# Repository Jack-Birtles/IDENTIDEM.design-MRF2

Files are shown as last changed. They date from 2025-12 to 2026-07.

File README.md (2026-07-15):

# IDENTIDEM.design M(edium Format) (R)ange(F)inder Two (MRF2)

Build Guide (https://www.youtube.com/watch?v=_sIWXoqOFIU)

MRF2 is version two of an open hardware / open firmware medium-format rangefinder camera for **Mamiya Press / Universal Press lenses**. It combines custom PCBs, ESP32-S3 firmware, LiDAR-based lens coupled focusing, dual OLED displays, and printed mechanical parts so you can build a fully featured medium-format shooter with configurable lens profiles and film formats.

It is based on the [Panomicron Thulium](https://www.panomicron.com/thulium) designed by Oscar Oweson, has been heavily modified, but has kept the best ideas from that camera.

Keep checking back regularly as I keep making improvements as I use my own copy of this camera. 
You can [support me on Patreon](https://patreon.com/IDENTIDEMdesign), or just show me your builds and the photos you're making with the camera!

## Repo at a Glance

- `Firmware/` – ESP32-S3 Arduino firmware (full details in `Firmware/README.md`)
- `PCBs/` – KiCad projects + production Gerbers, in two supported revisions (see **Which board version?** below):
  - `PCBs/v2.0/` (MRF-Pro-v8) – adds a dedicated low-noise LiDAR regulator on the breakout, and reworks the main board's FPC power delivery and switch: v1's FPC pins weren't wired to a real power rail at all (one was a spare Feather GPIO); v2 fixes that and adds full deterministic shutdown.
  - `PCBs/v1.0/` (MRF-Pro-v7.5) – simpler boards; great for short-range and landscape use.
  - Each revision holds `Main PCB/` (main board) and `Breakout/` (sensor breakout) sub-folders.
- `3MF/` – Print-ready 3MF files organized by part type (body, accessories, masks, fine parts)
- `STEP & F3D/` – Full assembly CAD (`MRF2-complete.f3d`) and shared STEP export (`MRF2-complete.step`)
- `OrcaSlicer/` – Slicer project files/profiles for printing

## Documentation Index

- `Documentation/flash-firmware/README.md` – Building and flashing the firmware on macOS, Linux, and Windows (VS Code or CLI)
- `Documentation/web-updater/README.md` – GitHub Pages browser updater architecture and deployment
- `Documentation/user-manual/USER_MANUAL.md` – On-device UI and calibration user manual
- `Documentation/wiring/README.md` – Power-switch/buttons and breakout-to-LiDAR harness wiring diagrams, for both board revisions
- `Firmware/README.md` – Firmware architecture, configuration, and CLI build commands

## Camera Features

- "LiDAR" distance measurement for accurate focus
- Dual OLED UI: 128×128 main in-viewfinder display + 128×32 external status display
- Light meter & exposure calculation for multiple ISO values
- Lens coupled via a high-accuracy linear position sensor
- Electronic frame counting using a rotary encoder
- Battery monitoring and on-device configuration, like in-camera lens calibration

## Which board version: v1 or v2?

Two board revisions are supported, and **the latest firmware runs on both, unchanged** — there are no board-specific builds, pin maps, or config flags. Connectors, sensors, displays, optics, printed parts, and the main board's component placement and outline are common to both, **but the main board's LiDAR power delivery was significantly reworked, alongside the breakout hardware.** On v1, schematic capture found the FPC connector's power pins weren't wired to a real power rail at all — pin 1 was tied to a Feather **GPIO (D11)** and pin 6 to an undefined private net, so the Feather's actual 3.3 V never reached the breakout, likely worsening the laser-pulse brownout this respin fixes. v2 corrects it: pin 1 now carries real `VBAT`, pin 6 carries a properly gated `3.3OUT`, and the GPIO is freed. Choose by the LiDAR range you need:

| | **v1 — MRF-Pro-v7.5** (`PCBs/v1.0/`) | **v2 — MRF-Pro-v8** (`PCBs/v2.0/`) |
| --- | --- | --- |
| Breakout | Bare — just the three connectors | Same connectors **+ a dedicated LiDAR LDO** (8 extra SMD parts) |
| FPC power delivery (main board) | Pin 1 wired to a Feather **GPIO (D11)**, pin 6 an undefined private net — the Feather's regulated 3.3 V never actually reached the FPC | Pin 1 carries real **`VBAT`**, pin 6 carries a gated, switched **`3.3OUT`** — the breakout's LDO finally gets the power path it needs |
| LiDAR power | Shared Feather 3.3 V rail, no decoupling at the sensor | Isolated low-noise 3.3 V regulated **at the sensor** (TLV75533 off VBAT) |
| LiDAR range | Good up close and at landscape distance; **falls off at mid distance and in bright ambient** | **Full rated range indoors and in shade; direct sun still caps range** (~3 m on a sunlit target — a sensor optics limitation, not power-related; no board revision or firmware fixes it) |
| Power switch (main board) | Basic on/off — single shared 3.3 V net through J4 | Reworked **J4 DPDT**, two independent poles (gate `3.3OUT`; hold MCU `EN` low) for full deterministic shutdown (≤1 µA off) — same connector, board outline, and component placement, traces rerouted |
| Build effort | **Lowest** — breakout is a bare board, no SMD assembly | A bit more — breakout is an SMD assembly job (JLCPCB BOM/CPL provided) |
| Best for | Portraits ~1–3 m and landscapes; the cheapest, easiest build | Full-range focus indoors and in shade, better (not unlimited) in direct sun — the fuller-featured build |

- **Pick v1** for the simplest, cheapest build if you mostly shoot within a few metres or at landscape distances. Its LiDAR range can still be improved with the [hand-solder decoupling stopgap](Documentation/hardware-errata/lidar-stage1-decoupling.md), a v1-only remedy that v2 builds in.
- **Pick v2** for the sensor's full distance range indoors and in shade, deterministic power-off, and a main board that actually delivers real power to the LiDAR breakout, at the cost of the extra SMD parts on the breakout. Direct bright sun still caps range on either revision — that's the sensor fighting solar infrared at its own wavelength, not a supply problem this board fixes. The [LiDAR power errata](Documentation/hardware-errata/README.md) explains the why, and [field test protocol](Documentation/hardware-errata/lidar-field-test.md) covers all three lighting conditions including direct sun.

Building either? See the **[wiring guide](Documentation/wiring/README.md)** for the power-switch/buttons harness and breakout-to-LiDAR harness diagrams, per revision.

## Build Path (high level)

1. **Order PCBs**: Pick your version (see [Which board version?](#which-board-version-v1-or-v2)), then upload the Gerbers from that revision's `Main PCB/Gerber` and `Breakout/Gerber` folders — the `.gbrjob` files go straight to most fabs. For v2, the breakout is also an assembly job (the LDO SMD parts); its JLCPCB BOM/CPL live in `PCBs/v2.0/Breakout/JLCPCB/`.
2. **Assemble electronics**: Populate the main and breakout boards with the BoM below (through-hole and SMT mix), attach the Feather ESP32-S3, and wire the displays/sensors via STEMMA QT/Qwiic where applicable.
3. **Print the body**: Slice/print the 3MF models (see `3MF/` and any profiles in `OrcaSlicer/`). Fit tolerances may depend on your printer and material.
4. **Load firmware**: Follow `Documentation/flash-firmware/README.md` (macOS/Linux/Windows, VS Code or CLI), then run first-time calibration.
5. **Integrate**: Install the PCBs and displays into the printed parts, route wiring, and verify focus/meters on the bench before loading film.

## Bill of Materials

Marketplace listings (Amazon/AliExpress) change frequently. Treat those links as examples and verify specs before ordering.

### Electronics

| Item | Qty | Notes | Example sources |
| --- | --- | --- | --- |
| Feather ESP32-S3 (Adafruit 5477) | 1 | Main MCU, MAX17048 fuel gauge, 4MB flash / 2MB PSRAM | [Adafruit](https://www.adafruit.com/product/5477) |
| MRF2 Main PCB | 1 | Use Gerbers in your chosen revision's `Main PCB/Gerber` (`PCBs/v2.0/` or `PCBs/v1.0/`) | Any fab |
| MRF2 Breakout PCB | 1 | Use Gerbers in your chosen revision's `Breakout/Gerber`. **v2 breakout is an SMD assembly job** (see the LDO parts below) | Any fab |
| B-type 8-pin FPC ribbon cable | 1 | Links main PCB to breakout | [Amazon](https://www.amazon.co.uk/sourcing-map-Ribbon-Flexible-Printer/dp/B0F4K1KMKR/) |
| 8-pin JST-SH cable | 1 | For power switch and buttons, 10cm should be plenty | [AliExpress Search](https://www.aliexpress.com/w/wholesale-8-pin-jst%252525252dsh-cable.html) |
| 6-pin JST-SH cable | 1 | Connect the LiDAR sensor to the breakout board - some cutting and soldering needed on the connector supplied with the sensor | [AliExpress Search](https://www.aliexpress.com/w/wholesale-6-pin-jst%252525252dsh-cable.html) |
| LiDAR DTS6012M | 1 | Distance sensing | [AliExpress search](https://www.aliexpress.com/wholesale?SearchText=DTS6012M+UART) |
| 404R10KL1.0 Linear-position sensor | 1 | Lens position sensor | [Newark](https://www.newark.com/tt-electronics-bi-technologies/404r10kl1-0/linear-motion-potentiometer-10kohm/dp/15M2426) |
| Light sensor BH1750 breakout (Adafruit 4681) | 1 | Lux readings | [Adafruit](https://www.adafruit.com/product/4681) |
| IMU MPU6050 breakout (Adafruit 3886) | 1 | Orientation | [Adafruit](https://www.adafruit.com/product/3886) |
| ADC ADS1015 breakout (Adafruit 1083) | 1 | Lens position | [Adafruit](https://www.adafruit.com/product/1083) |
| STEMMA QT Rotary Encoder (Adafruit 5880) | 1 | Film advance tracking | [Adafruit](https://www.adafruit.com/product/5880) |
| 1.12" 128×128 SH1107 OLED (Adafruit 5297) | 1 | Main display | [Adafruit](https://www.adafruit.com/product/5297) |
| 128×32 SSD1306 OLED (I2C) | 1 | External status display | [AliExpress search](https://www.aliexpress.com/w/wholesale-128x32-oled-display-ssd1306.html) |
| JST-SH/Qwiic/STEMMA QT cables | 6-8 (extras if you want to shorten / modify) | I2C daisy-chain and encoder | [Adafruit](https://www.adafruit.com/product/4210) |
| LiPo cell (3.7V, 820mAh) - 44 x 30.5 x 6.8 mm | 1 | **CHECK POLARITY** | [Amazon](https://www.amazon.co.uk/dp/B082152887) |
| 8mm momentary button | 2 | Select buttons | [Amazon](https://www.amazon.co.uk/dp/B07S1MNB8C) |
| 6mm DPDT slide switch | 1 | Power switch | [Amazon](https://www.amazon.co.uk/dp/B07H9VPK1J) |

### Components for custom PCBs — connectors (both versions)

The same connectors populate v1 and v2:

| Item | Qty | Notes | Example sources |
| --- | --- | --- | --- |
| 0.5mm pitch 8-pin FPC connector (FPC-05F-8PH20, C2856797) | 2 | One on the main PCB, one on the breakout | [JLCPCB](https://jlcpcb.com/partdetail/XUNPU-FPC_05F8PH20/C2856797) |
| SH 1.0mm 8-pin connector (ZX-SH1.0-8PWT, C7430450) | 1 | Main board J4 — power switch and buttons | [JLCPCB](https://jlcpcb.com/partdetail/Megastar-ZX_SH1_08PWT/C7430450) |
| SH 1.0mm 6-pin connector (ZX-SH1.0-6PWT, C7430448) | 1 | Breakout J7 — LiDAR sensor | [JLCPCB](https://jlcpcb.com/partdetail/Megastar-ZX_SH1_06PWT/C7430448) |
| SH 1.0mm 4-pin connector (ZX-SH1.0-4PWT, C7430446) | 1 | Breakout J6 — STEMMA QT | [JLCPCB](https://jlcpcb.com/partdetail/Megastar-ZX_SH1_04PWT/C7430446) |

### v2 breakout only — dedicated LiDAR regulator

These SMD parts populate the v2 breakout's LDO (the extra cost/effort over v1). **v1's breakout has none of these** — it just carries the connectors above. Full design background is in the [LiDAR power errata](Documentation/hardware-errata/README.md).

| Ref | Part | LCSC | Role |
| --- | --- | --- | --- |
| U1 | TLV75533 LDO, SOT-23-5 | C404027 | Dedicated 3.3 V regulator for the LiDAR |
| Cin1 | 1 µF, 0402 | C52923 | LDO input decoupling |
| Cin2 | 10 µF, 0805 | C15850 | LDO input bulk |
| C1 | 47 µF, 1206 | C96123 | Laser-rail bulk (at the sensor's laser pin) |
| C2 | 1 µF, 0603 | C15849 | LDO output stability |
| C3 | 100 nF, 0402 | C1525 | High-frequency bypass |
| FB1 | 0 Ω jumper, 0805 | C17477 | Splits the logic/laser rails (fit a ferrite later if needed) |
| R1 | 100 kΩ, 0402 | C25741 | LDO enable pulldown (clean power-off) |

### Hardware

| Item | Qty | Notes | Example sources |
| --- | --- | --- | --- |
| Heat-set inserts | as needed | M2x4 & M3x4 | Local fasteners supplier |
| Countersunk screws | as needed | M2x4, M2x6, M3x6, M3x8 countersunk screws | Local fasteners supplier |
| M3x6 thumb screw | 1 | To hold the door closed | Local fasteners supplier |
| Steel rod - for door hinge | 1 | Cut to length: ~82mm | [Amazon](https://www.amazon.co.uk/HXJDAM-Stainless-Steel-Round-Diameter/dp/B0D2V6WB1Y) |
| 2-turn door handle spring | 1 | For advance lever auto-return | [Amazon](https://www.amazon.co.uk/dp/B076VRBT4M) |
| CSK8PP one-way bearing / sprag clutch | 1 | For advance lever, make sure inner and outer are keyed | [AliExpress Search](https://www.aliexpress.com/w/wholesale-CSK8PP.html) |
| Cold shoe | 1 | Mount on top | [Amazon](https://www.amazon.co.uk/Anwenk-Adapter-Bracket-Standard-Monitor/dp/B01MD29V3X) |
| 20x5x2mm bar magnets | as needed | 1 for the body, 1 for each mask you print | [Amazon](https://amzn.eu/d/ejitdei) |
| 5x2mm round magnets | 2 | 1 for the body, 1 for the key | [Amazon](https://www.amazon.co.uk/100PCS-Magnets-Neodymium-Whiteboards-Picture/dp/B09H2W3TQZ) |

### Optics

| Item | Qty | Notes | Example sources |
| --- | --- | --- | --- |
| 20.0mm Dia. x 70.0mm FL plano-convex lens (PCX) | 1 | Rear viewfinder lens | [Edmund Optics](https://www.edmundoptics.co.uk/p/200mm-dia-x-700mm-fl-uncoated-plano-convex-lens/2705) |
| 25.0mm Dia. x -25 FL plano-concave lens (PCV) | 1 | Front viewfinder lens | [Edmund Optics](https://www.edmundoptics.co.uk/p/250mm-dia-x25-fl-uncoated-plano-concave-lens/5542/) |
| 30x30x1.1mm 50R/50T beam splitter | 1 | Sits between front and rear optics | [AliExpress Search](https://www.aliexpress.com/w/wholesale-30x30x1.1-50R%25252F50T-beam-splitter.html) |

## Cost Estimate (ballpark)

Assumes single-quantity retail buys (Adafruit/Amazon/AliExpress), optics from Edmund Optics, and a rough USD/GBP conversion; excludes shipping/VAT/import and assembly labor.

- Electronics (MCU, sensors, displays, cables, LiPo, switches): ~$125 / ~£100
- PCB share (DIY assembly; amortized per build): ~$10 / ~£6  \[full 5× PCB batch ~ $35 / £28\]
- Hardware/fasteners/mech bits: ~$25 / ~£20
- Optics (lenses + beam splitter): ~$115 / ~£90
- Printed parts material: ~$25 / ~£20
- Rough per-build total: ~$300 / ~£235 (add shipping/taxes and any PCB batch overhead you keep)

## CAD & Printed Parts

- Full assembly in `STEP & F3D/MRF2-complete.f3d` (Fusion 360) and `MRF2-complete.step` (generic).
- Print-ready 3MFs are grouped by function under `3MF/`. Use provided slicer profiles in `OrcaSlicer/` as a starting point and tweak for your printer/material.

## PCB Notes

- Open the KiCad projects for your revision: **v2** `PCBs/v2.0/Main PCB/KiCAD/MRF-Pro-v8.kicad_pro` + `PCBs/v2.0/Breakout/KiCAD/MRF-Pro-v8-breakout.kicad_pro`; **v1** `PCBs/v1.0/Main PCB/KiCAD/MRF-Pro-v7.5.kicad_pro` + `PCBs/v1.0/Breakout/KiCAD/MRF-Pro-v7.5-breakout.kicad_pro`.
- Fabrication: the provided Gerber sets include copper, mask, paste, silkscreen, drills, and a `.gbrjob` for auto-detection at most PCB fabs.
- Revs: `PCBs/v2.0/` (`MRF-Pro-v8`) adds the dedicated LiDAR LDO on the breakout and reworks the main board's LiDAR power delivery: v1's FPC pin 1 was wired to a spare Feather GPIO (D11) rather than a real rail and pin 6 was an undefined private net, so the Feather's 3.3 V never reached the breakout; v2 rewires them to `VBAT`/`3.3OUT` and splits the J4 switch into a DPDT for full deterministic shutdown (same component placement and board outline, traces rerouted). `PCBs/v1.0/` (`MRF-Pro-v7.5`) is the simpler, unfixed original design. See [Which board version?](#which-board-version-v1-or-v2) and the [LiDAR power errata](Documentation/hardware-errata/README.md) for the design background.

## Firmware

Firmware source and build instructions live in `Firmware/README.md`. PlatformIO is used for builds/flash/monitoring. Calibrate lenses and film formats after first flash.

For browser-based updates, use the GitHub Pages firmware updater:
`https://update.mrf2.com/`

If a user reports the updater hanging (for example at "Preparing installation"), enable hidden debug mode by adding `?debug=1`:
`https://update.mrf2.com/?debug=1`

Then:
1. Reproduce the issue.
2. Click **Copy Debug Report**.
3. Send the JSON report back for diagnosis.

## License

Firmware and design files are released under the GNU GPL v3.0 (see `LICENSE`).

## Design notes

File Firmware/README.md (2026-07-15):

# MRF2 Firmware - Medium Format Rangefinder System

**Version**: 10.7.0
**Platform**: ESP32-S3  
**Framework**: Arduino (PlatformIO)

## Overview

MRF2 Firmware drives the ESP32-S3-based medium format LiDAR rangefinder camera. For the hardware overview, PCBs, CAD, and BoM, see the root `README.md`; this document focuses on firmware architecture, configuration, and pin-level details.

## Hardware Interface (pins)

- **LiDAR Serial**: Hardware Serial 2 at 921600 baud
- **I2C Bus**: All I2C devices share the default I2C bus
- **Lens Position**: ADS1015 channel 1
- **Left Button**: GPIO 9 (internal pull-up)
- **Right Button**: GPIO 10 (internal pull-up)
- **Status LED**: Seesaw NeoPixel at address 0x36

## Software Dependencies

The project uses PlatformIO with the following libraries (declared in `platformio.ini`):

- Adafruit SSD1306 (2.5.17)
- Adafruit GFX Library (1.12.6)
- U8g2_for_Adafruit_GFX (1.8.0)
- Adafruit MAX1704X (1.0.3)
- DTS6012M_UART (3.0.0)
- BH1750 (1.3.0)
- Bounce2 (2.72)
- Adafruit SH110X (2.1.14)
- Adafruit seesaw Library (1.7.9)
- Adafruit ADS1X15 (2.6.2)
- Adafruit MPU6050 (2.2.9)
- Adafruit BusIO (1.17.4)
- Adafruit Unified Sensor (1.1.15)

Versions are pinned exactly so CI tag rebuilds reproduce the shipped binaries; bump them deliberately in `platformio.ini`.

## Project Structure

```
Firmware/
├── include/          # Header files
│   ├── mrfconstants.h    # System constants and configuration
│   ├── hardware.h        # Hardware initialization declarations
│   ├── globals.h         # Global variables and state
│   ├── lenses.h          # Lens profiles and calibration data
│   ├── formats.h         # Film format definitions
│   ├── interface.h       # UI drawing functions
│   ├── interface_layout_constants.h # Shared UI layout constants
│   ├── interface_menu_helpers.h # Config menu drawing helpers
│   ├── helpers.h         # Utility functions
│   ├── prefs_keys.h      # All NVS keys (guarded by the native suite)
│   ├── cyclefuncs.h      # Cycling and selection functions
│   ├── setfuncs.h        # Sensor reading and setting functions
│   ├── inputs.h          # Input handling functions
│   ├── activity.h        # Shared activity/sleep state helpers
│   ├── loop_runtime.h    # Runtime scheduler and awake/sleep loop orchestration
│   ├── sleep_timeout_logic.h # Sleep/idle timeout mode tables
│   ├── boot_animation_logic.h # Boot animation frame geometry
│   ├── formatting_logic.h # Shared display formatting helpers
│   ├── frameline_layout_logic.h # Viewfinder frameline geometry
│   ├── lidar_logic.h     # LiDAR fusion and correction logic
│   ├── lidar_recovery_logic.h # LiDAR error recovery state machine
│   ├── lidar_recovery_actions.h # Recovery attempt sequence (host-testable)
│   ├── lens_logic.h      # Lens sensor-to-distance mapping logic
│   ├── lens_spike_logic.h # Lens ADC spike filter
│   ├── film_counter_logic.h # Film counter interpolation logic
│   ├── lightmeter_logic.h # Shutter speed formatting logic
│   ├── ui_signature_logic.h # Redraw-skip signature hashing
│   ├── calibration_logic.h # Lens calibration sample validation
│   └── prefs_migration_logic.h # Preferences schema migration
├── src/              # Implementation files
│   ├── main.cpp          # Main program logic
│   ├── hardware.cpp      # Hardware instances
│   ├── globals.cpp       # Global variable definitions
│   ├── lenses.cpp        # Lens data arrays
│   ├── formats.cpp       # Film format data
│   ├── interface.cpp     # UI rendering implementation
│   ├── interface_config_screens.cpp # Setup/calibration/health screens
│   ├── helpers.cpp       # Helper function implementations
│   ├── activity.cpp      # Activity and sleep state implementation
│   ├── loop_runtime.cpp  # Runtime scheduler and task execution pipeline
│   ├── sleep_timeout_logic.cpp # Sleep/idle timeout mode tables
│   ├── cyclefuncs.cpp    # Cycling logic
│   ├── setfuncs.cpp      # Sensor orchestration
│   ├── boot_animation_logic.cpp # Boot animation frame geometry
│   ├── formatting_logic.cpp # Shared display formatting helpers
│   ├── frameline_layout_logic.cpp # Viewfinder frameline geometry
│   ├── lidar_logic.cpp   # LiDAR processing pipeline
│   ├── lidar_recovery_logic.cpp # LiDAR error recovery state machine
│   ├── lens_logic.cpp    # Lens distance estimation
│   ├── lens_spike_logic.cpp # Lens ADC spike filter
│   ├── film_counter_logic.cpp # Film counter estimation
│   ├── lightmeter_logic.cpp # Light-meter/shutter conversion
│   ├── ui_signature_logic.cpp # Redraw-skip signature hashing
│   ├── calibration_logic.cpp # Lens calibration sample validation
│   ├── prefs_migration_logic.cpp # Preferences schema migration
│   └── inputs.cpp        # Button and encoder handling
├── test/             # Native (host) unit test suites
├── test_stubs/       # Host-build stubs for hardware headers
├── platformio.ini    # PlatformIO configuration
└── README.md         # This file
```

## Firmware Architecture

### Main Program Flow

1. **Setup Phase** (`setup()` in `src/main.cpp`)
   - Disable WiFi/Bluetooth for power saving
   - Load saved preferences
   - Initialize all hardware components
   - Show "Initialising..." progress bar on main display with a label naming each peripheral group as it comes up
   - Configure displays and show boot screen on external display
   - Start sensor readings

2. **Main Loop** (`loop()` in `src/main.cpp`)
   - Delegate runtime scheduling to `runLoopRuntimeIteration()` in `src/loop_runtime.cpp`
   - Check configurable sleep timeout (`Off`, `15s`, `30sec`, `1m`, `1m30s`, `2m`; default `1m`)
   - Apply adaptive sensor polling and state-aware UI redraws to reduce idle power draw
   - Process button inputs
   - Update film counter
   - Read sensors (distance, light, battery)
   - Update appropriate UI based on mode

### Operating Modes

- **Main Mode**: Normal operation with rangefinder display
- **Config Mode**: Settings and configuration menu
- **Setup Root Menu**: film submenu, lens submenu, light-meter submenu, UI settings submenu, system health screen, reset, and exit. Film, Lens, and Meter entries show their active value inline (e.g. `Film: 6x7 >`)
- **Film Submenu** (`Setup > Film`): format selection, frame-1 offset, and frame-spacing offset
- **Lens Submenu** (`Setup > Lens`): Lens profile, parallax correction toggle, and lens calibration entry
- **Light Meter Submenu** (`Setup > Meter`): ISO, EV compensation, smoothing strength, EV readout toggle
- **UI Settings Submenu** (`Setup > UI`): landscape/portrait horizon trims, sleep timeout, and LiDAR idle timeout
- **Health Screen**: firmware/prefs status, LiDAR error and recovery counters, idle timer, Retry LiDAR option when LiDAR failed to initialise, and Factory Reset (long-press R)
- **Calibration Mode**: Lens calibration interface
- **Sleep Mode**: Low-power state with minimal display

### Key Features Implementation

#### Distance Measurement
- DTS6012M v2 provides primary and secondary returns per sample
- Confidence scoring combines data quality, intensity, ambient sunlight ratio (SNR), temporal consistency, and lens-position prior
- Fallback candidate path accepts returns at all ranges when primary filtering rejects, with conservative confidence cap
- Two-stage correction: library scale/offset in mm, then curve/residual correction in cm
- Confidence-aware temporal smoothing (accept, blend, or hold previous reading)
- In Main mode, LiDAR idle standby timeout is user-configurable (`Off`, `15s`, `30sec`, `1m`, `1m30s`, `2m`; default `1m`)
- While LiDAR is in idle standby, the distance readout shows `Zzz`
- Distance display uses `cm` below `1m`, two decimal places from `1m` to below `2m` (e.g. `1.85m`), one decimal place at `2m` and above, `<15cm` near clamp, `Inf.` above `10.5m` or when far-range signal is lost
- Range: 5cm to 18m

#### Light Metering
- Continuous lux readings from BH1750
- Automatic shutter speed calculation
- ISO range: 50-6400
- Aperture support for lens profiles
- EV compensation control (+/- in 1/3-stop steps)
- Smoothing control (`Off`, `Low`, `Medium`, `High`)

#### Lens System
- Mamiya Press / Universal Press lenses
- Support for multiple lens profiles
- Position sensing via ADC
- Lens-specific calibration curves (up to 10 points, depending on lens)
- Automatic distance correlation

#### Film Management
- Multiple format support (PANO, 3x6, 6x4.5, 6x6, 6x7, 9x3, 6x9)
- Frame counter with progress tracking
- Format-specific frame lines on display

#### Level Aid
- Horizon line with accelerometer-based tilt compensation
- Automatic landscape/portrait orientation handling
- Per-orientation horizon trim controls (`Horizon Landscape`, `Horizon Portrait+`, `Horizon Portrait-`) in `2.5deg` steps (`-30deg..+30deg`)

## Building and Flashing

For the step-by-step build and flash workflow on macOS, Linux, and Windows (VS Code or CLI), see `Documentation/flash-firmware/README.md`.

### CLI Build Commands
```bash
# Build the project
pio run

# Upload to board
pio run --target upload

# Monitor serial output
pio run --target monitor
```

### Core Logic Regression Tests
```bash
# Runs focused host-side tests for:
# frame counter, LiDAR fusion/formatting,
# lens distance calibration logic, and light meter output.
pio test -e native_core_tests
```

## Configuration

### Constants (mrfconstants.h)

- `FWVERSION`: Firmware version string
- `DEFAULT_SLEEP_TIMEOUT_MODE` / `SLEEP_TIMEOUT_MODE_*`: Auto-sleep options (`Off`, `15s`, `30sec`, `1m`, `1m30s`, `2m`; default `1m30s`)
- `DEFAULT_LIDAR_IDLE_TIMEOUT_MODE`: Awake-main LiDAR standby timeout default (`1m`)
- `DEFAULT_RETICLE_OFFSET_X` / `DEFAULT_RETICLE_OFFSET_Y`: Reticle position offsets (default `-5`, `0`; range `-20` to `+20` px)
- `DEFAULT_BRIGHTNESS_AUTO` / `DEFAULT_BRIGHTNESS_MANUAL_PCT` / `DEFAULT_BRIGHTNESS_AUTO_TOP_PCT`: Display brightness defaults (Auto mode on; manual level `100%`; auto top `100%`)
- `BRIGHTNESS_MANUAL_MIN_PCT` / `BRIGHTNESS_MANUAL_STEP_PCT`: Manual brightness range (`5%`–`100%` in `5%` steps)
- `BRIGHTNESS_AUTO_TOP_MIN_PCT` / `BRIGHTNESS_AUTO_TOP_STEP_PCT`: Auto top brightness range (`50%`–`100%` in `10%` steps)
- `BRIGHTNESS_AUTO_LUX_MAX`: Lux ceiling for auto brightness scaling (`500 lux`)
- `DEFAULT_SHOW_HORIZON_LINE`: Horizon line visibility default (`true`)
- `DISTANCE_NEAR_THRESHOLD_CM` / `DISTANCE_DECIMAL_PLACES_NEAR`: Two-decimal-place threshold and precision (`200cm`, `2` places)
- `SMOOTHING_WINDOW_SIZE`: Filter window (13 samples)
- `LENS_INF_THRESHOLD`: Infinity focus threshold
- `LIDAR_LIBRARY_DISTANCE_SCALE`: LiDAR library distance scaling factor
- `LIDAR_LIBRARY_DISTANCE_OFFSET_MM`: LiDAR library distance offset in mm
- `LIDAR_NO_DATA_TIMEOUT_MS`: Hold timeout before showing placeholder (`1000ms`)
- `LIDAR_FAR_SIGNAL_LOSS_CM`: Show `Inf.` instead of `...` when signal lost above this distance (`300cm`)
- `LIDAR_FUSION_MIN_INTENSITY`: Near-range minimum intensity gate (`40`)
- `LIDAR_SNR_PERMILLE_HARD_REJECT`: SNR hard-reject floor (`8‰`)
- `LIDAR_CONFIDENCE_HIGH` / `LIDAR_CONFIDENCE_MEDIUM`: Confidence thresholds for smoothing behavior
- `LIDAR_CAL_CUTOFF_CM` / `LIDAR_CAL_REF_RAW_CM` / `LIDAR_CAL_REF_TRUE_CM`: Near-range calibration curve parameters
- `LIDAR_RESIDUAL_DIST_CM` / `LIDAR_RESIDUAL_DELTA_CM`: Piecewise residual correction table

### Preferences Storage

The system saves:

- Selected lens profile
- Film format selection
- Frame 1 offset and frame spacing offset
- ISO setting
- Aperture setting
- Film counter and encoder position
- Parallax correction toggle state
- Sleep timeout mode
- LiDAR idle timeout mode
- UI horizon trim offsets (landscape, portrait `P+`, portrait `P-`)
- Horizon line visibility
- Display brightness mode (Auto/Manual), auto top brightness, manual brightness level
- Reticle offset X/Y
- Light-meter EV/smoothing/readout settings
- Lens calibration data

## Troubleshooting

### Display Issues

- Ensure I2C addresses match your hardware (0x3D for main, 0x3C for external)
- Check wire connections

### LiDAR Communication

- Check RX/TX connections
- Ensure adequate power supply

### Button Response

- Check debounce timing (5ms default)
- Test with serial monitor

## License

Released under the GNU General Public License v3.0 (see `LICENSE` in the repo root or this directory). Portions are based on the LRF45 CircuitPython code; please retain upstream notices where applicable.

## Contributing

See the root `README.md` for repo-wide contributing guidance. For firmware changes, include a clear description, update docs, and test on hardware where possible.

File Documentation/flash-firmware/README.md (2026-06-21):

# Flashing the MRF2 Firmware

This guide walks through building and flashing the firmware on **macOS, Linux, and Windows**. It assumes you have the repo checked out and want to flash the `Firmware/` project.

Two paths are covered:

- **VS Code + PlatformIO IDE** (recommended for most builders): sections 1 through 7.
- **Command line (PlatformIO Core)**: the CLI section near the end.

If you would rather not install anything, use the browser-based updater instead:
`https://update.mrf2.com/`

The MRF2 board is an Adafruit Feather ESP32-S3. It uses the ESP32-S3's **native USB**, so there is **no CP210x/CH340 USB-to-serial chip and no vendor driver to install** on any operating system. The notes below cover the few things that do differ per OS: serial port permissions on Linux, COM-port behavior on Windows, and the bootloader recovery sequence.

## Prerequisites (all platforms)
- VS Code installed
- PlatformIO IDE extension installed
- A **USB-C data cable** (charge-only cables will not enumerate a serial port)
- MRF2 powered on

### Per-platform setup notes

#### macOS

- No driver needed. The board appears as `/dev/tty.usbmodem*`.

#### Windows (10/11)

- No driver needed. Windows installs the built-in USB CDC (serial) driver automatically the first time you plug the board in; it appears as a `COMx` port in Device Manager under "Ports (COM & LPT)".
- If the port never appears, see the Windows note in Troubleshooting.

#### Linux

- No driver needed, but your user must have permission to access the serial device, and `ModemManager` can interfere with uploads. Both are one-time fixes; see [Linux serial port access](#linux-serial-port-access) below before your first upload.

## 1) Install VS Code extensions
1. Open VS Code.
2. Open the Extensions view (`Cmd/Ctrl+Shift+X`).
3. Install **PlatformIO IDE**.
4. (Optional) Install **Espressif IDF**. PlatformIO does not require it, but it can be useful for ESP tooling and serial utilities.

## 2) Open the project in PlatformIO
1. Click the PlatformIO icon in the Activity Bar to open **PIO Home**.
2. Choose **Open Project**.
3. Select the `Firmware/` folder (the folder that contains `platformio.ini`).
4. Wait for PlatformIO to finish installing toolchains and dependencies.

## 3) Build the firmware
1. In the PlatformIO toolbar (bottom bar), click **Build** (checkmark icon).
2. Confirm the build completes without errors.

## 4) Connect and select the serial port
1. Switch on the MRF2 and connect it via USB-C.
2. In the bottom bar, click the **Serial Port** selector and choose **Auto** or the correct port.
   - macOS examples: `/dev/tty.usbmodem*`
   - Linux examples: `/dev/ttyACM0` (native USB) or `/dev/ttyUSB0`
   - Windows examples: `COM3`, `COM4`

## 5) Upload (flash)
1. Click **Upload** (right-arrow icon) in the PlatformIO toolbar.
2. Wait for the upload to finish.

If upload fails:
- Put the ESP32-S3 into bootloader mode: **hold BOOT**, tap **RESET**, then release BOOT and retry upload.
- Try a different USB-C cable or USB port.
- On Linux, confirm serial permissions (see below). On Windows, confirm the COM port appears in Device Manager.

## 6) Verify on device
1. Disconnect USB.
2. Power-cycle the MRF2.
3. The external display should show the firmware boot screen and version.

## 7) Serial monitor (optional)
1. Click **Monitor** (plug icon) in the PlatformIO toolbar.
2. Use **115200 baud** (matches `SERIAL_BAUD_RATE` in `Firmware/include/mrfconstants.h`).

---

## Linux serial port access

On most distributions the serial device is owned by the `dialout` group (Debian/Ubuntu) or `uucp` group (Arch/Fedora). If you are not a member, uploads and the monitor fail with "permission denied".

1. Find your distro's serial group and add yourself to it:
   ```bash
   # Debian / Ubuntu / Raspberry Pi OS
   sudo usermod -aG dialout "$USER"

   # Arch / Fedora / openSUSE
   sudo usermod -aG uucp "$USER"
   ```
2. **Log out and back in** (or reboot) for the group change to take effect.
3. Verify the device shows up after plugging in the board:
   ```bash
   ls -l /dev/ttyACM* /dev/ttyUSB*
   ```

**ModemManager grabbing the port:** on desktop Linux, `ModemManager` may probe the board the moment it enumerates and cause upload timeouts. If uploads intermittently fail right after plugging in, either wait a few seconds before uploading, or stop ModemManager:
```bash
sudo systemctl stop ModemManager     # for this session
sudo systemctl disable ModemManager  # permanently, if you do not use cellular modems
```

PlatformIO can also install the official udev rules for you if the port is not detected. See `https://docs.platformio.org/en/latest/core/installation/udev-rules.html`.

---

## Command line (PlatformIO Core)

Use this if you prefer the terminal or are flashing on a headless machine. All commands assume your working directory is `Firmware/` (or pass `-d Firmware` from the repo root).

### Install PlatformIO Core

PlatformIO Core needs Python 3.6+.

**macOS / Linux**
```bash
python3 -m pip install --user platformio
# then make sure ~/.local/bin is on your PATH, e.g. for bash/zsh:
export PATH="$HOME/.local/bin:$PATH"
```

**Windows (PowerShell)**
```powershell
py -m pip install --user platformio
# pio.exe lands in %APPDATA%\Python\PythonXY\Scripts; add it to PATH if `pio` is not found
```

Confirm the install:
```bash
pio --version
```

(Alternatively, install the **PlatformIO IDE** extension in VS Code and use its bundled `pio` from the PlatformIO Core CLI terminal, with no separate install needed.)

### Build, flash, monitor

```bash
# Build the firmware for the ESP32-S3
pio run -e adafruit_feather_esp32s3

# Flash a connected board (auto-detects the port)
pio run -e adafruit_feather_esp32s3 --target upload

# Open the serial monitor (115200 baud)
pio run -e adafruit_feather_esp32s3 --target monitor
```

To target a specific port, append `--upload-port`:
```bash
# Linux
pio run -e adafruit_feather_esp32s3 --target upload --upload-port /dev/ttyACM0
# Windows
pio run -e adafruit_feather_esp32s3 --target upload --upload-port COM4
# macOS
pio run -e adafruit_feather_esp32s3 --target upload --upload-port /dev/tty.usbmodem1101
```

List detected ports with `pio device list`.

### Host-side tests (no hardware required)

These run on your computer and do not touch the board, so they work the same on all three platforms:
```bash
pio test -e native_core_tests
```

---

## Troubleshooting
- **No serial port listed (all platforms)**: try a different cable (must be a data cable) or a different USB port.
- **No COM port on Windows**: open Device Manager and watch "Ports (COM & LPT)" while plugging the board in. If it appears under "Other devices" with a warning, unplug, wait, and replug; if it still fails, try another USB port or cable. No vendor driver is required for this board.
- **Permission denied on Linux**: add your user to the serial group and re-login (see [Linux serial port access](#linux-serial-port-access)).
- **Upload starts but fails to connect**: hold **BOOT**, tap **RESET**, release **BOOT**, then retry the upload.
- **Build errors on first run**: let PlatformIO finish downloading toolchains, then retry.
- **Upload times out intermittently on Linux**: stop `ModemManager` (see above).

For the firmware architecture and configuration reference, see `Firmware/README.md`.

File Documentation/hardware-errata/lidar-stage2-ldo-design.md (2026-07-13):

# LiDAR dedicated regulator — design (Stage 2)

> **CURRENT — Stage 2 · the plan to follow.** Supersedes the Stage-1 decoupling-only respin ([lidar-stage1-decoupling.md](lidar-stage1-decoupling.md)). Build steps: [lidar-stage2-ldo-kicad-guide.md](lidar-stage2-ldo-kicad-guide.md). Start at the [errata index](README.md).

**Status: design locked; schematic capture complete on both boards (ERC clean); PCB layout complete and DRC-clean; main-board layout reworked (J4 power-switch nets renamed `3.3V`→`3.3IN` / `3V3_SW`→`3.3OUT`, now global labels; traces rerouted) and fab outputs re-plotted.** Tracked on beads issue `IDENTIDEM_design-MRF2-3z5`. Background and root cause: [lidar-stage1-decoupling.md](lidar-stage1-decoupling.md). Datasheets in [datasheets/](datasheets/).

## Goal

Give the DTS6012M a clean, stiff 3.3 V **at the sensor** that the pulsed laser cannot drag down, isolated from the ESP32-S3 / WiFi noise on the shared 3.3 V rail.

## Why this is being built now (no longer gated)

Originally gated on field data — build only if the Stage 1 decoupling did not restore range. Pulled forward because Stage 1 itself caused a regression: the **47 µF bulk added to the Feather 3.3 V rail slows the cold-start voltage ramp**, so the ESP32-S3 power-on reset releases `CHIP_PU` before the rail is stable. After a long time switched off (bulk fully discharged) a single switch-on fails to boot; a quick off/on (bulk still charged → fast ramp) works. That cold/warm asymmetry is the fingerprint.

Moving that bulk off the Feather rail and behind U1 onto `3V3_LIDAR` returns the MCU's reset rail to its known-good fast ramp and fixes the boot issue, while also delivering the original LiDAR power-integrity goal. One change closes both. A dedicated reset supervisor on `CHIP_PU` was considered for the boot symptom and dropped — relocating the bulk removes the cause outright.

3.3 V rail ramp on a cold versus warm start, showing the cold rail still near 2 V when the ESP32-S3 leaves reset

## Locked decisions

1. **LDO**, not a buck-boost.
2. **TI TLV75533** — chosen for its high PSRR / low noise. The input is the shared, noisy VBAT rail and the sensor is noise-sensitive, so rejection matters more than the marginal cost over an AP2112K.
3. **Keep the 8-pin FPC** — bring VBAT only; no power-enable GPIO line.
4. **Both sensor supply pins (laser + logic) on the one LDO output**, with an unpopulated ferrite to split the laser off later if measured noise warrants it (see [Components](#components-breakout)).

## Alternatives considered (and rejected)

1. **Feather 3.3 V rail, as-is** — the status quo this errata fixes. Bare sensor on a high-impedance FPC path, sharing the WiFi-bursting MCU rail: the laser pulse starves the undecoupled rail (short range) and shared noise erodes SNR.
2. **Feather rail + local decoupling only** (Stage 1) — fixes the delivery-path impedance but the bulk on the Feather rail slows cold-start and breaks the ESP32-S3 power-on reset (the regression). Self-defeating on this board.
3. **Feather rail + decoupling + a CHIP_PU reset supervisor** — solves boot, but leaves the sensor on the shared noisy rail (the DTS6012M manual itself advises an external regulator) and adds a part. The LDO fixes both range and boot with one change, so this is strictly worse.
4. **Dual-rail split** — laser (pin 1) on the LDO, logic (pin 2) back on the Feather rail. Rejected: risks a regulator fight if the module bridges the pins internally; creates a cross-domain differential across the die during the laser pulse and at power up/down (the LDO bulk holds pin 1 up while the Feather rail drops fast); and re-pollutes the logic supply the LDO exists to clean — for no load benefit (LDO is 500 mA vs ~80 mA draw). The sound version of this instinct is the optional laser-pin ferrite (single source), kept as a populate-option below.
5. **Sensor swap** — ST VL53L4CX/L1X are rail-friendly (onboard reg, low peak current) but top out at 4–6 m with a wide 15–27° cone, wrong for a pinpoint rangefinder; Benewake TF-Luna / TFmini-S keep the ~2° spot and 8–12 m but are 5 V parts needing a boost converter, plus a new UART driver, recalibration, and UI. Every swap trades the 3.3 V engineering for either a wide FoV or a 5 V supply *and* a firmware rewrite — none cheaper than finishing the LDO, which preserves 20 m and <2°.
6. **Buck-boost (TPS63xxx)** — would hold 3.3 V at any VBAT and kill the low-battery dropout, but it is a switcher next to a noise-sensitive receiver. Held as the [low-battery fallback](#accepted-limitation-low-battery) only; the LDO's dropout region is benign because the sensor's 3.0 V floor coincides with a flat LiPo.

## Architecture — regulate at the point of load

Power distribution: a DPDT power switch on J4 gates Feather 3.3 V onto the switched rail (FPC pin 6) and pulls Feather EN low in the off position; that switched 3.3 V feeds the MCU and I2C devices, and U1 takes always-present VBAT but slaves its enable to the switched rail, so the LiDAR rail is cut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

> The diagram above shows the high-level outcome (one switch kills MCU, I²C, and LiDAR); the J4 DPDT pole detail is in [Power switch](#power-switch--full-shutdown) below.

LiDAR LDO subcircuit: FPC J5 brings VBAT on pin 1 and switched 3.3 V on pin 6; VBAT feeds U1 input through Cin; pin 6 drives U1 EN and J6; U1 output 3V3_LIDAR carries C2/C3 and J7 pin 2, then FB1 to 3V3_LASER carrying C1 bulk and J7 pin 1

The breakout subcircuit above; the main-board power switch that gates it below.

J4 DPDT power switch shown in the off position: pole A has opened the link from Feather 3.3 V to the switched 3.3OUT rail on FPC pin 6, so the ADS1015 lens ADC, both OLEDs, the MPU, the seesaw rotary encoder, and the LiDAR LDO enable all lose power; pole B has closed Feather EN to GND, holding the 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

The regulator sits on the **breakout**, next to J7, so the clean rail is created at the sensor. The rough VBAT travels the lossy FPC/ribbon — voltage drop on a regulator *input* is harmless as long as it stays above dropout.

U1's **EN is slaved to the switched 3.3 V on FPC pin 6** (`3.3OUT`), not tied to IN. That switched rail is gated on the main board by a DPDT power switch wired to **J4** — see [Power switch](#power-switch--full-shutdown). So the camera power switch cuts the LiDAR rail too.

> **Net naming across the ribbon:** the one FPC pin-6 conductor is labeled `3.3OUT` on the main schematic (it is the switched output of the J4 DPDT) and `3.3V` on the breakout schematic (where it feeds J6 and U1 EN). Same wire, two local names — the boards are separate sheets joined only by the FPC. It is *not* an always-on rail on the breakout.

## Sensor side — DTS6012M connector and limits

From the sensor datasheet ([Docdt22 Rev1.2](datasheets/DTS6012M-Docdt22-Rev1.2.pdf), §1.1, §3), the 6-pin module connector **J7** is:

| J7 pin | Name | Net after change | Notes |
|---|---|---|---|
| 1 | 3V3_LASER | `3V3_LIDAR` | Internal laser supply. Datasheet: "may add extra filtering for cleaner power" — this is the pin the pulsed laser slams, so the 47 µF bulk belongs here. |
| 2 | 3V3 | `3V3_LIDAR` | Logic supply. Fed from the same clean LDO output. |
| 3 | UART_TX / I2C_SDA | unchanged | UART data, to FPC. |
| 4 | UART_RX / I2C_SCL | unchanged | UART data, to FPC. |
| 5 | UART_INT / I2C_INT | unchanged | **Interface-mode select, read at power-on**: grounded = UART, floating/pulled-up = I²C. We use UART, so pin 5 must stay tied low. Do not disturb this. |
| 6 | GND | GND | — |

Two hard constraints from §1.1 that this design depends on:

- **Supply abs-max is 3.6 V** (typ 3.3, min 3.0). VBAT is 3.0–4.2 V, so feeding the sensor from VBAT directly would over-volt and damage it — the **LDO is mandatory, not just a noise improvement**. The TLV75533 output (3.3 V ±1%, ≤~3.33 V) stays safely under 3.6 V.
- **Min supply is 3.0 V.** In LDO dropout near a flat battery the output follows VBAT down, but it does not fall below the sensor's 3.0 V floor until the LiPo itself is essentially empty — so the [accepted low-battery limitation](#accepted-limitation-low-battery) never drives the sensor out of spec before the camera is dead anyway.

The datasheet keeps the laser (pin 1) and logic (pin 2) supplies on separate pins so they *can* be filtered apart. We feed both from the one clean LDO output, joined by **FB1 (0 Ω by default)** — C1 (47 µF bulk) at pin 1, the LDO stability caps C2/C3 at U1 OUT. Fitting a ferrite at FB1 later isolates the laser pulse from the logic supply without a second regulator and without starving the LDO of its Cout (bead `-3z5` R4). See [Components](#components-breakout).

**Sequencing note (for firmware):** with EN slaved to the Feather 3.3 V plus 48 µF of output bulk to charge, `3V3_LIDAR` now rises *after* the MCU rather than with it. The sensor therefore finishes its own power-on slightly later than before. Confirm the boot path gives the sensor settle time before the first UART transaction, or expect the existing recovery loop to cover the first miss — see the LiDAR boot ordering in `CLAUDE.md`.

## Accepted limitation (low battery)

The input is the LiPo VBAT (3.0–4.2 V). Making 3.3 V, the LDO drops out as the battery approaches ~3.4 V (3.3 V + the light-load dropout) and the output then follows VBAT down — the same regime where the Feather's own 3.3 V LDO already struggles. This is accepted:

- For most of the discharge curve the rail is clean and fully isolated.
- Even in dropout, the LDO still isolates the sensor from WiFi/switching noise and the output bulk caps still absorb the laser pulse, so it is never worse than today.

If low-battery LiDAR range later proves to matter in the field, the fallback is a buck-boost (e.g. TPS63xxx) holding 3.3 V at any VBAT, with output filtering and careful layout because it is a switcher next to a noise-sensitive receiver. Not now.

## Power switch — full shutdown

The camera power switch is an off-board **DPDT** switch wired to the main-board 8-pin header **J4**. It does two things at once:

- **Pole A — gate the switched 3.3 V.** Bridges Feather 3.3 V (`3.3IN`, J4.8) to `3.3OUT` (J4.7), which leaves the main board on **FPC pin 6**. On = the breakout (Stemma QT J6 + U1 EN) sees 3.3 V; off = open, `3.3OUT` collapses.
- **Pole B — hold the MCU off.** In the *off* position, ties Feather **EN** (J4.4 → J2.11) to **GND** (J4.1–3), which keeps the ESP32-S3 regulator disabled so the Feather 3.3 V rail (`3.3IN`) stays down. On = EN released, the Feather's internal pull-up enables it.

The two poles are redundant by design and reinforce each other: pole B collapses `3.3IN`, which is also pole A's *source* (J4.8), so `3.3OUT` would drop even if pole A's contacts welded shut — and pole A's open contacts drop `3.3OUT` even if EN somehow floated high. Either failure still kills the LiDAR rail.

> **Harness failure mode.** J4 carries `EN`, `3.3IN`, `3.3OUT`, and `GND` out to the off-board switch, so that harness is a critical connection. If J4 is unplugged or intermittent, the Feather's onboard 100 kΩ EN pull-up holds EN high, so the **MCU boots normally while `3.3OUT` stays dead** — meaning the I²C peripherals (displays, lens ADC, IMU, encoder) and the LiDAR LDO enable all lose power even though the camera appears "on." It is a defined, safe state, not a short, but a confusing one. Use a latching/keyed J4 connector, and read "MCU runs but the displays and LiDAR are dark" as the signature of a loose or disconnected J4.

Anything that must die on power-off has to hang off a rail this kills:

- **MCU (ESP32-S3)** — on the Feather 3.3 V (`3.3IN`). Cut by pole B holding EN low.
- **I²C devices** — the ADS1015 lens ADC, both OLEDs (SH1107, SSD1306), the MPU (IMU), and the seesaw rotary encoder all share the breakout I²C bus and run from the FPC's 3.3 V (`3.3OUT`, pin 6), I²C, and GND pins (the seesaw plugs into the Stemma QT, J6). Cut by pole A opening.
- **LiDAR (DTS6012M)** — fed by U1, whose input VBAT is **always present**. So U1 must be *disabled* by the switch, not left always-on. An always-on LiDAR rail would both drain the battery and back-feed its UART lines into the powered-down MCU pins.

This is why U1 **EN is slaved to `3.3OUT` (FPC pin 6)** instead of tied to IN. Switch off → pole A opens and pole B pulls Feather EN low → `3.3OUT` drops → U1 EN low → U1 shuts down → `3V3_LIDAR` collapses. One switch kills MCU, I²C, and LiDAR.

> **Shutdown determinism — explicit EN pulldown (R1).** The TLV75533 has **no internal EN pulldown** (EN pin current ≈ 10 nA; the part's only internal pulldown is the 120 Ω *output* active-discharge). When pole A opens, `3.3OUT` is isolated from its source, so EN would fall only as the I²C peripherals bleed the node down — and those modules carry their own VDD decoupling on that rail, so that discharge is slow and indeterminate (and slower still, or stuck high, if little is plugged into the Stemma QT). To make shutdown deterministic, the design adds **R1 = 100 kΩ from `3.3V` (EN / FPC pin 6) to GND on the breakout**. It costs ~33 µA when on, but gives EN a defined path to 0 V so the LDO disables regardless of what sits on the I²C bus, making the ≤1 µA off-state guaranteed. Recommended for the respin; flagged rather than silently added because it is a board change.

**Soft disconnect (chosen).** VBAT still sits on U1's input through Cin, but U1 in shutdown draws **≤ 1 µA** (TI spec; the earlier 1–2 µA estimate was conservative) — negligible against LiPo self-discharge, *once EN is actually low* (see the determinism note above). A hard disconnect (P-FET load switch in the VBAT → FPC-pin-1 path) was considered and rejected as overkill for a camera.

**Sequencing bonus.** Because U1 enables only after the Feather 3.3 V rail is up, the 48 µF of LiDAR output bulk never loads the MCU's power-on-reset rail — which is exactly what fixes the cold-start boot regression noted above.

## Components (breakout)

| Ref | Part | Footprint | Notes |
|-----|---|---|---|
| U1 | TLV75533 (fixed 3.3 V, 500 mA) | `Package_TO_SOT_SMD:SOT-23-5` | DBV pinout (confirmed, [datasheet](#datasheet) Table 4-1): **1=IN, 2=GND, 3=EN, 4=NC, 5=OUT**. Tie **EN → FPC pin 6 (switched Feather 3.3 V)** so the power switch also disables the LDO. The switched 3.3 V already reaches the breakout on pin 6; no extra FPC conductor. See [Power switch](#power-switch--full-shutdown). |
| Cin | 1 µF (0402) + 10 µF (0805, ≥10 V) | — | Input decoupling on VBAT, at U1 IN. |
| C2, C3 | 1 µF (0603) + 100 nF (0402) | existing | **LDO stability cap — at U1 OUT.** TLV75533 needs ≥1 µF effective at OUT; keep these on the near side of FB1 so the regulator always sees its Cout (this is what keeps bead `-3z5` R4 satisfied). |
| C1 | 47 µF bulk | existing | **At J7 pin 1 (3V3_LASER)** — the pulsed load. Absorbs the laser current spike locally, on the far side of FB1. |
| FB1 | 0 Ω jumper (default) / ferrite bead (populate-option) | `0805` | Sits between the LDO output node (C2/C3, logic pin 2) and the laser bulk (C1, pin 1). **Default 0 Ω → both pins are one clean rail** (the locked plan). If scoping later shows the laser pulse coupling into the logic supply, fit a ferrite to isolate the laser without a second regulator or a dual-rail differential. Low-regret hedge; do not omit the footprint. |
| R1 | 100 kΩ | `Resistor_SMD:R_0402_1005Metric` | **EN pulldown — `3.3V` (FPC pin 6 / U1 EN) to GND.** Forces EN low at power-off so the LDO shuts down deterministically (the TLV75533 has no internal EN pulldown). ~33 µA when on. LCSC: a JLCPCB-basic 100 kΩ 0402 (e.g. C25741 — confirm before fab). See [Power switch](#power-switch--full-shutdown). |

Total Cout (47 + 1 + 0.1 µF ≈ 48 µF) stays inside the TLV75533's 1–200 µF stable window with FB1 at 0 Ω. Thermal is a non-issue: worst case ≈ 0.9 V × ~80 mA ≈ 70 mW in a SOT-23-5.

**Layout notes:** place U1 next to J7; C2/C3 hard against U1 OUT; C1 hard against J7 pin 1; Cin against U1 IN. Short, wide `3V3_LIDAR`/`GND` copper with GND stitching vias near the sensor. Add test points (or 0 Ω-pad probe points) on `3V3_LIDAR` and `VBAT` so the verification scoping below can be done without tacking onto J7.

## Datasheet

TLV75533 is the 3.3 V fixed option of TI's **TLV755P** family. Orderable part **TLV75533PDBVR** (DBV = SOT-23-5). Datasheet: TI **SBVS320D**, Nov 2017 / rev Sept 2024 — <https://www.ti.com/lit/ds/symlink/tlv755p.pdf>.

Confirmed against the design (Table 4-1 and the electrical tables):

- **DBV pinout (Table 4-1):** 1 = IN, 2 = GND, 3 = EN, 4 = NC, 5 = OUT.
- **Input range V_IN 1.45–5.5 V** — VBAT (3.0–4.2 V) is comfortably inside, so the LDO is happy across the whole battery curve until dropout.
- **I_OUT 500 mA**, internal foldback current limit (~720 mA typ) — well above the LiDAR's draw.
- **C_IN ≥ 1 µF, C_OUT 1–200 µF**, stable with ceramic. Our Cout (47 + 1 + 0.1 µF ≈ 48 µF) is inside the stable window.
- **Shutdown current ≤ 1 µA** (V_EN ≤ 0.4 V) — confirms the soft-disconnect leakage is negligible (the earlier "1–2 µA" estimate was conservative).
- **EN thresholds V_HI = 1 V (min), V_LO = 0.3 V (max); EN pin current ≈ 10 nA.** The switched 3.3 V on FPC pin 6 drives EN well past threshold for essentially no current. **There is no internal EN pulldown** — TI's "120 Ω pulldown" is the *output* active-discharge resistor (the "P" suffix), engaged only when the part is disabled, not on EN. EN therefore must be *driven*, not floated; see the [shutdown-determinism note](#power-switch--full-shutdown) on guaranteeing it goes low at power-off.
- **Dropout ≈ 150 mV typ (215 mV max at 85 °C) at 3.3 V / 500 mA**; far lower at the camera's ~80 mA load (tens of mV), so dropout onset sits just above V_BAT ≈ 3.33 V, matching the [accepted low-battery limitation](#accepted-limitation-low-battery).
- **PSRR 46 dB @ 100 kHz, 52 dB @ 1 MHz** — the noise-rejection basis for choosing this part over an AP2112K.

## Net and connector changes

**New nets (breakout):**
- `VBAT` — FPC J5 pin 1 → U1 IN (+ Cin).
- `3V3_LIDAR` — U1 OUT → C2/C3 → J7 pin 2 (logic) → FB1 input. Detach J7 pin 2 from the system `3.3V`.
- `3V3_LASER` — FB1 output → C1 (47 µF bulk) → J7 pin 1 (laser). Detach J7 pin 1 from the system `3.3V`. (FB1 = 0 Ω by default, so this is one net with `3V3_LIDAR` until a ferrite is fitted.)
- `3.3V` (existing, FPC pin 6) — now also drives **U1 EN** and **R1** (the 100 kΩ EN pulldown to GND) in addition to the Stemma QT.

**FPC (J5, 8-pin) reallocation** — no spare conductors, so repurpose one:

| Pin | Now | After | Feeds |
|-----|-----|---|---|
| 1 | 3.3V | **VBAT** | U1 IN |
| 2 | UART | UART | J7 pin 3 |
| 3 | UART | UART | J7 pin 4 |
| 4 | GND | GND | — |
| 5 | GND | GND | — |
| 6 | 3.3V | 3.3V | Stemma QT (J6) + U1 EN |
| 7 | I²C | I²C | J6 |
| 8 | I²C | I²C | J6 |

The two power conductors sit at the ends of the ribbon, away from each other: **VBAT on pin 1, next to the UART pair (2/3); the switched 3.3 V on pin 6, next to the I²C pair (7/8)**. That keeps the noisier always-on battery rail off the I²C signal lines and pairs the clean switched 3.3 V with the bus it powers.

**Main board:** wire the Feather **BAT** header pin (J2 pin 12) to a new `VBAT` net → FPC pin 1 (J3 pin 1). The Feather is modeled as generic header connectors with the BAT pin previously unconnected, so this is additive (no new connector). Match the exact header position to the Adafruit Feather ESP32-S3 pinout.

The power switch is reworked onto the existing 8-pin header **J4** as a DPDT interface (this is the change that the LDO needs and that fixes the topology the prior board got wrong — see note below):

| J4 pin | Net | Role |
|---|-----|---|
| 8 | `3.3IN` (J1.2) | Pole A in — Feather 3.3 V source |
| 7 | `3.3OUT` (→ J3.6 = FPC pin 6) | Pole A out — switched 3.3 V to breakout (U1 EN + J6 + I²C bus) |
| 4 | `EN` (→ J2.11) | Pole B — Feather enable; off position ties to GND |
| 1, 2, 3 | `GND` | Pole B return / switch common |
| 5, 6 | Feather D10 (J2.6), D9 (J2.5) | Expansion GPIOs broken out on the same header — **not** part of the power switch; leave unswitched |

So `3.3OUT` (FPC pin 6) is no longer assumed to be a free-running Feather rail — it is the gated output of pole A, and pole B independently holds the MCU off. J4 doubles as a small expansion header (pins 5,6 = D10/D9), which is why it is an 8-pin part rather than a 6-pin. See [Power switch](#power-switch--full-shutdown).

> **Reconciliation with the as-built MRF-Pro-v8 (why this section changed).** Earlier revisions of this errata assumed the Feather 3.3 V reached the breakout directly on the FPC. Schematic capture showed it did not: on the prior board FPC pin 1 was driven from a Feather **GPIO (D11)** and pin 6 was a private net to J4 pin 8, so the Feather LDO's 3.3 V never reached the FPC at all — the LiDAR's supply came through a GPIO and/or the J4 expansion header, a weak path that likely worsened the laser-pulse brownout this errata fixes. (The breakout end labels both pins `3.3V` — the J5 table above — so the two boards' nets *named* the same thing while the main board actually fed them from D11 and J4.8. That end-to-end mismatch is exactly the defect.) The respin corrects it: FPC pin 6 now carries a real switched 3.3 V (`3.3OUT`) gated by the J4 DPDT, pin 1 carries `VBAT`, and D11 is freed.

## Execution split

Schematic capture (adding U1, Cin, the new nets, and the EN/BAT wiring) is done in the KiCad GUI — `kicad-cli` runs ERC and exports but cannot author a schematic, and both boards model the Feather as generic pins, so net targeting needs the editor plus the Adafruit pinout. PCB layout (placement, routing, pours, DRC, fab outputs) is also GUI work. Validate with `kicad-cli sch erc` after capture (the binary ships inside `KiCad.app/Contents/MacOS/` on macOS).

**Step-by-step capture:** [lidar-stage2-ldo-kicad-guide.md](lidar-stage2-ldo-kicad-guide.md). The subcircuit to draw is the breakout diagram in [Architecture](#architecture--regulate-at-the-point-of-load) above ([images/lidar-ldo-schematic.svg](images/lidar-ldo-schematic.svg)).

## Verification

- ERC both boards; netlist shows U1 IN on `VBAT`; U1 OUT + C2/C3 + J7 pin 2 on `3V3_LIDAR`; FB1 → C1 + J7 pin 1 on `3V3_LASER`; U1 EN + R1 on the FPC pin-6 switched rail (`3.3V` on the breakout sheet = `3.3OUT` on the main sheet), R1's other end on `GND`; J6 still on that same rail. Main board: Feather BAT (J2.12) on `VBAT` → FPC pin 1; J4 DPDT wired `3.3IN`(J4.8)/`3.3OUT`(J4.7)/`EN`(J4.4)/`GND`(J4.1-3).
- **J7 pin 5 (INT) still tied low** and pins 3,4 (UART) unchanged — the mode select must read UART at power-on.
- Scope J7 VCC under laser load: ripple to tens of mV; confirm it holds clean until VBAT approaches ~3.5 V (dropout onset). Confirm the rail never exceeds the sensor's 3.6 V abs-max.
- **Power switch off:** confirm `3V3_LIDAR` drops to 0 V and off-state battery current is ~µA (no always-on LiDAR draw).
- **Cold start:** after a long time switched off, a single switch-on boots first try (the boot regression is gone). Also confirm the LiDAR still enumerates on first boot now that `3V3_LIDAR` rises *after* the MCU (Health-screen firmware-version response present, recovery count not climbing).
- Max-range bright-ambient field test versus the decoupling-only build.

**Reading the range result.** Range scales roughly as √(laser power × target reflectivity), and the datasheet's 12 m / 20 m figures are best-case (high-reflectivity, 20 m in the dark). So:

- Before crediting the fix, run the discriminator: aim at a **large high-reflectivity target (white board/wall) in a dim room, square-on.** Still ~4–5 m → the ceiling is supply/config (the power fix is the right lever); reaches 12 m+ → the field 4–5 m cases were reflectivity/ambient on a healthy sensor, and the fix raises the floor but won't deliver 20 m on dark targets.
- Set expectations accordingly: a clean rail restores the sensor to its *reflectivity-appropriate* range, not 20 m on everything.
- Rule out firmware first: confirm the DTS6012M's configurable TDC time-window / max-range gating and the `Inf?` far-dropout handling are not clipping the histogram before attributing the ceiling to power.

See [lidar-field-test.md](lidar-field-test.md) for the full protocol.

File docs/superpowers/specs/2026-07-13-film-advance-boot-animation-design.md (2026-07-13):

# Film-advance boot animation (external display)

**Date:** 2026-07-13
**Target version:** 10.6.1 (patch bump + tag + GitHub release)
**Scope:** Firmware only. One new pure-logic module, one host unit test, a thin draw loop in `main.cpp`, a handful of constants, plus the standard release-file updates.

## Goal

Give the 128x32 external SSD1306 a silly-but-tasteful startup animation: a strip of
perforated film feeds in from the right and carries the `MRF X.Y.Z` version into
the centre, like loading a fresh roll. It fully replaces today's static splash and
must not make boot feel slower.

## Current behaviour (what we're replacing)

`showBootScreenOnExternalDisplay()` in `Firmware/src/main.cpp` prints `MRF X.Y.Z`
centred, holds it for `DISPLAY_BOOT_SCREEN_MS` (1000 ms) via a blocking `delay`,
then clears the display and hands the panel to `u8g2_ext`. It is called once in
`setup()` between `initializeMainDisplay()` and the LiDAR init step, guarded by
`hardware.externalDisplay`.

## Design

### The animation (128 wide x 32 tall, monochrome)

- **Sprocket perforations:** small white rectangles run along the top edge
  (y 0..3) and bottom edge (y 28..31) at a fixed horizontal spacing. Each frame
  their x positions shift left by a fixed step and wrap, so the film reads as
  advancing through the gate. Perforations are present for the whole animation.
- **Frame image (the "photo"):** the centre band (y ~8..24) carries the text
  `MRF X.Y.Z`. It starts fully off the right edge and eases left to centred.
- **Landing:** once the text is centred, perforations tick for a couple more
  frames, then a short hold, then the display clears exactly as today and control
  passes to `u8g2_ext`. Final visible state = version legibly centred (same info
  a builder relies on today).

### Timing

Whole sequence targets ~1000-1200 ms so perceived boot time is unchanged. The
existing `DISPLAY_BOOT_SCREEN_MS` is repurposed as the end-hold after landing (or
reduced accordingly); the moving portion is `frameCount * frameDelayMs`. Concrete
values live in constants (below) and are tuned so the total stays in budget.

### Logic / hardware split (matches repo convention)

New pure module `Firmware/src/boot_animation_logic.cpp` + `include/boot_animation_logic.h`,
host-testable, no Arduino/Adafruit types. It computes, given a frame index and the
display width, the per-frame geometry the draw loop needs. Proposed surface:

```cpp
// Eased horizontal offset (px) of the version text for a given frame.
// Monotonically non-increasing; starts >= displayWidth (off-screen right),
// ends at the centred x for the final animated frame.
int bootTextXForFrame(int frame, int totalFrames, int displayWidth, int textWidth);

// Wrapped horizontal offset (0..spacing-1) of the sprocket holes for a frame.
int bootSprocketOffsetForFrame(int frame, int stepPx, int spacingPx);
```

Easing: a simple integer ease-out (e.g. offset proportional to
`(totalFrames - frame)^2 / totalFrames^2 * startOffset`) so the film decelerates
into place. Exact curve chosen during implementation; the test pins the
invariants, not the precise pixels.

The draw loop in `main.cpp` stays thin: for each frame, clear, draw top+bottom
sprocket rects using `bootSprocketOffsetForFrame`, draw the version text at
`bootTextXForFrame`, `display_ext.display()`, `delay(frameDelayMs)`. Version
string is built once with the existing largest-fits-width sizing logic so long
versions (e.g. `10.6.10`) still fit.

### Constants (`Firmware/include/mrfconstants.h`)

- `DISPLAY_BOOT_ANIM_FRAMES` — number of animated frames (e.g. 16).
- `DISPLAY_BOOT_ANIM_FRAME_MS` — per-frame delay (e.g. 45 ms).
- `DISPLAY_BOOT_SPROCKET_SPACING` — px between perforation centres (e.g. 12).
- `DISPLAY_BOOT_SPROCKET_STEP` — px the perforations shift per frame (e.g. 3).
- `DISPLAY_BOOT_SPROCKET_W` / `_H` — perforation rect size.
- `DISPLAY_BOOT_SCREEN_MS` — retained, now the post-landing hold.

### What does NOT change

- No new boot step; the main-display progress bar is untouched.
- No prefs / NVS schema change (no `PREFS_SCHEMA_VERSION` bump).
- `hardware.externalDisplay` guard and the `u8g2_ext` handoff are preserved.
- Graceful no-op when the external display is absent (early return, as today).

## Testing

Add cases to `Firmware/test/test_core_logic_regression/test_main.cpp` (include the
new logic `.cpp` and header the same way the other logic modules are pulled in).
Assert the invariants:

- `bootTextXForFrame(0, ...)` >= displayWidth (text starts fully off-screen right).
- Sequence is monotonically non-increasing across frames (never jitters right).
- Final frame lands at the centred x: `(displayWidth - textWidth) / 2`.
- `bootSprocketOffsetForFrame` stays within `[0, spacing)` and advances by `step`
  each frame with correct wrap.

Run: `pio test -e native_core_tests -f test_core_logic_regression`.
Firmware build sanity: `pio run -e adafruit_feather_esp32s3`.
On-hardware check: flash and confirm the film feeds in, version lands centred,
boot feels no slower. Note "verify on device" in the CHANGELOG since timing is
eyeballed, not measured.

## Documentation & release (10.6.1)

Per the repo release workflow, update all five version files:

1. `Firmware/include/mrfconstants.h` -> `#define FWVERSION "10.6.1"`
2. `Firmware/README.md` -> `**Version**: 10.6.1`
3. `Firmware/CHANGELOG.md` -> new `## 10.6.1 - 2026-07-13` section describing the
   boot animation, with a "verify boot timing on device" note.
4. `Documentation/user-manual/USER_MANUAL.md` -> `**Firmware version:** 10.6.1`
5. `Documentation/user-manual/images/config-ui.svg` -> on-screen version label.

Then commit, push the branch, and after merge: annotated tag `v10.6.1`, GitHub
release with the changelog section as the body (no binary assets).

## Out of scope

- Any animation on the main 128x128 display.
- User-configurable / toggleable animation (YAGNI; it's a boot flourish).
- Sound, per-format variations, or logo bitmaps.

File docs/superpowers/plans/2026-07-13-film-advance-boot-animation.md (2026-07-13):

# Film-Advance Boot Animation Implementation Plan

> **For agentic workers:** REQUIRED SUB-SKILL: Use superpowers:subagent-driven-development (recommended) or superpowers:executing-plans to implement this plan task-by-task. Steps use checkbox (`- [ ]`) syntax for tracking.

**Goal:** Replace the static external-display boot splash with a silly film-advance animation that feeds the `MRF X.Y.Z` version in from the right, and ship it as firmware 10.6.1.

**Architecture:** A new pure-logic module computes per-frame geometry (eased text x-offset, wrapped sprocket offset) and is host-unit-tested. The draw loop in `main.cpp`'s existing `showBootScreenOnExternalDisplay()` calls that logic and renders rectangles + text to the 128x32 SSD1306, keeping the hardware code thin. Timing constants live in `mrfconstants.h`.

**Tech Stack:** C++ (Arduino/ESP32-S3), Adafruit_SSD1306 for the external OLED, PlatformIO, Unity host tests (`native_core_tests`).

## Global Constraints

- External display is 128 wide x 32 tall, monochrome (`SCREEN_WIDTH` = 128, `SCREEN_HEIGHT_EXT` = 32).
- Pure-logic modules must be host-compilable: no Arduino/Adafruit types in `boot_animation_logic.*`.
- No `Co-Authored-By: Claude` or any AI trailer in commits. Human-style commit subjects, no AI tells, no emoji.
- Do NOT add `setFrameRate`-style side effects; this change touches display only.
- No prefs / NVS schema change; do not bump `PREFS_SCHEMA_VERSION`.
- Preserve the `hardware.externalDisplay` guard and the `u8g2_ext.begin(display_ext)` handoff at the end of the boot screen.
- Total animation (moving frames + end hold) must stay ~1000-1200 ms so boot feels no slower.
- Release version is exactly `10.6.1`; date `2026-07-13`.

---

### Task 1: Pure boot-animation geometry logic + host tests

**Files:**
- Create: `Firmware/include/boot_animation_logic.h`
- Create: `Firmware/src/boot_animation_logic.cpp`
- Test: `Firmware/test/test_core_logic_regression/test_main.cpp` (add include + cases)

**Interfaces:**
- Consumes: nothing.
- Produces:
  - `int bootTextXForFrame(int frame, int totalFrames, int displayWidth, int textWidth);`
  - `int bootSprocketOffsetForFrame(int frame, int stepPx, int spacingPx);`

- [ ] **Step 1: Write the failing tests**

Add near the other logic includes at the top of `Firmware/test/test_core_logic_regression/test_main.cpp`:

```cpp
#include "boot_animation_logic.h"
```

And with the other `#include "../../src/*.cpp"` lines:

```cpp
#include "../../src/boot_animation_logic.cpp"
```

Add these test functions (place them alongside the existing `test_*` functions):

```cpp
void test_boot_text_starts_offscreen_right()
{
  // Frame 0: the version text begins fully off the right edge of the display.
  TEST_ASSERT_TRUE(bootTextXForFrame(0, 16, 128, 120) >= 128);
}

void test_boot_text_lands_centered_on_final_frame()
{
  const int totalFrames = 16;
  const int displayWidth = 128;
  const int textWidth = 120;
  int expectedCentered = (displayWidth - textWidth) / 2; // 4
  TEST_ASSERT_EQUAL_INT(expectedCentered,
                        bootTextXForFrame(totalFrames - 1, totalFrames, displayWidth, textWidth));
}

void test_boot_text_is_monotonically_non_increasing()
{
  const int totalFrames = 16;
  int prev = bootTextXForFrame(0, totalFrames, 128, 120);
  for (int f = 1; f < totalFrames; f++)
  {
    int x = bootTextXForFrame(f, totalFrames, 128, 120);
    TEST_ASSERT_TRUE(x <= prev); // film never jitters back to the right
    prev = x;
  }
}

void test_boot_text_single_frame_guard()
{
  // Degenerate totalFrames must not divide by zero; returns the centered x.
  TEST_ASSERT_EQUAL_INT((128 - 120) / 2, bootTextXForFrame(0, 1, 128, 120));
}

void test_boot_sprocket_offset_within_spacing_and_advances()
{
  const int step = 3;
  const int spacing = 12;
  for (int f = 0; f < 40; f++)
  {
    int off = bootSprocketOffsetForFrame(f, step, spacing);
    TEST_ASSERT_TRUE(off >= 0 && off < spacing);
    TEST_ASSERT_EQUAL_INT((f * step) % spacing, off);
  }
}

void test_boot_sprocket_offset_spacing_guard()
{
  // Non-positive spacing must not modulo-by-zero.
  TEST_ASSERT_EQUAL_INT(0, bootSprocketOffsetForFrame(5, 3, 0));
}
```

Register them in the Unity `RUN_TEST(...)` block (inside `main()` / the runner where the other `RUN_TEST` calls live):

```cpp
RUN_TEST(test_boot_text_starts_offscreen_right);
RUN_TEST(test_boot_text_lands_centered_on_final_frame);
RUN_TEST(test_boot_text_is_monotonically_non_increasing);
RUN_TEST(test_boot_text_single_frame_guard);
RUN_TEST(test_boot_sprocket_offset_within_spacing_and_advances);
RUN_TEST(test_boot_sprocket_offset_spacing_guard);
```

- [ ] **Step 2: Run tests to verify they fail**

Run: `pio test -e native_core_tests -f test_core_logic_regression`
Expected: FAIL to compile / link with an error about `boot_animation_logic.h` not found or `bootTextXForFrame` undefined.

- [ ] **Step 3: Write the header**

Create `Firmware/include/boot_animation_logic.h`:

```cpp
#ifndef BOOT_ANIMATION_LOGIC_H
#define BOOT_ANIMATION_LOGIC_H

// Pure geometry for the external-display film-advance boot animation.
// No Arduino/Adafruit types so it can be unit-tested on the host.

// Eased left-edge x (px) of the version text for a given animation frame.
// The film feeds in from the right: frame 0 starts fully off-screen
// (x == displayWidth) and the sequence eases out to the centered x on the
// final frame (frame == totalFrames - 1). Monotonically non-increasing.
// frame is clamped to [0, totalFrames - 1]; totalFrames <= 1 returns centered.
int bootTextXForFrame(int frame, int totalFrames, int displayWidth, int textWidth);

// Wrapped x-offset (0..spacingPx-1) of the sprocket perforations for a frame,
// advancing by stepPx each frame so the film reads as moving left.
// spacingPx <= 0 returns 0.
int bootSprocketOffsetForFrame(int frame, int stepPx, int spacingPx);

#endif // BOOT_ANIMATION_LOGIC_H
```

- [ ] **Step 4: Write the implementation**

Create `Firmware/src/boot_animation_logic.cpp`:

```cpp
#include "boot_animation_logic.h"

int bootTextXForFrame(int frame, int totalFrames, int displayWidth, int textWidth)
{
  const int centered = (displayWidth - textWidth) / 2;
  if (totalFrames <= 1)
  {
    return centered;
  }
  if (frame < 0)
  {
    frame = 0;
  }
  if (frame > totalFrames - 1)
  {
    frame = totalFrames - 1;
  }

  const long last = totalFrames - 1;
  const int start = displayWidth;            // fully off the right edge
  const long span = (long)(centered - start); // negative: text moves left

  // Ease-out: eased = 1 - (1 - p)^2, with p = frame / last.
  // easedNumerator / (last*last) == eased, kept in integer math.
  const long remaining = last - frame;
  const long easedNumerator = last * last - remaining * remaining;

  return start + (int)(span * easedNumerator / (last * last));
}

int bootSprocketOffsetForFrame(int frame, int stepPx, int spacingPx)
{
  if (spacingPx <= 0)
  {
    return 0;
  }
  long off = ((long)frame * stepPx) % spacingPx;
  if (off < 0)
  {
    off += spacingPx;
  }
  return (int)off;
}
```

- [ ] **Step 5: Run tests to verify they pass**

Run: `pio test -e native_core_tests -f test_core_logic_regression`
Expected: PASS — all existing tests plus the six new ones.

- [ ] **Step 6: Commit**

```bash
git add Firmware/include/boot_animation_logic.h Firmware/src/boot_animation_logic.cpp Firmware/test/test_core_logic_regression/test_main.cpp
git commit -m "Add boot animation geometry logic with host tests"
```

---

### Task 2: Constants + film-advance draw loop in main.cpp

**Files:**
- Modify: `Firmware/include/mrfconstants.h` (add animation constants; retune `DISPLAY_BOOT_SCREEN_MS`)
- Modify: `Firmware/src/main.cpp` (include header; replace body of `showBootScreenOnExternalDisplay()`)

**Interfaces:**
- Consumes: `bootTextXForFrame`, `bootSprocketOffsetForFrame` from Task 1.
- Produces: animated boot screen; no new public symbols.

- [ ] **Step 1: Add constants**

In `Firmware/include/mrfconstants.h`, next to the existing `DISPLAY_BOOT_SCREEN_MS` / `DISPLAY_BOOT_TEXT_SIZE` lines (around line 68-77), change the hold and add the animation constants:

```cpp
const unsigned long DISPLAY_BOOT_SCREEN_MS = 400;      // Post-landing hold after the film settles.
const int DISPLAY_BOOT_ANIM_FRAMES = 16;               // Number of animated film-advance frames.
const unsigned long DISPLAY_BOOT_ANIM_FRAME_MS = 40;   // Delay per animation frame (16*40 = 640 ms).
const int DISPLAY_BOOT_SPROCKET_SPACING = 12;          // Px between sprocket-hole centres.
const int DISPLAY_BOOT_SPROCKET_STEP = 3;              // Px the perforations shift per frame.
const int DISPLAY_BOOT_SPROCKET_W = 6;                 // Sprocket-hole width in px.
const int DISPLAY_BOOT_SPROCKET_H = 4;                 // Sprocket-hole height (top and bottom bands).
```

(Total ~640 ms moving + 400 ms hold = ~1040 ms, within the 1000-1200 ms budget.)

- [ ] **Step 2: Include the logic header in main.cpp**

In `Firmware/src/main.cpp`, add to the include block (after `#include "mrfconstants.h"`):

```cpp
#include "boot_animation_logic.h"
```

- [ ] **Step 3: Replace the body of showBootScreenOnExternalDisplay()**

Replace the current function body (the version-sizing loop through the final clear) so it keeps the largest-fits-width sizing, then animates. The full function becomes:

```cpp
void showBootScreenOnExternalDisplay()
{
  if (!hardware.externalDisplay)
  {
    return;
  }

  display_ext.clearDisplay();
  display_ext.setTextColor(SSD1306_WHITE);

  char bootText[24];
  snprintf(bootText, sizeof(bootText), "MRF %s", FWVERSION);

  // Pick the largest text size (up to the preferred one) that fits the display
  // width, so a longer version string (e.g. 10.6.10) can't wrap on the narrow
  // external screen.
  int16_t bootTextX1 = 0;
  int16_t bootTextY1 = 0;
  uint16_t bootTextWidth = 0;
  uint16_t bootTextHeight = 0;
  for (int bootTextSize = DISPLAY_BOOT_TEXT_SIZE; bootTextSize >= 1; bootTextSize--)
  {
    display_ext.setTextSize(static_cast<uint8_t>(bootTextSize));
    display_ext.getTextBounds(bootText, 0, 0, &bootTextX1, &bootTextY1, &bootTextWidth, &bootTextHeight);
    if (static_cast<int16_t>(bootTextWidth) <= display_ext.width())
    {
      break;
    }
  }

  const int16_t bootCursorY =
      ((display_ext.height() - static_cast<int16_t>(bootTextHeight)) / 2) - bootTextY1;

  // Film-advance animation: perforations tick left along the top and bottom
  // edges while the version rides in from the right and eases to centre.
  for (int frame = 0; frame < DISPLAY_BOOT_ANIM_FRAMES; frame++)
  {
    display_ext.clearDisplay();

    const int sprocketOffset =
        bootSprocketOffsetForFrame(frame, DISPLAY_BOOT_SPROCKET_STEP, DISPLAY_BOOT_SPROCKET_SPACING);
    for (int x = sprocketOffset - DISPLAY_BOOT_SPROCKET_SPACING; x < display_ext.width();
         x += DISPLAY_BOOT_SPROCKET_SPACING)
    {
      display_ext.fillRect(x, 0, DISPLAY_BOOT_SPROCKET_W, DISPLAY_BOOT_SPROCKET_H, SSD1306_WHITE);
      display_ext.fillRect(x, display_ext.height() - DISPLAY_BOOT_SPROCKET_H,
                           DISPLAY_BOOT_SPROCKET_W, DISPLAY_BOOT_SPROCKET_H, SSD1306_WHITE);
    }

    const int textX = bootTextXForFrame(frame, DISPLAY_BOOT_ANIM_FRAMES,
                                        display_ext.width(), static_cast<int>(bootTextWidth));
    display_ext.setCursor(static_cast<int16_t>(textX) - bootTextX1, bootCursorY);
    display_ext.print(bootText);

    display_ext.display();
    delay(DISPLAY_BOOT_ANIM_FRAME_MS);
  }

  // Hold the settled frame, then clear and hand the panel to u8g2_ext as before.
  delay(DISPLAY_BOOT_SCREEN_MS);

  u8g2_ext.begin(display_ext);
  display_ext.clearDisplay();
  display_ext.display();
}
```

- [ ] **Step 4: Build the firmware**

Run: `pio run -e adafruit_feather_esp32s3`
Expected: SUCCESS, no new `-Wall -Wextra` warnings from the changed code.

- [ ] **Step 5: Re-run host tests (regression guard)**

Run: `pio test -e native_core_tests`
Expected: PASS (unchanged; confirms the constants edit didn't break anything).

- [ ] **Step 6: On-device verification**

Flash a board (`pio run -e adafruit_feather_esp32s3 --target upload`) and watch the external display at power-on: perforations tick left, `MRF 10.6.0`/current version rides in from the right and settles centred, boot feels no slower than before. (Version string updates to 10.6.1 in Task 3.)

- [ ] **Step 7: Commit**

```bash
git add Firmware/include/mrfconstants.h Firmware/src/main.cpp
git commit -m "Animate external boot splash as a film-advance sequence"
```

---

### Task 3: Version bump to 10.6.1 + docs + release

**Files:**
- Modify: `Firmware/include/mrfconstants.h:9`
- Modify: `Firmware/README.md:3`
- Modify: `Firmware/CHANGELOG.md` (new top section)
- Modify: `Documentation/user-manual/USER_MANUAL.md:3`
- Modify: `Documentation/user-manual/images/config-ui.svg:15`

**Interfaces:**
- Consumes: the feature from Tasks 1-2.
- Produces: a tagged, released 10.6.1.

- [ ] **Step 1: Bump the firmware version constant**

In `Firmware/include/mrfconstants.h` line 9:

```cpp
#define FWVERSION "10.6.1"                   // Version shown in UI and release metadata.
```

- [ ] **Step 2: Bump README**

In `Firmware/README.md` line 3:

```markdown
**Version**: 10.6.1
```

- [ ] **Step 3: Bump user manual**

In `Documentation/user-manual/USER_MANUAL.md` line 3:

```markdown
**Firmware version:** 10.6.1
```

- [ ] **Step 4: Update the on-screen version label in the SVG**

In `Documentation/user-manual/images/config-ui.svg` line 15, change the version at the end of the text node:

```xml
  <text x="3" y="121" font-family="monospace" font-size="6" fill="#ffffff"> IDENTIDEM.design MRF 10.6.1</text>
```

- [ ] **Step 5: Add the CHANGELOG section**

In `Firmware/CHANGELOG.md`, insert this new section immediately above `## 10.6.0 - 2026-07-13`:

```markdown
## 10.6.1 - 2026-07-13

### External display boot animation

- Replaced the static `MRF X.Y.Z` boot splash on the external OLED with a film-advance animation: sprocket perforations tick along the top and bottom edges while the version rides in from the right and settles centred, like loading a fresh roll. The per-frame geometry lives in a new host-tested `boot_animation_logic` module; the draw loop stays thin. Boot timing is unchanged (~1 s). Verify boot timing and legibility on device.
```

- [ ] **Step 6: Verify the version appears consistently**

Run: `grep -rn "10.6.1" Firmware/include/mrfconstants.h Firmware/README.md Firmware/CHANGELOG.md Documentation/user-manual/USER_MANUAL.md Documentation/user-manual/images/config-ui.svg`
Expected: one match in each of the five files.

- [ ] **Step 7: Commit**

```bash
git add Firmware/include/mrfconstants.h Firmware/README.md Firmware/CHANGELOG.md Documentation/user-manual/USER_MANUAL.md Documentation/user-manual/images/config-ui.svg
git commit -m "Release firmware v10.6.1"
```

- [ ] **Step 8: Tag and release (after merge to main)**

These run once the branch is merged. Confirm with the maintainer before pushing.

```bash
git tag -a v10.6.1 <merge-commit> -m "Firmware v10.6.1"
git push origin v10.6.1
gh release create v10.6.1 --title "Firmware v10.6.1" --notes-file <(sed -n '/## 10.6.1/,/## 10.6.0/p' Firmware/CHANGELOG.md | sed '$d')
```

Tags are annotated, not signed. No binary assets — the updater workflow builds from `main`.

---

## Self-Review

**Spec coverage:**
- Animation on external display, film-advance, replaces static splash → Task 2 draw loop. Yes
- Perforations present whole animation, version eases in from right to centre → Task 1 logic + Task 2 loop. Yes
- Timing ~1000-1200 ms → Task 2 constants (640 + 400 ms). Yes
- Logic/hardware split, pure host-tested module → Task 1. Yes
- Test invariants (starts off-screen, monotonic, lands centred, sprocket wrap) → Task 1 tests. Yes
- No prefs/schema change, preserve guard + u8g2_ext handoff → Task 2 function preserves both. Yes
- Release 10.6.1: five version files + changelog + tag/release → Task 3. Yes
- Out of scope (main display, toggle, sound) → not present. Yes

**Placeholder scan:** No TBD/TODO; all steps have concrete code and commands. The `<merge-commit>` in Step 8 is a genuine post-merge value the maintainer supplies, not a plan gap.

**Type consistency:** `bootTextXForFrame` / `bootSprocketOffsetForFrame` signatures identical across header (Task 1), tests (Task 1), and call sites (Task 2). Constant names (`DISPLAY_BOOT_ANIM_FRAMES`, `DISPLAY_BOOT_ANIM_FRAME_MS`, `DISPLAY_BOOT_SPROCKET_SPACING`, `DISPLAY_BOOT_SPROCKET_STEP`, `DISPLAY_BOOT_SPROCKET_W`, `DISPLAY_BOOT_SPROCKET_H`, `DISPLAY_BOOT_SCREEN_MS`) match between Task 2 Step 1 and Step 3.

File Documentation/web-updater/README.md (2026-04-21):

# MRF2 Browser Firmware Updater (GitHub Pages)

This repo includes a static firmware updater site in `docs/` that uses Web Serial + ESP Web Tools to flash MRF2 firmware in-browser.

## Public URL

`https://update.mrf2.com/`

## UI snapshot

Web updater UI

## How it works

1. The GitHub Actions workflow `.github/workflows/firmware-updater-pages.yml` builds firmware from `Firmware/` using PlatformIO.
2. The workflow copies all required ESP32-S3 images into each version directory:
   - `bootloader.bin` @ `0x0000` (Adafruit TinyUF2 bootloader)
   - `partitions.bin` @ `0x8000`
   - `boot_app0.bin` @ `0xE000`
   - `tinyuf2.bin` @ `0x2D0000`
   - `firmware.bin` @ `0x10000`
3. The workflow also builds tagged historical releases and publishes them under `firmware/versions/<version>/`.
4. The workflow generates:
   - `firmware/latest/manifest.json`
   - `firmware/versions/<version>/manifest.json` for each published version
   - `firmware/versions.json` catalog (used by the UI dropdown)
5. The static app in `docs/` loads `firmware/versions.json`, defaults the selector to the latest entry, and points ESP Web Tools to the selected manifest.
6. The release notes panel shows notes for the selected version and the immediately previous version, with a link to the full changelog.

## Settings preservation

Camera settings are stored in NVS (ESP32 non-volatile storage) at flash address `0x9000`. None of the five flashed images overlap that address, so all saved settings survive a web updater firmware upgrade. New settings introduced by a firmware update will simply load their defaults on first boot until changed.

The manifest sets `new_install_prompt_erase: false`, which prevents the flasher from erasing the device before writing. A full chip erase is never performed by the web updater.

If you need to reset all settings to factory defaults, use the factory reset option in the camera's settings menu, or reflash via PlatformIO as described in `Documentation/flash-firmware/README.md`.

## Browser requirements

- Desktop Chrome or Edge (Web Serial support)
- HTTPS context (GitHub Pages provides this)
- USB data cable

## Operational notes

- Workflow trigger is `push` to `main` (and `workflow_dispatch`).
- If the site shows `Not published yet`, run the workflow or merge to `main`.
- If `boot_app0.bin` path changes in PlatformIO packages, update the workflow copy path.

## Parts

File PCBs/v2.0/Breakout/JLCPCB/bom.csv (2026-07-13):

Designator | Footprint | Quantity | Value | LCSC Part #
C1 | 1206 | 1 | 47uF | C96123
C2 | 0603 | 1 | 1uF | C15849
C3 | 0402 | 1 | 100nF | C1525
CIN1 | 0402 | 1 | 1uF | C52923
CIN2 | 0805 | 1 | 10uF | C15850
FB1 | 0805 | 1 | 0 | C17477
J5 | TE_0-1734839-8_1x08-1MP_P0.5mm_Horizontal | 1 | FPC 8P Connector | C2856797
J6 | JST_SH_SM04B-SRSS-TB_1x04-1MP_P1.00mm_Horizontal | 1 | Stemma QT | C7430446
J7 | JST_SH_SM06B-SRSS-TB_1x06-1MP_P1.00mm_Horizontal | 1 | TFS20L / DTS6012M | C7430448
R1 | 0402 | 1 | 100k | C25741
U1 | SOT-23-5 | 1 | TLV75533 | C404027

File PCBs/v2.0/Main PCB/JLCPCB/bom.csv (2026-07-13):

Designator | Footprint | Quantity | Value | LCSC Part #
J1 | PinHeader_1x16_P2.54mm_Vertical | 1 | Feather-1
J2 | PinHeader_1x12_P2.54mm_Vertical | 1 | Feather-2
J3 | TE_0-1734839-8_1x08-1MP_P0.5mm_Horizontal | 1 | FPC 8P Connector | C2856797
J4 | JST_SH_BM08B-SRSS-TB_1x08-1MP_P1.00mm_Vertical | 1 | Conn_01x08 | C7430450

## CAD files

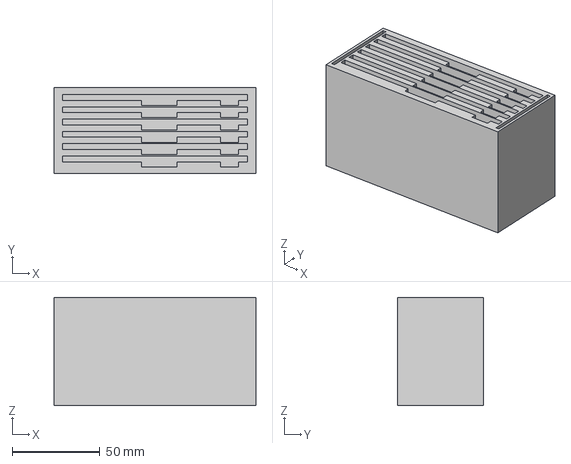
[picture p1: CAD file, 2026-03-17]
3MF/Accessories/mask-container.3mf
115.0 x 49.0 x 61.5 mm

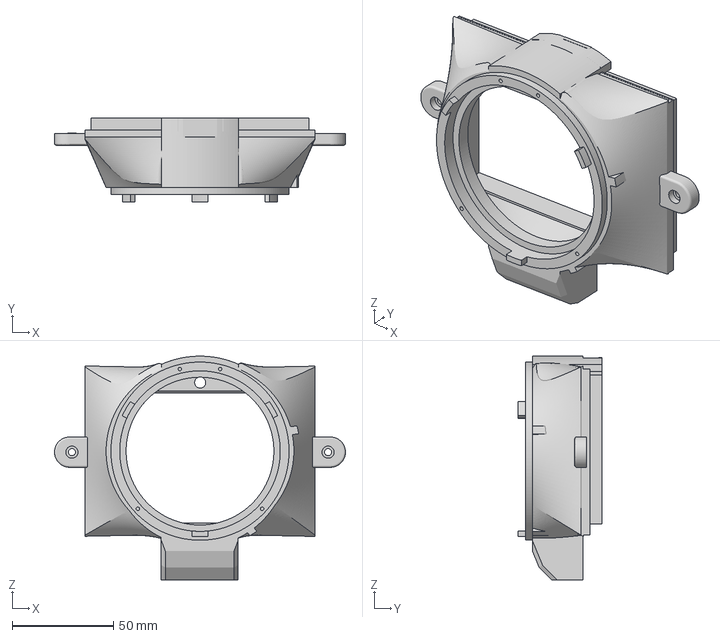
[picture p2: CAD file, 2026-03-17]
3MF/Bayonet Lens Cone/lens-cone-body.3mf
143.8 x 41.7 x 110.5 mm

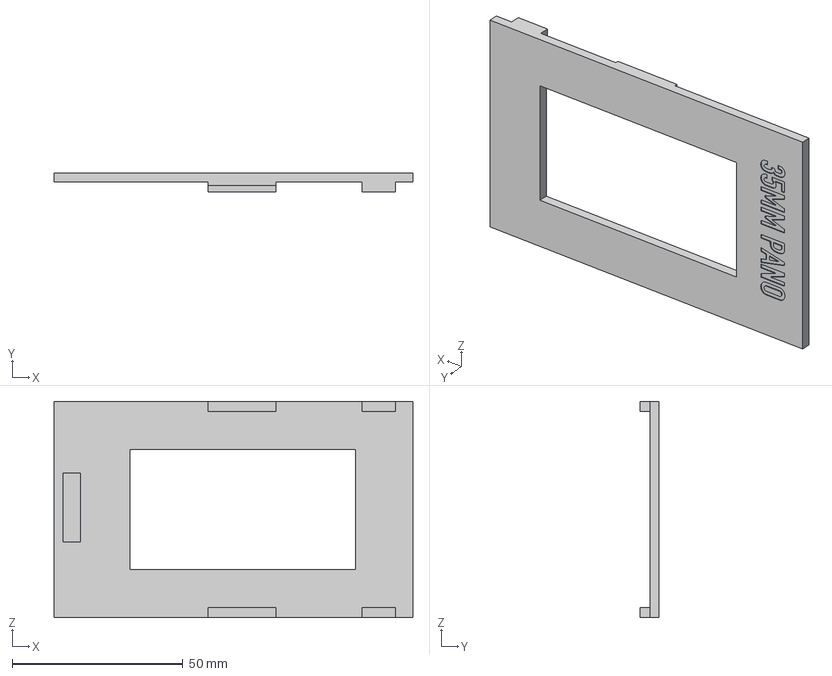
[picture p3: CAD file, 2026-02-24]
3MF/Film Masks/35mm-pano.3mf
105.0 x 5.65 x 63.2 mm

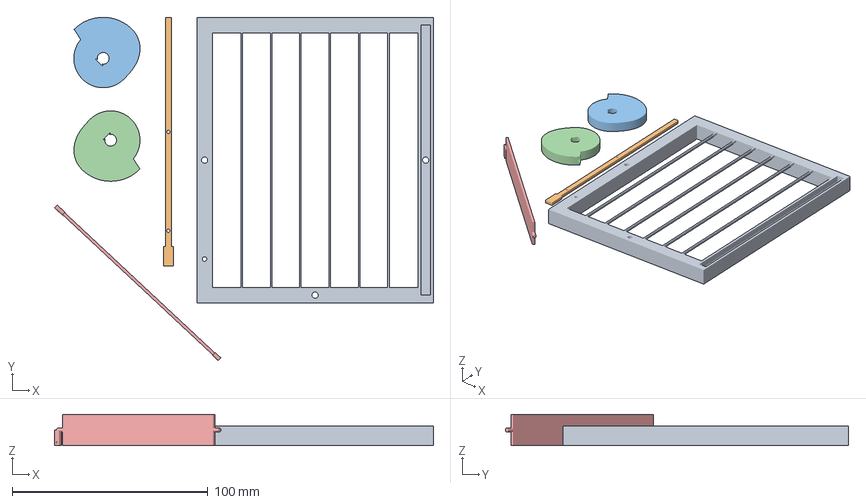
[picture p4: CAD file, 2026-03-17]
3MF/Fine Parts/advance-plate.3mf
193.7 x 175.5 x 16.0 mm
frame.stl
linkage_bar.stl
cam_mirror.stl
cam_baffle.stl
slat.stl

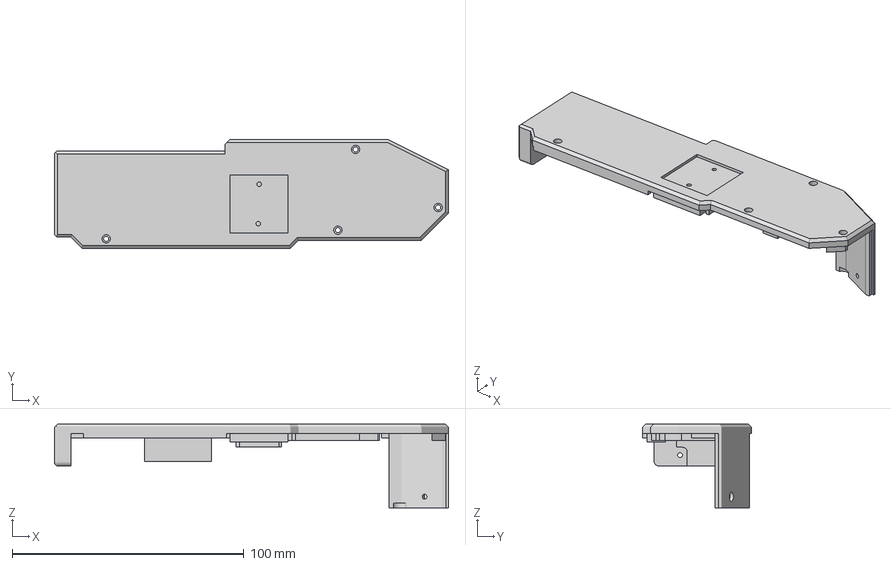
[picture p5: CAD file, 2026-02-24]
3MF/Main Parts/viewfinder-lid.3mf
170.1 x 47.1 x 36.2 mm

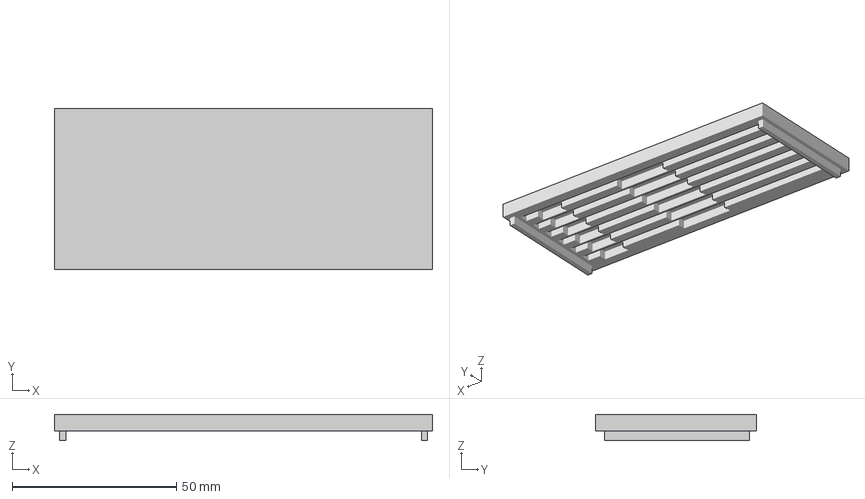
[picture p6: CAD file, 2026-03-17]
3MF/Accessories/mask-container-lid.3mf
115.0 x 49.0 x 8.06 mm

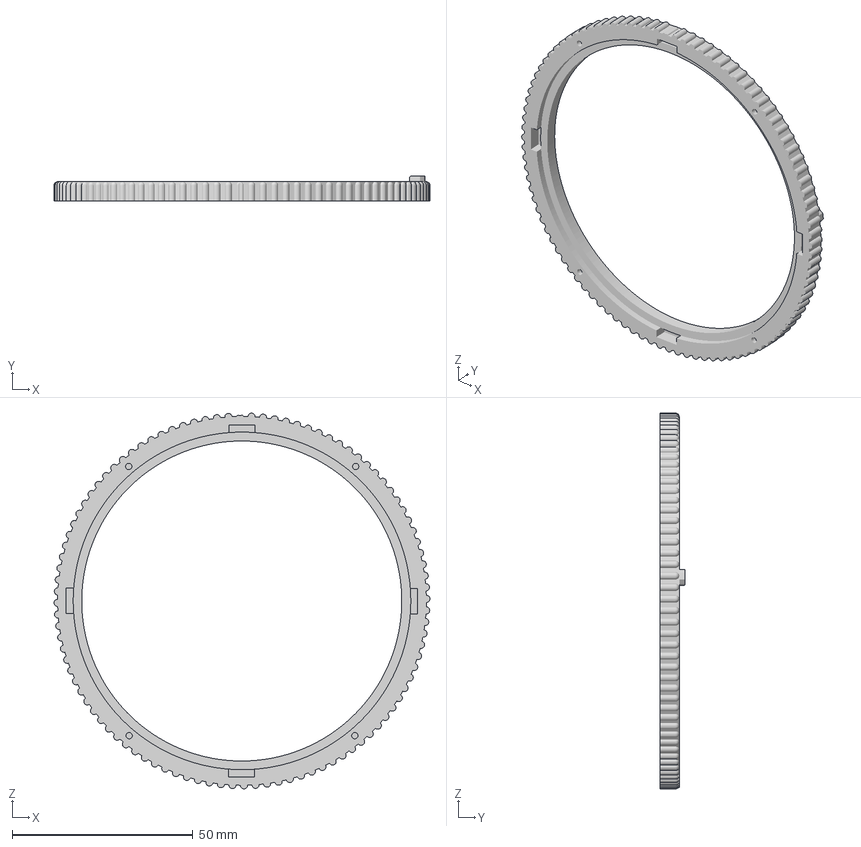
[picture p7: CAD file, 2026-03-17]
3MF/Bayonet Lens Cone/lens-bottom-ring.3mf
104.0 x 6.95 x 103.9 mm

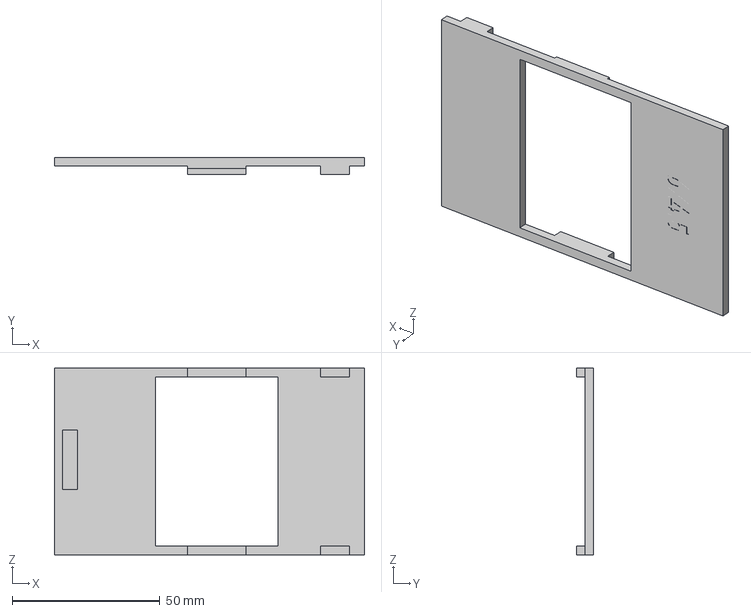
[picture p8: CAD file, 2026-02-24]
3MF/Film Masks/6x4.5.3mf
105.0 x 5.65 x 63.2 mm

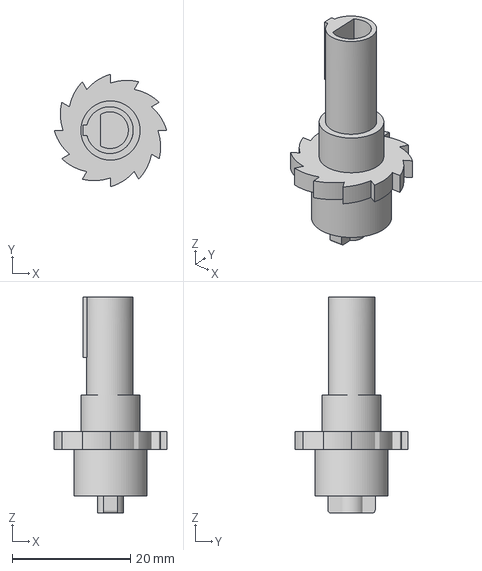
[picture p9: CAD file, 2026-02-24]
3MF/Fine Parts/advance-mech-solid (alternative to printing in parts and gluing).3mf
19.0 x 19.0 x 36.5 mm

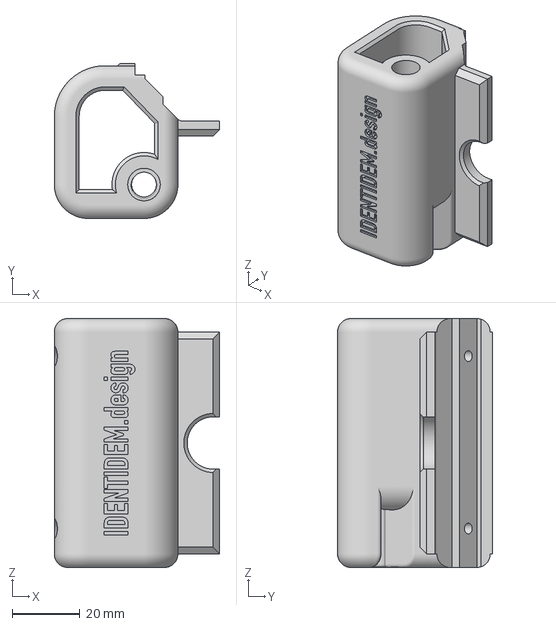
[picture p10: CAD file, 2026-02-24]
3MF/Main Parts/grip.3mf
48.7 x 45.7 x 73.4 mm

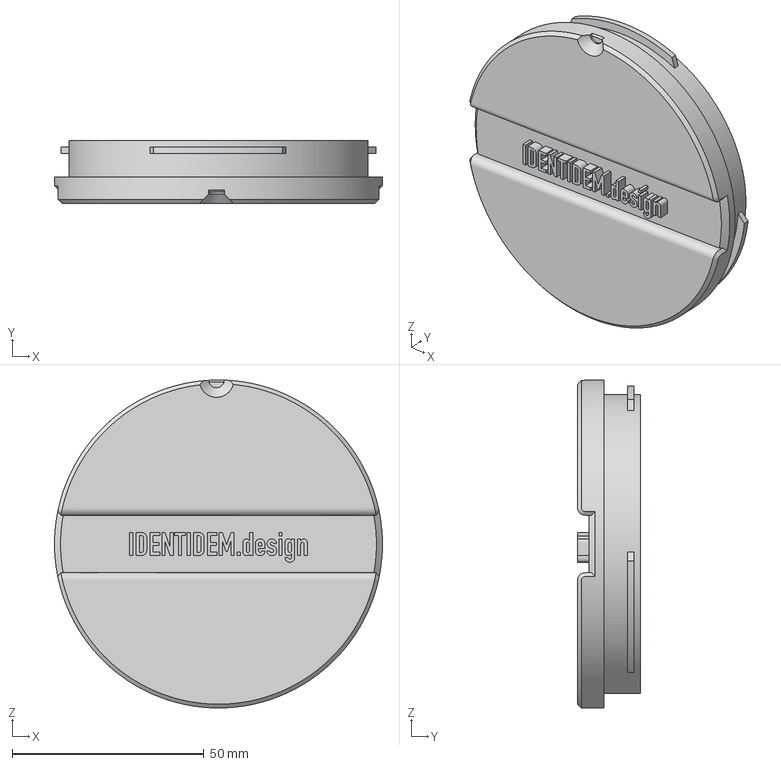
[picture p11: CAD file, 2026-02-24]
3MF/Accessories/body-cap.3mf
85.6 x 16.4 x 85.6 mm

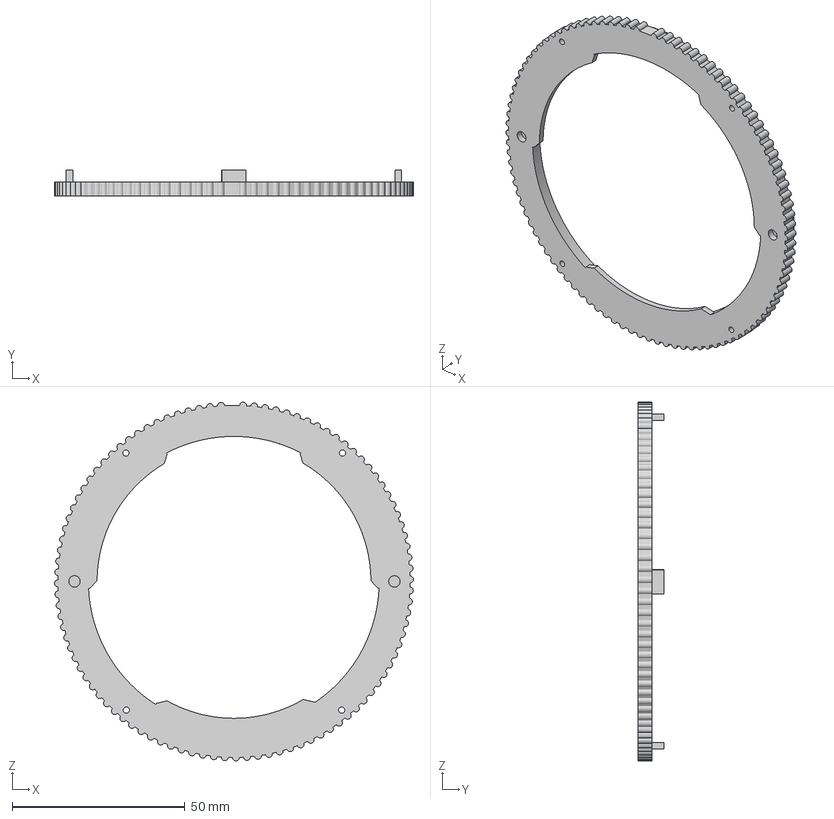
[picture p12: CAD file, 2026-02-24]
3MF/Bayonet Lens Cone/lens-top-center-ring.3mf
104.0 x 7.44 x 103.9 mm

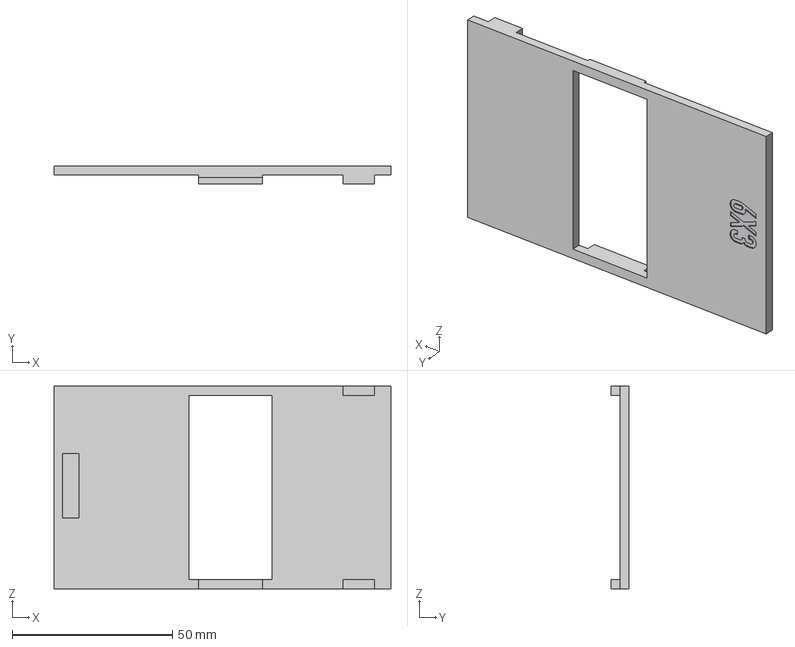
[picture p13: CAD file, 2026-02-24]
3MF/Film Masks/6x3.3mf
105.0 x 5.65 x 63.2 mm

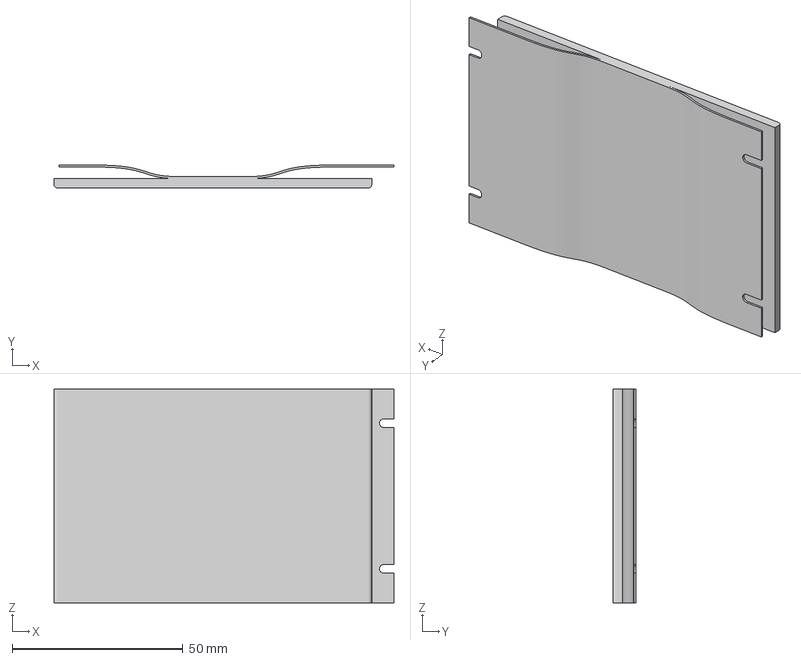
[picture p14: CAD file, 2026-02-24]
3MF/Fine Parts/pressure-plate.3mf
99.5 x 6.72 x 62.6 mm

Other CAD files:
OrcaSlicer/MRF2-complete.3mf
3MF/Main Parts/advance-lever.3mf
3MF/Bayonet Lens Cone/lens-center-ring.3mf
3MF/Film Masks/6x9.3mf
3MF/Bayonet Lens Cone/lens-top-ring.3mf
3MF/Film Masks/6x6.3mf
3MF/Film Masks/6x7.3mf
3MF/Film Masks/9x3.3mf
3MF/Fine Parts/advance-pin.3mf
3MF/Fine Parts/advance-post-bottom.3mf
3MF/Fine Parts/advance-post-top.3mf
3MF/Fine Parts/advance-ratchet.3mf
3MF/Fine Parts/advance-spring-cap.3mf
3MF/Fine Parts/left (from back) spool.3mf
3MF/Fine Parts/lidar-sensor-holder.3mf
3MF/Fine Parts/right (from back) spool.3mf
3MF/Fine Parts/spool-key (optional).3mf
3MF/Fine Parts/spring-ring.3mf
3MF/Main Parts/body-bottom.3mf
3MF/Main Parts/camera-body.3mf
3MF/Main Parts/door-back.3mf
3MF/Main Parts/middle-plate.3mf
3MF/Main Parts/viewfinder-body.3mf
STEP & F3D/MRF2-complete.f3d

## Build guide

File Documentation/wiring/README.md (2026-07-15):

# MRF2 harness wiring

Wiring reference for the two off-board harnesses you solder yourself: the **power switch + buttons** (main board connector **J4**) and the **breakout-to-LiDAR** link (breakout connector **J7**, plus the FPC ribbon between the boards).

Both board revisions are covered. **The latest firmware runs on both** — nothing here changes the firmware. The main board, connectors, and pin map are common to both revisions; only the breakout's LiDAR power path differs. If you're choosing a revision, see [Which board version?](../../README.md#which-board-version-v1-or-v2).

## Read this before you solder

These diagrams are drawn from the KiCad schematics/PCBs, but a few things are worth confirming against your physical parts — a mistake here can damage a board or the sensor:

- **Feather pin functions are not labelled in the schematics.** J1/J2 are generic headers; assignments like `J1.2 = 3.3 V`, `J2.5 = D9`, `J2.6 = D10`, `J2.11 = EN`, and `J1.14`/`J1.15` = the Serial2 UART pair come from the Adafruit Feather ESP32-S3 pinout + firmware, not from net labels. Confirm the physical header order.
- **LiDAR UART is wired 1:1.** The 6-pin LiDAR harness and the FPC ribbon run straight pin-to-pin — there is **no** TX/RX crossover. Wire J7 to the DTS6012M pin for pin, and verify pin 1 against the sensor silk.
- **The power switch is a 6-pin DPDT.** Each pole has a common (COM) and two throws; the harness uses the COM and one throw per pole, leaving two throws unused. Identify COM vs throws on your switch before wiring.
- **The DTS6012M's supplied connector needs cutting/soldering** onto the 6-pin harness for J7.
- **FPC ribbon orientation:** the diagrams assume a straight (pin *N* ↔ pin *N*) ribbon between J3 and J5. A folded/reversed cable mirrors the pinout — check your cable before power-on.

## Connectors at a glance

| Ref | Board | Pins | Type | Role |
| --- | --- | --- | --- | --- |
| J3 | Main | 8 | 0.5 mm FPC | Ribbon to breakout J5 |
| **J4** | Main | 8 | JST-SH 1.0 mm | **Power switch + 2 buttons** |
| J5 | Breakout | 8 | 0.5 mm FPC | Ribbon to main J3 |
| J6 | Breakout | 4 | JST-SH 1.0 mm | STEMMA QT / Qwiic I²C (encoder + bus) |
| **J7** | Breakout | 6 | JST-SH 1.0 mm | **DTS6012M LiDAR** |

Reference designators are identical across both revisions.

---

## 1. Power switch + buttons harness — J4

One 8-pin JST-SH connector carries the off-board power switch and both momentary buttons. The **buttons are identical on both revisions** (Left = D9, Right = D10, pressing shorts the GPIO to GND). The **switch wiring differs**: v2 adds a full shutdown pole.

### v1 (MRF-Pro-v7.5)

v1 switch and buttons harness

| J4 pin | Net | Goes to | Notes |
| --- | --- | --- | --- |
| 1 | GND | — | button common |
| 2 | GND | — | |
| 3 | GND | — | |
| 4 | RESET | Feather J1.1 | pole B ties RESET → GND to hold the MCU off |
| 5 | D10 | Feather J2.6 | Right button → GND |
| 6 | D9 | Feather J2.5 | Left button → GND |
| 7 | 3.3 V | Feather rail | pole A input |
| 8 | switched 3.3 V | FPC pin 6 → breakout | pole A output |

DPDT: **pole A** gates the breakout 3.3 V (pin 7 → pin 8); **pole B** ties the Feather **RESET** line (pin 4) to GND. The poles are ganged, so **pulling RESET to GND (OFF) also opens pole A and breaks the 3.3 V** — the MCU is held in reset and power is cut together. v8 replaced the RESET pole with the cleaner **EN** hold-off.

### v2 (MRF-Pro-v8)

v2 switch and buttons harness

| J4 pin | Net | Goes to | Notes |
| --- | --- | --- | --- |
| 1 | GND | — | pole B common / button common |
| 2 | GND | — | |
| 3 | GND | — | |
| 4 | EN | Feather J2.11 | **pole B** — OFF ties EN→GND, holds MCU in reset |
| 5 | D10 | Feather J2.6 | Right button → GND |
| 6 | D9 | Feather J2.5 | Left button → GND |
| 7 | 3.3OUT | FPC pin 6 → breakout | **pole A** out (switched 3.3 V) |
| 8 | 3.3IN | Feather J1.2 | **pole A** in (3.3 V source) |

DPDT: **pole A** switches 3.3 V (pin 8 → pin 7); **pole B** ties EN to GND. The poles are ganged, so **pulling EN to GND (OFF) also opens pole A and breaks the 3.3 V** — power and MCU-enable are cut together, fully powering the camera down (≤1 µA off). See the [power-shutdown errata](../hardware-errata/lidar-stage2-ldo-design.md) for the design rationale.

---

## 2. Breakout-to-LiDAR harness — J7

The DTS6012M plugs into the 6-pin **J7** on the breakout (1:1). Its UART reaches the Feather over the FPC ribbon. The **UART, INT, and GND wiring is identical on both revisions**; only the **two supply pins** differ — v1 shares the 3.3 V rail, v2 feeds them from a dedicated LDO.

### v1 (MRF-Pro-v7.5)

v1 breakout to LiDAR harness

| J7 pin | DTS6012M | Net | Goes to |
| --- | --- | --- | --- |
| 1 | 3V3_LASER | shared 3.3 V | breakout 3.3 V rail (FPC pin 6) |
| 2 | 3V3 (logic) | shared 3.3 V | breakout 3.3 V rail |
| 3 | UART_TX | → FPC pin 2 | main J1.14 (1:1) |
| 4 | UART_RX | → FPC pin 3 | main J1.15 (1:1) |
| 5 | INT (mode) | GND | tied low = UART mode |
| 6 | GND | GND | — |

Both supplies share one undecoupled rail — the range-limiting factor. The [hand-solder decoupling stopgap](../hardware-errata/lidar-stage1-decoupling.md) improves v1 range.

### v2 (MRF-Pro-v8)

v2 breakout to LiDAR harness

| J7 pin | DTS6012M | Net | Goes to |
| --- | --- | --- | --- |
| 1 | 3V3_LASER | `3V3_LASER` | LDO U1 → FB1 → C1 (47 µF) |
| 2 | 3V3 (logic) | `3V3_LIDAR` | LDO U1 output |
| 3 | UART_TX | → FPC pin 2 | main J1.14 (1:1) |
| 4 | UART_RX | → FPC pin 3 | main J1.15 (1:1) |
| 5 | INT (mode) | GND | tied low = UART mode |
| 6 | GND | GND | — |

The LDO (U1 TLV75533) is fed from **VBAT** on FPC pin 1 and regulates a clean 3.3 V at the sensor — this is what restores full LiDAR range. See the [LDO design doc](../hardware-errata/lidar-stage2-ldo-design.md).

### FPC ribbon (main J3 ↔ breakout J5)

The 8-pin FPC carries the LiDAR UART plus power and I²C, straight pin-to-pin. The only revision difference is **pin 1**:

| FPC pin | Signal | v1 | v2 |
| --- | --- | --- | --- |
| 1 | supply to breakout | 3.3 V | **VBAT** (feeds the LDO) |
| 2 | LiDAR UART_TX → main J1.14 | same | same |
| 3 | LiDAR UART_RX → main J1.15 | same | same |
| 4 | GND | same | same |
| 5 | GND | same | same |
| 6 | switched 3.3 V (from J4) | same | same |
| 7 | I²C SDA | same | same |
| 8 | I²C SCL | same | same |

---

*Diagrams are hand-authored SVGs built from the KiCad schematics/PCBs in `PCBs/v1.0/` and `PCBs/v2.0/`. Net names shown in `code` are real global labels in the v8 project; v7.5 uses auto-named nets for everything except GND and 3.3 V, so connectivity is authoritative but functional names there are derived from firmware and the Adafruit pinout.*

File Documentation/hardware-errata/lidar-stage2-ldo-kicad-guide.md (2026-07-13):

# Updating the boards in KiCad — LiDAR LDO (Stage 2)

> **CURRENT — Stage 2 · implementation guide.** KiCad capture steps for the design in [lidar-stage2-ldo-design.md](lidar-stage2-ldo-design.md). Start at the [errata index](README.md).

Step-by-step capture of the dedicated LiDAR regulator design. The design itself is locked in [lidar-stage2-ldo-design.md](lidar-stage2-ldo-design.md); this is the click-by-click for the KiCad GUI. The target circuit is drawn in [images/lidar-ldo-schematic.svg](images/lidar-ldo-schematic.svg) — keep it open while you work.

Two projects change:

- **Breakout** — `PCBs/v2.0/Breakout/KiCAD/MRF-Pro-v8-breakout.kicad_sch` (the real work: U1, Cin, two new nets).
- **Main board** — `PCBs/v2.0/Main PCB/KiCAD/MRF-Pro-v8.kicad_sch` (Feather BAT → FPC pin 1, plus the J4 DPDT power-switch rework: `3.3IN`/`3.3OUT`/`EN`/`GND`).

`kicad-cli` cannot author a schematic — it only runs ERC and exports. So every step below is in the GUI. Use `kicad-cli sch erc` afterwards to check.

> Before you start: commit or stash the working tree so the change is its own diff, and note that the breakout project keeps a `.history/` and a `_restore_backup_*` folder — don't edit those copies.

---

## A. Breakout schematic

Open `MRF-Pro-v8-breakout.kicad_sch` in the KiCad Schematic Editor (Eeschema).

### A1. Place U1 (the LDO)

1. Press `A` (Add Symbol). Search the part:
   - If you have a TLV75533 symbol in a library, use it.
   - Otherwise use `Regulator_Linear:AP2112K-3.3` — its SOT-23-5 pinout is **identical** to the TLV75533 DBV (`1=IN, 2=GND, 3=EN, 4=NC, 5=OUT`), so it drops in pin-for-pin. **Rename the value to `TLV75533`.**
2. Place it near J7, set reference to **U1**.
3. **Pinout (confirmed against TI datasheet SBVS320D, Table 4-1):** `1=IN, 2=GND, 3=EN, 4=NC, 5=OUT`. <https://www.ti.com/lit/ds/symlink/tlv755p.pdf>
4. Assign the footprint **`Package_TO_SOT_SMD:SOT-23-5`** (Footprint field or in the editor's symbol properties).

### A2. Place Cin (input decoupling)

1. Press `A`, add `Device:C` twice. References **Cin1** (or next free C ref) and the second cap.
   - Values: **1 µF** (0402) and **10 µF** (0805, ≥10 V).
   - Footprints: `Capacitor_SMD:C_0402_1005Metric` and `Capacitor_SMD:C_0805_2012Metric`.
2. Place both between the VBAT input and GND, next to U1's IN pin.

> The existing C1/C2/C3 stay as-is in the netlist — you are **re-targeting** them onto the output net, not adding new ones. See A5.

### A3. New net: VBAT (FPC pin 1 → U1 IN)

1. The 8-pin FPC is **J5** (`Connector:Conn_01x08_Pin`). Today pin 1 is on the `3.3V` net.
2. **Detach pin 1 from 3.3V:** delete the wire/label tying J5 pin 1 to the `3.3V` net.
3. Draw a wire from J5 pin 1 and attach a **net label `VBAT`** (press `L`).
4. Label U1's **IN** pin `VBAT` as well, and tie both Cin caps' top plates to `VBAT`, bottoms to `GND`.

Result: `J5 pin 1 — Cin — U1 IN`, all on `VBAT`.

### A4. EN slaved to switched 3.3 V (FPC pin 6)

1. J5 pin 6 stays on the existing `3.3V` net (switched Feather rail). Do **not** change pin 6.
2. Draw a wire from U1's **EN** pin and label it `3.3V` (same net name as pin 6 — KiCad joins same-named labels, no wire needed across the sheet).
3. This is what makes the camera power switch also cut the LDO. Do **not** tie EN to IN/VBAT.
4. **Add R1 (`Device:R`, 100 kΩ, `Resistor_SMD:R_0402_1005Metric`): top on `3.3V`, bottom on `GND`.** This pulls EN to 0 V at power-off — the TLV75533 has no internal EN pulldown, so without R1 EN floats on the isolated rail and shutdown is not guaranteed. Assign a JLCPCB-basic 100 kΩ 0402 LCSC part (e.g. C25741 — confirm).

### A5. New net: 3V3_LIDAR (U1 OUT → C1/C2/C3 → J7 pins 1,2)

J7 is the 6-pin DTS6012M connector. Per the [sensor datasheet](datasheets/DTS6012M-Docdt22-Rev1.2.pdf): **pin 1 = 3V3_LASER, pin 2 = 3V3** (both supply, currently on `3.3V`), pins 3,4 = UART, **pin 5 = INT (interface-mode select)**, pin 6 = GND.

There are two output nets joined by **FB1** (a 0 Ω jumper by default; populate a ferrite later only if scoping shows laser noise on the logic supply):

- **`3V3_LIDAR`** — the LDO output node: U1 OUT, the stability caps C2 (1 µF) + C3 (100 nF), J7 pin 2 (logic), and FB1's input. Keep C2/C3 here so the regulator always sees its Cout.
- **`3V3_LASER`** — past FB1: C1 (47 µF bulk) and J7 pin 1 (laser).

1. Delete J7 pin 1 and pin 2 connections from `3.3V`.
2. Label U1's **OUT** pin, C2/C3 hot plates, and **J7 pin 2** all `3V3_LIDAR` (cap bottoms to `GND`).
3. Place **FB1** (`Device:FerriteBead` or a 0 Ω `Device:R`): input on `3V3_LIDAR`, output on `3V3_LASER`. Default value **0 Ω / DNP-ferrite**.
4. Label FB1's output side, **C1** (47 µF) hot plate, and **J7 pin 1** all `3V3_LASER` (C1 bottom to `GND`).
5. In layout: C2/C3 hard against U1 OUT; **C1 hard against J7 pin 1**; FB1 between them. Add probe/test points on `3V3_LIDAR` and `VBAT`.
6. **Do not touch J7 pin 5 (INT).** It is the UART/I²C mode select, read at power-on; it must stay tied low for UART. Pins 3,4 (UART) and pin 6 (GND) are unchanged.

Result: `U1 OUT — C2‖C3 — [3V3_LIDAR] — FB1 — [3V3_LASER] — C1`, with J7 pin 2 on `3V3_LIDAR` and pin 1 on `3V3_LASER`. At FB1 = 0 Ω the two are one clean rail, fully isolated from the system `3.3V`; UART, INT, and GND untouched.

### A6. Sanity check before ERC

Confirm on the canvas (matches the SVG):

- U1 IN → `VBAT`; J5 pin 1 → `VBAT`; Cin on `VBAT`/`GND`.
- U1 EN → `3.3V`; J5 pin 6 still → `3.3V`; J6 (Stemma QT) still → `3.3V`; R1 across `3.3V`→`GND`.
- U1 OUT → `3V3_LIDAR`; C2/C3 → `3V3_LIDAR`; J7 pin 2 → `3V3_LIDAR`; FB1 between `3V3_LIDAR` and `3V3_LASER`; C1 + J7 pin 1 → `3V3_LASER`.
- J7 pins 3,4 still UART (from J5 pins 2,3); J7 pin 5 (INT) still tied low; J7 pin 6 + J5 pins 4,5 still `GND`; J5 pins 7,8 still I²C → J6.

Run **Inspect → Electrical Rules Checker**. Expect a few "power pin not driven" warnings unless a `PWR_FLAG` sits on `VBAT`, `3V3_LIDAR`, and `3V3_LASER` — add a `power:PWR_FLAG` to each new net to clear those.

---

## B. Main board schematic

Open `MRF-Pro-v8.kicad_sch`.

The Feather ESP32-S3 is modeled as **generic header connectors** (J1/J2); the FPC to the breakout is **J3**; the power switch lands on the 8-pin header **J4**. Match Feather pin positions to the Adafruit Feather ESP32-S3 pinout — the generic symbol won't label BAT/EN for you.

**BAT → FPC pin 1:**

1. Find the header pin for **BAT** (it is **J2 pin 12**). Draw a wire and label it **`VBAT`**.
2. Label the FPC **pin 1** conductor (J3 pin 1) **`VBAT`**. On the prior board pin 1 was driven from a Feather GPIO (D11), not `3.3V` — see the topology note in the design doc.

**J4 DPDT power switch** (the prior board sent FPC pin 1 from a GPIO and never routed Feather 3.3 V to the FPC; this rework fixes that):

1. `3.3IN` (Feather, J1 pin 2) → **J4 pin 8** — pole A input.
2. **J4 pin 7** → FPC **pin 6** (J3 pin 6), labeled **`3.3OUT`** — pole A output, the switched 3.3 V the breakout uses for U1 EN + J6.
3. Feather **EN** (J2 pin 11) → **J4 pin 4**, labeled **`EN`** — pole B; the off position ties this to GND.
4. **J4 pins 1, 2, 3** → `GND` — pole B return / switch common.

Run ERC on the main board too.

---

## C. Verify (CLI)

From each project's KiCad dir (the macOS binary lives inside `KiCad.app/Contents/MacOS/`):

```bash
kicad-cli sch erc MRF-Pro-v8-breakout.kicad_sch
kicad-cli sch erc "MRF-Pro-v8.kicad_sch"
```

Netlist must show:

Breakout:

- U1 IN on `VBAT`
- U1 OUT + C2 + C3 + J7 pin 2 on `3V3_LIDAR`; FB1 → C1 + J7 pin 1 on `3V3_LASER`
- U1 EN on the FPC pin-6 switched rail (labeled `3.3V` on the breakout sheet)
- J6 still on that same rail

Main board:

- Feather BAT (J2.12) on `VBAT` → FPC pin 1 (J3.1)
- J4 DPDT: `3.3IN`={J1.2, J4.8}; `3.3OUT`={J4.7, J3.6=FPC pin 6}; `EN`={J2.11, J4.4}; `GND`={J4.1, J4.2, J4.3, …}

---

## D. PCB layout (after schematic ERC passes)

Open each `.kicad_pcb`, **Tools → Update PCB from Schematic** to pull in U1 + Cin and the renamed nets, then:

- Place **U1 next to J7** so `3V3_LIDAR` is made at the sensor; keep C1/C2/C3 within a few mm of J7.
- Keep Cin tight to U1's IN pin.
- Pour/route `3V3_LIDAR` and `GND` generously near the sensor; stitch GND vias.
- Run **DRC**, then regenerate fab outputs.

Full layout intent is in [lidar-stage2-breakout-layout.md](lidar-stage2-breakout-layout.md).

---

## Done-when

- ERC clean on both boards (only intentional `PWR_FLAG`-resolved power warnings).
- Netlist matches section C.
- DRC clean after layout.
- Field verification per [lidar-stage2-ldo-design.md](lidar-stage2-ldo-design.md#verification): scope J7 VCC under laser load, confirm cold-start boot, off-state battery current ~µA.

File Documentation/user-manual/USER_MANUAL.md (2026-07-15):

# MRF2 User Manual

**Firmware version:** 10.7.0

This manual covers how to operate the MRF2 firmware user interface, including the on-device displays, buttons, calibration flow, and film counter behavior. It is written for everyday use, not just for builders.

## Contents

- [First-time setup (recommended order)](#first-time-setup-recommended-order)
- [Quick start (after initial setup)](#quick-start-after-initial-setup)
- [Controls](#controls)
- [Displays and status LED](#displays-and-status-led)
- [Main screen](#main-screen)
  - [Portrait leveling](#portrait-leveling)
  - [Distance readouts](#distance-readouts)
  - [LiDAR quality indicator](#lidar-quality-indicator)
  - [Light meter / shutter speed](#light-meter--shutter-speed)
  - [How to focus](#how-to-focus)
- [Setup menus](#setup-menus)
  - [Setup root menu](#setup-root-menu)
  - [Film submenu](#film-submenu)
  - [Lens Settings submenu](#lens-settings-submenu)
  - [Light Meter submenu](#light-meter-submenu)
  - [LiDAR submenu](#lidar-submenu)
  - [Display submenu](#display-submenu)
  - [System Health screen](#system-health-screen)
  - [ISO list](#iso-list)
  - [Film formats](#film-formats)
- [Lens calibration](#lens-calibration)
  - [How it works](#how-it-works)
  - [Before you start](#before-you-start)
  - [Step 1: Select lens](#step-1-select-lens)
  - [Step 2: Capture distance points](#step-2-capture-distance-points)
  - [Distance point sequences](#distance-point-sequences)
  - [Completion](#completion)
- [Reset film counter](#reset-film-counter)
- [External display](#external-display)
- [Sleep mode](#sleep-mode)
- [Default startup settings](#default-startup-settings)
- [Troubleshooting](#troubleshooting)
- [Firmware updates](#firmware-updates)

## First-time setup (recommended order)

If this is your first time using the camera, this sequence keeps things simple and predictable:

1. Make sure the camera is switched off.
2. Mount the lens you plan to use.
3. Load your film, aligning the arrow on the backing paper to the arrow on the top-left edge of the film chamber.
4. Close and secure the film door, then switch on the camera.
5. Long-press **Right (R)** to enter **Setup**, open **Lens >**, then run **Lens Calibration** for the mounted lens.
6. Still in **Setup**, open **Film >** to set frame size, open **Meter >** to set ISO, open **LiDAR >** to set the **Idle timeout**, then open **Display >** to set your preferred **Sleep timeout** and horizon trim values.
7. From **Setup > Film**, select **Reset frame counter >>** so the frame counter starts at zero.
8. Use the **advance lever** to wind to frame 1. This takes a little while. Power through!

## Quick start (after initial setup)

1. Power on the camera. The main display shows an "Initialising..." progress bar with a label naming each peripheral group as it starts up, the external display plays a short film-advance animation that carries the firmware version into view, and then the main UI appears.
2. Check the **main screen** for ISO, aperture, shutter speed, LiDAR distance, LiDAR quality blocks, and lens distance.
3. Long-press **Right (R)** for 3 seconds to enter **Setup** and make changes.
4. Use the **advance lever** to move the film; the external display shows the frame counter and progress bar.

## Controls

- **Left button (L)**
  - Short press (< 1s): on the main screen, cycles apertures downward through the selected lens; in menus, moves to the next item.
- **Right button (R)**
  - Short press (< 1s): on the main screen, cycles apertures upward through the selected lens; in menus, selects or confirms the highlighted item.
  - Long press (>= 3s): enters Setup from the main screen.
- **Advance lever**
  - Used for film advance tracking. Each lever stroke increments the film counter and updates the progress bar.

## Displays and status LED

- **Main display (128x128)**: primary viewfinder UI.
- **External display (128x32)**: format, lens, battery, film counter, progress bar, and sleep text.
- **NeoPixel status LED**
  - Blue: no frame progress detected yet.
  - Red -> green gradient: progress between frames.
  - Violet: "Load film." or "Roll end."
  - Off: sleep mode.

## Main screen

Main screen example

The main screen displays:

- **ISO** (upper left)
- **Aperture** (upper center-left)
- **Shutter speed** (lower left)
- **LiDAR distance** (upper right, labeled "Dist") — a small sun glyph appears just before the quality blocks when ambient infrared is high enough to degrade the LiDAR (e.g. shooting horizontally toward bright sky in full sun). The reading may be less reliable while the glyph is visible; expect occasional drop-outs or slightly wider noise.
- **LiDAR quality indicator** (4 small squares in a vertical stack at the right edge of the status bar)
- **Lens distance** (lower right, labeled "Lens")
- **Framelines** scaled to the selected film format
- **Reticle and focus ring**
- **Level line** (horizon aid)
- **Adaptive orientation leveling** (landscape and portrait)

### Portrait leveling

When the camera is rotated to portrait orientation, the level aid automatically rebases to portrait behavior.
You can tune horizon trim offsets independently for **Landscape**, **Portrait+**, and **Portrait-** in **Setup > Display > Horizon trim >**.

Main screen portrait leveling

### Distance readouts

- **LiDAR distance (Dist)**
  - Uses LiDAR v2 primary/secondary returns with confidence scoring and correction for more stable readings.
  - Confidence accounts for ambient sunlight relative to return intensity. Thresholds are tuned for outdoor use in bright conditions, and the sensor falls back to low-confidence tracking at all ranges when primary filtering rejects a return.
  - Measurement range: 5 cm to 18 m.
  - Displays values below 1 meter in centimeters (for example, `75cm`), 1m to below 2m in meters with two decimal places (for example, `1.85m`), and 2m and above with one decimal place (for example, `2.5m`).
  - Displays `Inf.` for measured readings above 18 metres (the display's infinity cutoff; the sensor itself is rated to 20 m).
  - Displays `Inf?` when the signal is lost and the last reading was above 3 m — usually the camera is now aimed at the sky or something beyond sensor range. The question mark marks it as a guess, not a measurement.
  - Displays `...` if the sensor has no valid data for 1 second at close range.
  - Displays `Zzz` when LiDAR is in idle standby (wake by focusing or pressing a button).
  - Displays `<15cm` for near readings below display threshold.
  - The label changes from `Dist:` to `Held:` in two cases: when the lens is focused close and the LiDAR briefly reports something much farther away (usually the beam slipping past your subject to the background), or briefly during the first moment of a signal dropout before it falls back to `...`/`Inf?`. Either way the previous reading is held rather than jumping or blanking. For the beam-slip case, aim deliberately at the farther subject for a moment and it releases to the live value.
- **Lens distance (Lens)**
  - Based on calibration and the lens position sensor.
  - Displays `Inf.` when beyond the calibrated infinity threshold.

### LiDAR quality indicator

The four tiny squares at the right edge of the top status bar show return quality for the currently selected LiDAR reading:

- **1 square**: Poor
- **2 squares**: Fair
- **3 squares**: Good
- **4 squares**: Excellent

When no valid recent LiDAR data is available (`Dist: ...` or `Dist: Inf?`) or LiDAR is in idle standby (`Dist: Zzz`), the quality indicator clears.

### Light meter / shutter speed

The light meter always runs in **aperture-priority** mode: you choose the aperture (via L/R in normal operation), and the firmware suggests a shutter speed.

The firmware uses the BH1750 light meter, ISO, and aperture to compute shutter speed:

- Shows `Bright!` if the computed speed is too fast.
- Shows `Dark!` if light level is near zero.
- Otherwise shows a shutter speed like `1/125 sec.` or `1.3 sec.`

### How to focus

The MRF2 gives you two independent distance readouts — **LiDAR distance** (measured to the subject) and **Lens distance** (read from the focus ring position) — plus a visual **focus ring** that shows how well they agree. Together they let you focus quickly and confirm accuracy without a split-image or ground-glass screen.

#### Basic workflow

1. **Point the camera at your subject.** The LiDAR distance appears in the top-right corner of the main screen (e.g. `2.5m`). The quality indicator shows how confident the reading is.
2. **Turn the focus ring** until the Lens distance (bottom-right) matches the LiDAR distance. As the two readings converge the focus ring shrinks toward the reticle.
3. **When the ring is at its smallest**, the lens is focused at the measured distance. Compose and shoot.

#### Reading the focus ring

The focus ring is a circle drawn around the centre reticle. Its size and thickness tell you how far off focus you are:

- **Large ring** — the lens is focused far from the subject. Keep turning.
- **Small, thin ring** — the lens and LiDAR distances are close. You are in focus or very near it.
- **Minimum size (tight dot)** — the two distances match within 5 cm. Focus is confirmed.

The ring radius is based on the difference between the LiDAR distance and the lens distance, compared in 5 cm steps and clamped to the display area. The thickness scales with the radius so it stays visible at all sizes.

#### Tips

- **Use the LiDAR number first, then fine-tune with the ring.** Glance at the `Dist` readout to get a ballpark, dial the focus ring close, then watch the ring shrink for the last adjustment.
- **Calibrate your lens** before relying on Lens distance. Without calibration the Lens readout is inactive and the ring defaults to maximum size. See [Lens calibration](#lens-calibration).
- **In bright sunlight** the LiDAR may occasionally lose signal. The last valid reading is held for 1 second, so brief dropouts are hidden. When the signal is lost beyond 3 m the display switches to `Inf?`. If `...` persists at close range, check wiring or try a different target angle.
- **At infinity** the Lens readout shows `Inf.` and the LiDAR readout shows `Inf.` above 18 m (the display's infinity cutoff; the sensor itself is rated to 20 m), or `Inf?` when far-range signal is lost. The focus ring is irrelevant at infinity — just set the ring to the ∞ mark.
- **Parallax correction** shifts the framelines based on focus distance. Keep it enabled (default) for accurate framing at close range. It has no effect at infinity.

## Setup menus

Enter Setup by **long-pressing Right (R)** from the main screen.

### Setup root menu

Setup root menu

**Navigation rules**

- **L short press**: move to the next menu item.
- **R short press**: change the highlighted value or enter the selected submenu.

**Setup root items**

1. **Film: _format_ >**: opens film submenu. Shows the active film format (e.g. `6x7`).
2. **Lens: _name_ >**: opens lens submenu. Shows the active lens (e.g. `65/6.3`).
3. **Meter: ISO_value_ >**: opens light meter submenu. Shows the active ISO (e.g. `ISO400`).
4. **LiDAR >**: opens LiDAR submenu (distance offset + idle timeout).
5. **Display >**: opens display submenu (brightness, horizon, sleep, reticle).
6. **System Health >**: opens diagnostics screen.
7. **Exit >>**: return to the main screen.

### Film submenu

Film settings menu

The header reads **Setup > Film** so you always know where you are.

1. **Format**: cycles film formats.
2. **Current frame**: manually set frame counter for the selected format.
3. **Reset frame counter >>**: confirm film counter reset.
4. **Frame counter tuning >**: enter the frame-counter fine-tuning sub-page (offset and spacing — rarely needed once a format is dialled in).
5. **Back <<**: return to setup root menu.

#### Frame counter tuning sub-page

1. **Frame 1 offset**: shifts where frame 1 starts (`-10` to `+10`, default `0`).
2. **Frame spacing**: adjusts spacing between frames (`-10` to `+10`, default `0`).
3. **Back <<**: return to the Film submenu.

Current frame ranges are format-bound:

- **PANO**: `0..20`
- **3x6**: `0..21`
- **6x4.5**: `0..16`
- **6x6**: `0..12`
- **6x7**: `0..10`
- **9x3**: `0..8`
- **6x9**: `0..8`

### Lens Settings submenu

Lens settings menu

1. **Lens**: cycles calibrated lenses only.
2. **Parallax correction**: toggle on/off.
3. **Focus offset**: per-camera focus fine-tune in ADC counts (`-25` to `+25`, default `0`), applied in Main mode only. Aligns the distance readout without a full recalibration; the stored calibration table is unchanged.
4. **Lens Calibration >**: enter calibration workflow.
5. **Back <<**: return to setup root menu.

### Light Meter submenu

Light meter settings menu

1. **ISO**: cycles ISO values.
2. **EV Comp**: adjust exposure compensation in 1/3-stop steps.
3. **Smoothing**: cycles `Off`, `Low`, `Medium`, `High`.
4. **EV Readout**: toggle EV display on/off on main screen.
5. **Back <<**: return to setup root menu.

### LiDAR submenu

LiDAR settings menu

1. **Distance offset**: cycles the LiDAR distance correction in `10mm` steps from `0mm` to `800mm` (default `400mm`). Compensates for the physical offset between the LiDAR sensor and the lens plane so the displayed distance matches reality. Tune by aiming at a target a known distance away (e.g. a tape measure at 1.00m) and adjusting until the **Dist** readout on the main screen agrees. Changes take effect immediately — no reboot needed.
2. **Idle timeout**: cycles `Off`, `15s`, `30sec`, `1m`, `1m30s`, `2m` (default `1m`). Time of no measured-distance change before the LiDAR enters its low-power standby.
3. **Diagnostics >>**: opens a live telemetry screen for troubleshooting LiDAR range and lock problems (see below).
4. **Back <<**: return to setup root menu.

#### LiDAR Diagnostics screen

LiDAR diagnostics screen

Aim the camera at a target and read back exactly what the sensor reports, frame by frame. Use this when the LiDAR will not lock or seems short-ranged, and when reporting a problem so a maintainer has real numbers to work from. Press either button to return.

- **Raw** — the sensor's reported distance in millimetres. This already includes your **Offset** setting (the sensor library adds it before reporting), but not the camera's near-range correction curve. When comparing Raw values between two cameras, make sure both use the same Offset. **Disp** is what the main screen would show.
- **Intensity** — strength of the returned pulse. Low intensity at distance means little light is coming back (dark or distant subject).
- **SunBase / SNR** — the ambient infrared baseline and the signal-to-noise ratio (in permille). High SunBase with low SNR is bright-light interference.
- **Quality** — the sensor's own quality grade, 0 (none) to 4 (excellent).
- **Held** — `Y` when the plausibility gate is holding the reading because it overshot the lens focus distance (see the `Held:` note above).
- **fps req / act** — the frame rate the firmware requested versus what the sensor reported back. A lower frame rate gives the sensor longer to integrate, which can extend range.
- **Age** — how long ago the values on this screen were captured. Normally a few tens of milliseconds; a climbing Age means the sensor has stopped producing frames and everything above is stale. `--` means no frame has arrived since boot.
- **err / Recov / Sun** — last sensor error code, recovery count, and the high-sunlight flag.

If you can read close objects but never distant ones — especially outdoors — see [Troubleshooting](#troubleshooting); this is often a sensor power-supply issue with a documented hardware fix.

### Display submenu

Display settings menu

1. **Bright mode**: display brightness mode (`Auto` scales with ambient light from the light meter; `Manual` sets a fixed level; default `Auto`).
2. **Bright top** (if Auto): maximum brightness ceiling (`50%`–`100%` in `10%` steps, default `100%`). Displayed as **Bright level** if Manual: fixed brightness (`5%`–`100%` in `5%` steps, default `100%`).
3. **Horizon line**: toggle the horizon/level indicator on the main viewfinder screen (`On`/`Off`, default `On`).
4. **Sleep timeout**: cycles `Off`, `15s`, `30sec`, `1m`, `1m30s`, `2m` (default `1m30s`).
5. **Horizon trim >**: enter horizon-trim sub-page (independent landscape and portrait offsets).
6. **Focus reticle >**: enter visual reticle offset adjustment (see below).
7. **Back <<**: return to setup root menu.

#### Horizon trim sub-page

1. **Landscape**: landscape trim offset (`-30deg` to `+30deg`, `2.5deg` steps, default `0deg`).
2. **Portrait+**: portrait trim offset for one portrait side (`-30deg` to `+30deg`, `2.5deg` steps, default `0deg`).
3. **Portrait-**: portrait trim offset for the opposite portrait side (`-30deg` to `+30deg`, `2.5deg` steps, default `0deg`).
4. **Back <<**: return to the Display submenu.

#### Focus reticle adjustment

Focus reticle adjustment

This screen lets you visually align the focus reticle to the camera's optical centre. The current X/Y offsets are shown at the top with a `>` marker on the active axis. A small reference crosshair marks the unmodified centre so you can see how far the dot has moved; the dot snaps onto the crosshair when both offsets are zero.

1. **Horizontal**: press **L** to move left, **R** to move right. **Long press either button** to advance to vertical adjustment.
2. **Vertical**: press **L** to move up, **R** to move down. **Long press either button** to save the new offsets and return to the Display submenu.

Offsets are stored in non-volatile memory and survive reboots. Range: -20 to +20 pixels in each axis.

##### Calibrating the reticle position

The LiDAR emits an infrared (IR) laser dot that you can't see with the naked eye but most digital cameras can. Use this to align the on-screen reticle with where the LiDAR is actually pointing:

1. Set up a focus target with a clear centre mark (e.g. a printed crosshair or "+") at a few metres' distance.
2. Aim the camera so the LiDAR dot lands on the centre of the focus target. View the IR dot through a phone camera or any digital camera without an IR-cut filter — most front-facing phone cameras work; some rear cameras filter IR too aggressively to see it.
3. With the IR dot held on the target centre, enter **Setup > Display > Focus reticle >** and adjust the on-screen reticle until it sits over the same point on the camera's view as the IR dot.
4. Long-press to save.

Only do this if the reticle and LiDAR dot disagree noticeably; the factory default offset is usually close enough for most users.

### System Health screen

System health screen

Shows quick diagnostics:

- Firmware version (`FW`)
- Preferences schema status (`Prefs`)
- LiDAR sensor and enabled status, plus last error code
- LiDAR recovery count
- Hardware peripheral flags — `1` = ready, `0` = not detected:
  - `D` main display, `X` external display, `A` lens ADC (ADS1015), `M` accelerometer (MPU6050)
  - `L` light meter (BH1750), `B` battery gauge (MAX17048), `E` encoder, `P` status pixel

Controls:

- **L**: return to Setup.
- **R short**: if LiDAR failed to initialise (`InitErr`), re-attempts LiDAR initialisation without a power cycle. Otherwise returns to Setup.
- **R long** (3s): enters the **Factory Reset** confirmation screen. Confirming clears all saved settings (lens calibrations, film counter, ISO, sleep timeouts, etc.) and reboots the device with defaults. This is useful for troubleshooting corrupted preferences or preparing the camera for a new user.

### ISO list

Available ISO values:

- 50, 80, 100, 125, 200, 400, 500, 640, 800, 1600, 3200, 6400

### Film formats

- PANO (65 x 24)
- 3x6 (30 x 56)
- 6x4.5 (42 x 56)
- 6x6 (56 x 56)
- 6x7 (70 x 56)
- 9x3 (90 x 30)
- 6x9 (84 x 56)

## Lens calibration

Calibration teaches the MRF2 how the physical position of your lens's focus ring maps to real-world focus distances. An analog position sensor reads where the ring sits, and calibration records a series of sensor values at known distance markings. Once calibrated, the firmware interpolates between these points to display real-time focus distance and drive the focus-ring indicator on the main screen.

### How it works

Each lens has a set of distance markers engraved on its focus ring (for example, 1 m, 1.2 m, 1.5 m, 2 m, 3 m, 5 m, 10 m). During calibration, you physically turn the focus ring to each marked distance in order from closest to farthest and press a button to capture the sensor reading at that position. The readings must increase monotonically — each point must produce a higher sensor value than the last — because the ring moves in one direction from near to far.

After all points are captured, the MRF2 saves a lookup table pairing sensor values to distances. During normal use, it reads the sensor, finds where the current value falls in the table, and interpolates the corresponding distance. This is what appears as the **Lens distance** readout and what sizes the focus ring in the viewfinder.

### Before you start

- Mount the lens you want to calibrate.
- Make sure the focus ring moves freely and the position sensor cable is connected.
- Know where the distance markings are on your lens barrel.

### Step 1: Select lens

Calibration - select lens

Navigate to **Setup > Lens > Lens Calibration**. The calibration screen shows the currently selected lens.

- **L**: cycle through available lenses
- **R**: confirm lens selection and begin capture

### Step 2: Capture distance points

Calibration - capture distance

The screen shows the target distance, the live sensor reading, and a progress counter (e.g. "3/7"). A full-width progress bar beneath the distance line tracks how many points have been captured.

For each target distance:

1. Turn the lens focus ring until it aligns with the distance marking on the lens barrel.
2. Hold the ring steady.
3. Press **L** to capture. The LED flashes green to confirm a successful reading.

When the final point is captured, a full-screen success message is shown and the LED pulses green three times. The message is held for 1.5 seconds before returning to the Lens settings menu with the calibrated lens selected.

Calibration complete

If a capture fails, the screen shows a specific error and holds it for at least 2 seconds so you can read it:

- **"Unstable reading / Hold lens still and retry"** — the sensor values varied too much during sampling. Keep the ring stationary and press **L** again.
- **"Out of sequence / Increase focus distance"** — the new reading was not higher than the previous one. The focus ring must move progressively from near to far. Turn it further towards infinity and retry.

Controls during capture:

- **L**: capture current reading and advance to the next distance
- **R**: cancel calibration and return to **Setup > Lens**

### Distance point sequences

Distance points are lens-specific. The calibration UI shows the exact sequence for the selected lens:

- **Default** (50/6.3, 65/6.3, 75/5.6, 90/3.5, 100/3.5, 100/2.8, 127/4.7): **1, 1.2, 1.5, 2, 3, 5, 10 m**
- **150/5.6**: **2, 2.5, 3, 5, 10 m**
- **250/5.0**: **2.5, 4, 5, 7, 8, 10, 15, 20, 30, 50 m**
- **250/8.0**: **3.5, 4, 5, 7, 10, 15, 20, 30, 50 m**

### Completion

When all distances are captured, the lens is automatically marked as calibrated, the calibration data is saved to preferences, and you return to the Lens Settings menu. The lens is now selectable from the main Lens picker and its distance readout is active on the main screen.

## Reset film counter

Reset frame counter confirmation

- **L**: cancel
- **R**: reset the film counter and return to the main screen

## External display

External display example

The external display shows:

- **Header:** format, lens, battery percentage
- **Progress bar:** advance progress between frames
- **Counter:** frame number, "Load film.", or "Roll end."

### Counter behaviors

- **Load film.** appears when the counter is at 0 and film needs advancing to frame 1.
- **Roll end.** appears when the whole film is on the take-up spool and _should_ be safe to remove.
- **Numeric counter** appears for frame one to last frame.

## Sleep mode

In Main mode, LiDAR enters low-power standby after the configured **LiDAR idle timeout** period (default **1 minute**) and wakes automatically on user activity. While idle standby is active, the main display shows `Dist: Zzz`.

After the configured **Sleep timeout** period of inactivity (default **1 minute 30 seconds**, set in **Setup > Display >**), the firmware enters sleep mode:

- Main display fades to black over ~200 ms, then powers off.
- LiDAR turns off.
- External display shows a sleeping face graphic.
- Status LED is off.

Sleep screen

Wake the device by pressing any button or moving the lens/advance lever (any activity resets the sleep timer).

## Default startup settings

- ISO: **400**
- Format: **6x7**
- Lens: **65/6.3** (pre-calibrated)
- Parallax correction: **On**
- Sleep timeout: **1m30s**
- LiDAR idle timeout: **1m**

## Troubleshooting

- **LiDAR distance shows `Inf.`**
  - The sensor measured a distance above 18 m, the display's infinity cutoff (the sensor itself is rated to 20 m). Use the lens barrel distance markings instead.
- **LiDAR distance shows `Inf?`**
  - The signal was lost while the last reading was beyond 3 m — usually the camera is aimed at the sky or at something too far or too dark to return a pulse. It is a guess, not a measurement. Use the lens barrel distance markings instead.
- **LiDAR distance shows `...`**
  - At close range, verify LiDAR wiring and power. The UI updates only with valid sensor data.
- **LiDAR only reads close objects — nothing at distance, worse outdoors or in bright light**
  - Open **Setup > LiDAR > Diagnostics** and aim at a distant target. If Intensity stays very low and Quality stays at 0–1 while SunBase is high, the sensor is not getting a usable return.
  - This pattern (close reads fine, distance/bright-light fails) is commonly a sensor power-supply problem: the LiDAR's pulsed laser briefly starves its 3.3 V rail because the board has no local decoupling capacitor at the connector. There is a documented hardware fix — see [LiDAR power decoupling errata](../hardware-errata/lidar-stage1-decoupling.md).
  - To gather data for a maintainer, follow the [LiDAR field test protocol](../hardware-errata/lidar-field-test.md).
- **LiDAR distance shows `Zzz`**
  - LiDAR is in idle standby. Turn the focus ring or press a button to wake it, or increase/disable **Idle timeout** in **Setup > LiDAR >**.
- **LiDAR quality stays at 1 square (Poor)**
  - Check subject reflectivity/angle and ambient interference; low-SNR returns under strong sunlight are accepted at lower confidence and may update more slowly through temporal blending.
- **Shutter speed reads `Bright!` or `Dark!`**
  - Adjust ISO and/or aperture, or verify the light meter sensor.
- **Lens option does not show your lens**
  - Only calibrated lenses are selectable. Run Lens Calibration first.
- **Film counter does not increment**
  - Verify the advance lever mechanism and that it is registering motion from lever strokes.

## Firmware updates

### Browser updater

Browser updater

- Open `https://update.mrf2.com/` in desktop Chrome or Edge.
- **Version To Install** defaults to the latest published firmware.
- **Release Notes (Current + Previous)** shows notes for the selected version and the version immediately before it.
- Use **View full changelog** for complete details.

### VS Code / PlatformIO method

For local flashing or development workflows, see `Documentation/flash-firmware/README.md` in the repo root.

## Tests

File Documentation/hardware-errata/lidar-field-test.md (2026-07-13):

# LiDAR field test protocol

> **Reference · all stages.** Diagnostic protocol for gathering comparable before/after range data for any of the fixes. Start at the [errata index](README.md).

Thank you for helping diagnose the LiDAR range issue. The goal is to get consistent, comparable numbers from every tester so we can tell apart three possible causes (the focus-distance plausibility gate, the sensor's frame rate / integration time, and a board power-supply problem). Please follow the steps exactly and record every value, including "no reading" — a blank tells us nothing, but "no reading" is real data.

Everything you need is on the new **Setup > LiDAR > Diagnostics** screen. Aim the camera, hold steady, and read the live values off that screen.

## 1. Fill in once

| Field | Your value |
|---|---|
| Tester name / unit ID | |
| Firmware version (Health screen) | |
| Sensor FW hex (Health screen) | |
| Hardware: stock, or which cap mod fitted? (none / P1 caps / P3 source cap / P4 flying wire) | |
| LiDAR offset setting (Setup > LiDAR > Offset; default 400 mm) | |
| Unit role: reference (known-good) or test | |
| Date | |

**About the offset:** the Raw value on the Diagnostics screen already includes your offset setting, so two cameras with different offsets are not comparable. If you have changed the offset, either note it above or set it back to 400 mm for the test.

## 2. Setup rules (so runs are comparable)

- Battery above 50% (a low cell can cause its own brownout).
- After waking the camera, wait ~10 seconds before the first reading.
- For each reading, aim the reticle at the centre of the target, hold steady ~2 seconds, and record the value once it stops changing.
- For each reading, note the lens focus distance you set (this matters — see the focus rule below).
- Check the **Age** field before writing anything down. It should read a few tens of milliseconds; if it is climbing (seconds), the sensor has stopped sending frames and the other values are stale — write "stale" in Notes instead of the numbers.

## 3. Main test matrix

Repeat the whole table in **three lighting conditions**: (A) indoors under artificial light, (B) outdoors in open shade, (C) outdoors in direct sun.

Targets:
- **W** = a white / light matte wall
- **P** = a person or a mid-grey object
- **D** = a dark / low-reflectivity object

Ranges: **0.3 m, 1 m, 2.5 m, 5 m, 8 m, 12 m.**

**Focus rule:** for the 5 m, 8 m and 12 m rows, take each reading **twice** — once with the lens focused *at* the target, and once with the lens focused *near (minimum)*. Label them "focus far" / "focus near". (This is the only way to separate the focus-distance gate from a genuine sensor limit.)

For every cell record, from the Diagnostics screen:

| Target | Range | Lighting | Focus | Raw (mm) | Disp | Intensity | SunBase | SNR | Quality | Held | err | Notes |
|---|---|---|---|---|---|---|---|-----|---|---|-----|---|
| W | 0.3m | A | — | | | | | | | | | |
| W | 1m | A | — | | | | | | | | | |
| W | 2.5m | A | — | | | | | | | | | |
| W | 5m | A | far | | | | | | | | | |
| W | 5m | A | near | | | | | | | | | |
| W | 8m | A | far | | | | | | | | | |
| W | 8m | A | near | | | | | | | | | |
| W | 12m | A | far | | | | | | | | | |
| W | 12m | A | near | | | | | | | | | |

…then repeat the same nine rows for target **P** and target **D**, and repeat the whole block for lighting **B** and **C**. Copy the table as many times as you need. If there is no reading at all, write "none" in the Disp column and still record Intensity / SunBase / Quality.

## 4. Near-range calibration sweep (tape measure needed)

The firmware applies a correction curve below 1.5 m that was derived from a single measured point, and we need real pairs to replace it. This sweep is the data that fixes it — it needs only one target and one room.

Indoors, against the white wall (**W**), measure the true distance from the **front of the lens** to the wall with a tape measure. Lens focus set roughly at the target each time. Record:

| True (tape) | Raw (mm) | Disp | Intensity | Quality | Notes |
|---|---|---|---|---|---|
| 0.3 m | | | | | |
| 0.5 m | | | | | |
| 0.75 m | | | | | |
| 1.0 m | | | | | |
| 1.25 m | | | | | |
| 1.5 m | | | | | |

Accuracy of the tape measurement matters here — please measure to the centimetre, don't pace it out.

## 5. Beam-miss check (subject close, background far)

This verifies the focus-distance plausibility gate. Stand a person (or a chair) at **1 m**, with a wall or other large surface **3–5 m** behind them. Lens focused at the subject (~1 m).

1. Aim the reticle at the subject's centre. Record Disp / Quality / Held.
2. Deliberately aim just past their shoulder so the beam hits the background. Record what Disp does over ~3 seconds (jumps to the wall instantly / shows `Held:` then releases / sticks on the subject), plus Quality and Held.
3. Aim back at the subject. Record how quickly the reading returns.

| Step | Disp | Quality | Held | What it did (own words) |
|---|---|---|---|---|
| 1 — on subject | | | | |
| 2 — past shoulder | | | | |
| 3 — back on subject | | | | |

## 6. Frame-rate sweep (if we send you alternate firmware)

If you have been given firmware builds at different frame rates, repeat just the **W** and **P** columns at each rate. Confirm the rate on the Diagnostics screen (`fps act`) before each run.

| Rate (fps act) | Best range on W | Best range on P | Notes |
|---|---|---|---|
| 50 | | | |
| 30 | | | |
| 15 | | | |

## 7. Hardware A/B (only if you can solder)

If you fit the cap mod from the [decoupling errata](lidar-stage1-decoupling.md): run the full Section 3 matrix once **before** fitting, then again **after**, on the same day with the same targets. Note which mod you fitted in the Section 1 header.

## 8. Reference unit comparison (if you have a known-good camera)

If you have a unit that already ranges well (e.g. one that reads to ~6 m indoors), run it through **Section 3 with the exact same targets, distances and lighting** as a suspect unit, and mark it `reference` in the Section 1 header. Its Diagnostics numbers become the target the others should hit.

What the comparison tells us, reading the two unitsʼ telemetry side by side at the **same target / range / lighting**:

- Reference shows clearly higher **Intensity / Quality** at the same distance → the difference is genuinely in the optics/sensor (a real unit-to-unit or batch difference).
- Both show similar raw **Intensity** but the suspect still reads short → the loss is downstream of the sensor (supply droop / wiring), not the sensor itself — the case the decoupling and regulator fixes target.
- Compare the **Sensor FW hex** (Health screen) on both — a different value points at a different sensor firmware/calibration batch.

Keep conditions identical; an indoor 6 m reading is far easier than anything outdoors, so only compare like with like.

## 9. Free-text observations

For each lighting condition, describe what the readout *did*, in your own words — for example: instant lock, climbs slowly, jumps around, sticks on one number, shows `...`, shows `Held`. This often tells us as much as the numbers.

---

Send the completed tables back as text or a photo of your notes. Thank you.

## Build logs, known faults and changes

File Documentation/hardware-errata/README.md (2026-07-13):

# LiDAR power errata — index

Hardware errata for the DTS6012M LiDAR power supply on the MRF-Pro breakout (connector J7). The work runs in **stages**; filenames carry the stage so the current document is obvious at a glance.

## Which doc do I follow?

**→ [lidar-stage2-ldo-design.md](lidar-stage2-ldo-design.md) — the CURRENT plan.** A dedicated TLV75533 LDO for the LiDAR, fed from VBAT. Then its build guide, [lidar-stage2-ldo-kicad-guide.md](lidar-stage2-ldo-kicad-guide.md).

Everything else is background, supporting detail, or a superseded earlier stage — see the table.

## Documents

| Document | Stage | Status | Purpose |
|---|---|---|---|
| [lidar-stage2-ldo-design.md](lidar-stage2-ldo-design.md) | 2 | **CURRENT** · captured (ERC clean), layout done (DRC clean), fab plotted | The design to build: dedicated LDO, J4 DPDT power switch, net/connector changes, components, verification. |
| [lidar-stage2-ldo-kicad-guide.md](lidar-stage2-ldo-kicad-guide.md) | 2 | **CURRENT** · as-built | KiCad GUI click-by-click to capture the Stage-2 schematic, matching the as-built MRF-Pro-v8. |
| [lidar-stage1-decoupling.md](lidar-stage1-decoupling.md) | 1 | **Closed avenue** (decoupling-only board caused a cold-start regression; superseded by Stage 2). Still valid as **background + hand-solder stopgap** for v1. | Root-cause analysis and the solder-in decoupling fix. |
| [lidar-stage2-breakout-layout.md](lidar-stage2-breakout-layout.md) | 2 | **CURRENT** | Breakout PCB layout for the full LDO (U1, Cin, FB1, R1, the two output rails) — placement, routing, GND stitching, test points. |
| [lidar-field-test.md](lidar-field-test.md) | all | Reference | Tester protocol for comparable before/after range data. Unprefixed because it spans every stage; also linked from the firmware and the user manual. |

Supporting assets: [datasheets/](datasheets/) (TI TLV755P committed; vendor-confidential DTS6012M kept local), [images/](images/) (schematic + diagrams).

## Naming convention

- `lidar-stageN-*.md` — belongs to stage N of the fix. Higher stage number = later, more complete approach; a later stage supersedes earlier ones for the board respin.
- `lidar-field-test.md` — no stage prefix: it is used across all stages.
- The repository git history is the version record; filenames carry only the **stage**, not a revision number.

## Reading order for a newcomer

1. [lidar-stage1-decoupling.md](lidar-stage1-decoupling.md) — what's wrong and why (root cause).
2. [lidar-stage2-ldo-design.md](lidar-stage2-ldo-design.md) — the current fix.
3. [lidar-stage2-ldo-kicad-guide.md](lidar-stage2-ldo-kicad-guide.md) — how to capture it in KiCad.
4. [lidar-field-test.md](lidar-field-test.md) — how to verify range before/after.

## Layout

Breakout PCB layout for the full LDO is in [lidar-stage2-breakout-layout.md](lidar-stage2-breakout-layout.md) (promoted from the old Stage-1 decoupling-only spec). The condensed Layout notes in [lidar-stage2-ldo-design.md](lidar-stage2-ldo-design.md) remain the quick reference; the main-board side has no dedicated layout doc (the J4 DPDT rework is a few connector nets, covered in the design doc).

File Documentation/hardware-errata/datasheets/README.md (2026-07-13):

# Datasheets

Reference datasheets for the LiDAR LDO errata ([../lidar-stage2-ldo-design.md](../lidar-stage2-ldo-design.md)).

| File | Part | In repo? |
|---|---|---|
| `TI-TLV755P-SBVS320D.pdf` | TI TLV75533 LDO (U1). TI doc SBVS320D, rev Sept 2024. Freely redistributable. | Yes |
| `DTS6012M-Docdt22-Rev1.2.pdf` | Paioujidian DTS6012M dToF sensor. **Vendor-confidential — not committed** (see `.gitignore`). | No, local only |

The DTS6012M datasheet is marked "Confidential" by the vendor, so it is kept on the
maintainer's machine and excluded from this public repo. Links to it in the errata
docs resolve locally for whoever holds the file; get it from the module vendor
(派欧机电 / Paioujidian) if you need it. Source online: <https://www.ti.com/lit/ds/symlink/tlv755p.pdf> for the TI part.

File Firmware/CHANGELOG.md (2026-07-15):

# Changelog

All notable firmware changes by released `FWVERSION`, reconstructed from git history.

## 10.7.0 - 2026-07-15

### Repo-wide review: LiDAR recovery fixes, regression guards, delivery-pipeline hardening

Findings from a five-track review (security, correctness, tests, CI/release, docs), all fixed. Verified on device including a test roll.

Firmware fixes:

- **LiDAR recovery no longer resets a healthy sensor while the scene is unmeasurable.** Aiming at open sky, past 18 m, or into hard sun streams valid frames whose candidates are all filtered out; those paths fed no event to the recovery state machine, so the first poll landing between frames escalated to a full reset/enable cycle roughly every 1.5 s and climbed the Health screen `Recoveries:` counter for as long as the drought lasted. Well-formed-but-filtered frames now count as link-healthy; the display behavior (`Inf?`, held readings) is unchanged, and true sensor silence still recovers.
- **LiDAR recovery backoff now actually gates retries.** Every timeout/error event rewrote the next-attempt deadline to "now", so the 250 ms - 2 s exponential backoff never applied; a genuinely failing sensor would have been reset at the 25 ms poll cadence with no settle time. The deadline now arms only on the transition into recovery and survives millis() rollover.
- **Health screen no longer reports downgraded prefs as "Defaults".** After flashing a newer firmware and rolling back, settings load best-effort but the Prefs line fell through to `Defaults`, pointing support triage the wrong way. It now reads `vN newer`.
- **Builds without a light meter no longer latch the meter task at its fast 100 ms cadence.** A single aperture or ISO change looked permanently "pending" because the no-meter path never synced the change markers; it now decays back to the normal 500 ms poll.
- Manual frame cycling now seeds the encoder through the same monotonic-clamped tuning-offset formula the frame estimator uses. The two copies had drifted (cyclefuncs lacked the clamp); divergence was latent within today's format tables but is now structurally impossible.
- Sign-compare hardening in the ISO/lens/format cycle functions: a negative index can no longer wrap past the bounds reset.

Documentation:

- **Setup > Lens > Focus offset (shipped in 10.6.0) is now in the user manual** and the lens-menu mockup.
- Fixed the manual's defaults table (sleep timeout is `1m30s`) and the PANO frame range (`0..20`). Refreshed the firmware README's project tree and library list.

Regression guards (native suite grows 86 to 106 cases):

- All NVS preference keys hoisted into `prefs_keys.h` with tests pinning the 15-char NVS limit (`selected_format` sits exactly at it) and key uniqueness — the v10.3.5 silent-persistence bug class.
- The v10.4.7 "setFrameRate is boot-only" rule is now a tested invariant: the recovery attempt sequence lives in a host-testable unit driven by a call-recording fake that asserts zero frame-rate writes and that the calibration profile is re-applied even when enable fails.
- Per-field mutation tests for the Main and Menu redraw-skip signatures — the v10.6.0 stale-menu bug class; a field dropped from either hash now names itself in a failing test.
- The runtime state-machine suite compiles the production sleep-timeout tables instead of a hand-maintained copy; the loaded-prefs clamp (the only defense against corrupted NVS indexing arrays) is extracted into `prefs_clamp_logic` and driven with corrupted inputs; light-meter EV-compensation direction, EV100 reference points, smoothing-mode clamps, and the iso=0 display cap are pinned; the frame cycle/estimate roundtrip is pinned across every format and the full tuning range; prefs downgrade and legacy-migration branches are pinned.

Delivery pipeline:

- **CI now exists.** Every pull request and push to main runs the native test suite, the ESP32 build, and a version-consistency check across the six release files; the web-updater deploy is gated on the tests passing.
- **update.mrf2.com now self-hosts the flasher.** esp-web-tools 10.2.1 is vendored into the site (previously loaded from the unpkg CDN with no integrity protection, meaning a CDN compromise could have served builders modified flashing code). `scripts/vendor-esp-web-tools.sh` regenerates the bundle for upgrades.
- **Reproducible builds.** PlatformIO and all thirteen libraries are exact-pinned, GitHub Actions are pinned to commit SHAs, and every published build ships a `sha256sums.txt` (also printed in the CI log) so binary tampering is detectable.
- **Tagged releases own their version slot on the updater.** A commit landing on main after a tag without a version bump can no longer silently replace the tagged binary, and unreleased main builds are labeled `unreleased main @ <sha>` in the version picker and the Latest Build row.
- Internal planning notes under `docs/` are no longer published to the public site.

## 10.6.3 - 2026-07-13

### Boot animation: fix bottom-edge text artifacts, tune speed

- Fixed stray version-text glyphs painted along the bottom of the external display at the start of the boot animation. Adafruit_GFX text wrap was left at its default (on), so while the version sat off the right edge the cursor wrapped to the left edge one line lower and drew there. Text wrap is now disabled for the boot screen, so off-screen glyphs are clipped as intended.
- Sped the animation up a little: per-frame delay 80 ms to 65 ms and the settle hold 500 ms to 400 ms (~1.7 s total, down from ~2.1 s). Verify the feel on device.

## 10.6.2 - 2026-07-13

### Slower boot animation

- Slowed the external-display film-advance animation so the film feed is easier to watch: 20 frames at 80 ms plus a 500 ms settle hold (~2.1 s total, up from ~1 s). Timing only — no logic change. Verify the feel on device.

## 10.6.1 - 2026-07-13

### External display boot animation

- Replaced the static `MRF X.Y.Z` boot splash on the external OLED with a film-advance animation: sprocket perforations tick along the top and bottom edges while the version rides in from the right and settles centred, like loading a fresh roll. The per-frame geometry lives in a new host-tested `boot_animation_logic` module; the draw loop stays thin. Boot timing is unchanged (~1 s). Verify boot timing and legibility on device.

## 10.6.0 - 2026-07-13

### Whole-codebase review fixes (safety, persistence, input, rendering, lifecycle)

Findings from a broader firmware review covering everything outside the measurement chain, all fixed:

- **Fixed a boot-loop crash when the status-pixel seesaw board is absent or fails init.** The external UI wrote to the NeoPixel unconditionally; the vendored library leaves its pixel buffer unallocated until `begin()` succeeds, so the first write panicked and the reboot repeated the same failure. All writes are now gated on `hardware.statusPixel`, matching the rest of the per-peripheral degrade-gracefully design.
- **Fixed a dead NVS key.** `prev_encoder_value` (18 chars) exceeded the ESP32 Preferences 15-char key limit, so every write silently failed and every read returned the default. Renamed to `prev_enc_val`; no migration needed since the old key never held real data.
- **Long-press wake no longer drops into the Setup/Health menu.** The long-press handlers lacked the wake guard both short-press handlers already have, so holding a button to wake the camera also acted on the newly-woken mode in the same call.
- **Completing lens calibration now clamps the aperture to the new lens.** Finishing calibration on a newly-selected lens left the previous lens's f-stop active until the user touched an aperture button or rebooted, giving a wrong exposure readout right after the normal calibrate-a-new-lens flow.
- **Setup > Lens > Focus offset and Setup > LiDAR > Distance offset now redraw immediately.** Both settings changed and persisted correctly but the menu's redraw-skip signature didn't include them, so the screen showed the stale number until an unrelated field happened to change.
- **A size-mismatched lens-calibration blob in NVS can no longer silently wipe a lens to "Inf." on every reading.** The load path now requires an exact size match before trusting a stored blob.
- **Legacy preferences migration now commits the schema marker last**, so a power loss mid-migration causes a retry on next boot instead of permanently orphaning the still-present legacy calibration data.
- Sleep fade now starts from the current display brightness instead of always flashing to near-maximum first.
- The light meter now retries a failed sleep/wake I2C command a couple of times before disabling itself, so one transient bus glitch no longer costs the meter for the rest of the session.
- The calibration error message ("Unstable reading" etc.) now clears reliably at its hold-time boundary instead of lingering until an unrelated redraw.
- Per-point calibration capture now cleans up the LiDAR UART afterward, same as the completion step already did.
- The deferred NVS flush now has a 10 s maximum-postponement backstop, so continuous activity (e.g. winding several frames) can no longer delay the write indefinitely.

### Accuracy review fixes (ToF/measurement chain)

Findings from an independent accuracy review of the measurement chain, all fixed:

- **Focus ring no longer renders against a dead LiDAR reading.** After signal loss or idle standby the distance readout showed a placeholder, but the focus-assist ring (and the parallax fallback) kept comparing the lens position against the last accepted distance — indefinitely. The measurement is now invalidated with the display, and only the aiming reticle draws while no live reading exists.
- **Light meter displays the nearest standard shutter speed.** The old buckets floored to the faster speed, a systematic 0 to -1 stop (mean half-stop) underexposure for anyone setting the displayed speed. Selection is now nearest-in-stops, with a half-stop courtesy band beyond each end of the 1/1000..1/2 table. *Verify on a test roll or against a reference meter: the lux calibration scale (1.77) was tuned while the old bias existed. If readings now run consistently hot, re-derive the scale — don't revert the rounding.*
- **Waking from sleep or standby no longer trips a spurious LiDAR recovery.** The first post-wake poll inevitably has no frame yet; with the pre-sleep timestamp still in the recovery state, the timeout fired instantly, running a reset+enable back-to-back with the wake enable (the v10.4.7 hazard) and inflating the Health screen's Recoveries counter on every wake. Recovery timing now restarts on every sensor enable.
- **Post-wake light readings start fresh.** The lux smoothing EMA survived sleep, so waking in different light blended in up to ~80% pre-sleep level for the first ~1.5 s. The EMA now resets when the meter wakes.
- **Switching lenses recomputes the focus distance immediately** instead of keeping the previous lens's table mapping until the focus ring moved.
- **The near-range LiDAR correction survives offset-pref changes.** The 130 cm -> 100 cm anchor was measured at the default 400 mm geometry offset; changing the offset pref shifted the correction's input frame and silently invalidated the anchor. The correction now evaluates in the default-offset frame and re-adds the delta.
- **Rounding instead of truncation** in the LiDAR mm->cm conversion (0-9 mm short bias on every reading), the lens-table interpolation (up to 1 cm short), and the battery percentage (which could also print "-0%" at power-on).
- **Boot no longer shows a bogus 1.0 m lens distance.** The lens smoothing window was zero-filled at boot and the spike filter latched the warm-up artefact for ~15 polls; the window is now primed with the first real ADC read.
- **Far focus marks only snap when the distance is actually close.** The fixed 3-count far deadzone spans metres on sparse tables (a reading interpolating to 8.5 m displayed "10.0m"); snapping now also requires the interpolated distance within 8% of the mark.
- **Dropouts flag the held reading.** During the 1 s grace window after signal loss the previous distance now shows as "Held:" instead of presenting as live, and the ~2 s calibration-complete celebration no longer leaves the LiDAR UART overflowed. The diagnostics fps count is normalised by the real window length.

### LiDAR driver update (DTS6012M_UART 3.0.0)

Bumped the sensor library dependency to `^3.0.0`. Public signatures, error codes, and the measurement/statistics layouts are unchanged, so the firmware builds and runs against it without code changes; two `DTSConfig` fields are appended. Notable behaviour changes and how the firmware handles them:

- **Quality grading and the median filter now exclude out-of-range readings**, so the sensor's valid-distance limit finally has teeth. The firmware previously set that limit from the frameline parallax cap (`DISTANCE_MAX`, 18 m); with the geometry offset added that clipped genuine far returns ~2 m short of the sensor's rated range. The library's `maxValidDistance_mm` is now set from a dedicated `LIDAR_LIBRARY_MAX_VALID_DISTANCE_MM` (20 m, the sensor's rating), decoupled from both the parallax cap and the 18 m display-to-"Inf." policy (`LIDAR_DISPLAY_INF_THRESHOLD_CM`).
- **The opt-in ambient-light gate (`maxSunlightBase`) is left disabled, deliberately.** The outdoor-range investigation established that `sunlightBase` reads flat outdoors (it measures ambient at the aperture, not the solar reflection off the target that causes the range cliff), so gating on it would reject valid frames without helping. Documented in `makeLidarConfig()` so it is not naively enabled later.
- **The median filter now drops POOR/under-threshold samples too.** When too few quality-valid samples remain it returns the invalid sentinel; the firmware already falls back to the raw primary distance in that case, so far/marginal readings still display, just unsmoothed.
- Carries the accuracy fixes first shipped in 2.8.0: raw distance 0 stays invalid instead of becoming a reading at the offset distance; AUTO CRC byte-order detection survives the host recovery path; and the median history clears on reset/standby so the first post-wake reading is not the previous subject's distance.
- Plus the 3.0.0 robustness work: a timeout no longer wipes a frame reassembling across `update()` calls (no permanent-TIMEOUT livelock), stale data is invalidated after a comms timeout, `enableSensor()` refreshes the library's own timeout clock, and `errorCount`/`getConsecutiveErrors()` now count timeouts.

### LiDAR driver update (DTS6012M_UART 2.7.0)

- Bumped the sensor library to `^2.7.0`, which fixes the frame-drain bug found during the range investigation (one `update()` now keeps the freshest queued frame instead of the oldest) and makes one-shot commands report real errors instead of false success.
- **Adapted to the new `update()` contract.** The library now returns `NO_NEW_DATA` (not `TIMEOUT`) whenever no complete frame arrived on a given poll — the normal case every time the loop runs faster than the frame rate. The recovery layer now treats `NO_NEW_DATA` as a benign, time-based event, so a healthy sensor no longer risks tripping spurious recovery. A genuine comms stall still surfaces as `TIMEOUT` after the no-data timeout. Added regression tests for the mapping and for the no-spurious-recovery guarantee.

### LiDAR Diagnostics screen

- The frame-rate line now shows a **measured** frames-per-second count (accepted frames over a rolling one-second window) instead of the sensor's boot-time self-report. The self-report reads 0 on current hardware because the DTS6012M does not answer the frame-rate query, so the old `act:` value was always misleading. The measured count is what confirmed, during the outdoor-range field investigation, that a lower frame rate is genuinely delivered yet does not extend range.

### Focus distance and LiDAR accuracy fixes

- **Lens focus readout fixed for the default 65mm lens.** The focus-distance table stored its sensor readings in descending order while the interpolation expects ascending, so between the calibrated marks the readout snapped to 1m (or `Inf.` at the near stop) instead of interpolating. The default table is now stored ascending, matching the convention the rest of the pipeline assumes, and a regression test guards that every calibrated lens table ascends. Verify against the marked distances on a calibrated 65mm lens.
- **Near-range correction no longer over-shrinks close subjects.** The single-reference power law pulled sub-metre readings far too low (a raw 65cm read out as 14cm and dropped below the display floor). The correction is now bounded so it can never remove more than 40% of the raw distance — an interim guard until the measured near-range table lands.
- **Confident far returns get a wide but finite trust margin.** A GOOD/EXCELLENT return past a near focus prior is still trusted, but only out to three times the prior. The sensor grades quality after normalising for distance, so a beam miss onto a bright far background can still read GOOD; a gross overshoot is now rejected regardless of grade.
- **Dual-peak fusion keeps the stronger reading's confidence.** When the primary and secondary returns agree, the fused confidence now takes the higher of the two (plus the agreement bonus) rather than the average, so a weak secondary can no longer demote a confident primary.
- **Focus distance interpolates in reciprocal-distance space.** Helicoid extension (what the linear sensor measures) tracks 1/distance, so the old linear-in-distance interpolation over-read across the sparse far marks. The between-mark readout is now physically correct and the far-mark stepping is softer.

### Lens calibration and focus robustness

- **Calibration requires readings that rise with distance.** A backwards-wired focus sensor captured a descending sequence the estimator reads inverted (the same class as the 65mm default bug, but reachable through the UI). Calibration now rejects it with a clear "readings decreasing — sensor wired backward?" prompt instead of silently storing an inverted table.
- **Uncalibrated lenses show `--` instead of `Inf.`** Selecting a lens with no calibration data previously displayed a believable `Lens: Inf.`; it now shows a neutral placeholder.
- **New Setup > Lens > Focus offset.** A per-camera focus fine-tune (ADC counts, applied in Main mode only) aligns the readout without a full recalibration and absorbs any Main-vs-calibration bias. Calibration still captures clean, so the stored table is unchanged.

### LiDAR recovery and responsiveness

- **The distance offset survives a partial recovery.** A recovery that reset the sensor but failed to re-enable it left the library distance offset zeroed — a silent ~40 cm short bias until the next fully successful recovery. The calibration profile (scale + offset) is now re-applied unconditionally after every reset.
- **Faster lens ADC sampling.** The lens-position ADC ran at 128 SPS, so a 3-sample read blocked the cooperative loop for ~24 ms and could delay buttons and the encoder. At 920 SPS the same read blocks ~3 ms; the averaging and spike filters absorb the slightly wider per-sample noise.

## 10.5.0 - 2026-06-21

Long-range LiDAR work: trust confident far returns, show the sensor's full rated range, and add a diagnostics screen so field testers can read back exactly what the sensor reports. Pairs with the v2 (MRF-Pro-v8) breakout's dedicated LiDAR regulator.

### LiDAR long-range behaviour

- **Confident far readings are no longer suppressed.** A GOOD/EXCELLENT return past the lens-focus prior is the sensor locking a real far subject, not a parallax beam miss, so the plausibility gate now trusts it. The allowed overshoot scales with the prior instead of a flat 2m, because beam-miss error grows with distance.
- **Display ceiling raised to the sensor's rated 18m** (was 10.5m), so genuine far subjects read out instead of collapsing to infinity early.

### LiDAR Diagnostics screen

- New **Setup > LiDAR > Diagnostics** screen showing live raw distance, intensity, sunlight base, SNR, quality, held state, requested vs actual frame rate, and error/recovery counts. It lets a tester read back exactly what the sensor returns while aiming at a target.
- The screen shows the **telemetry frame age** next to the frame rate (milliseconds when fresh, seconds when stale, `>99s` cap, `--` before the first frame) so stale values can't be mistaken for live ones.
- The sensor's actual frame rate is read back at boot so a future frame-rate experiment can confirm what was latched.

### Signal-loss readout

- A far-range dropout now shows **`Inf?`** instead of `Inf.`, so a lost signal above 3m is marked as a guess rather than passing for a real 18m measurement. The placeholder persists across a continuing dropout (e.g. aimed at the sky) instead of flickering for a single frame. Standby (`Zzz`) and near dropouts still resolve to `...` so wake starts clean.

### Boot screen

- The boot version text on the external display now shrinks to fit the screen width instead of wrapping, so three-part versions render cleanly.

### Tests

- Added coverage for the gate (confident far reads not suppressed, overshoot scales with prior), the display ceiling, the `Inf?` placeholder helper, and the telemetry-age formatter including `millis()` wrap. Test count: 53 → 66.

## 10.4.10 - 2026-05-31

### LiDAR plausibility gate

Field reports of the distance readout appearing to "cap" at short range traced to the lens-prior plausibility gate (added in 10.4.6) holding the previous value too aggressively when the lens is focused close. This release retunes it and makes the hold visible.

- **Faster release on a deliberate re-aim.** The gate no longer waits a blind 8 frames before accepting a far reading. It now releases as soon as two consecutive rejected readings agree (a real far subject the user has aimed at), and keeps an absolute 3-frame cap so a noisy beam-miss can never pin a stale value indefinitely. The release decision is a new pure, unit-tested helper (`updatePlausibilityHold`).
- **Wider focus coverage.** The gate now applies out to 3m of lens focus (was 2m), so the parallax beam-miss guard also covers portrait and group distances.
- **"Held:" indicator.** When the gate is showing the previous value instead of a live measurement, the main-screen label changes from `Dist:` to `Held:`, so a held reading reads as intentionally frozen rather than broken.

Verify in the field: with the lens focused near, panning to a farther subject should update within a frame or two, and the label should briefly read `Held:` while it does.

### Tests

- Added coverage for the stable-vs-noisy release logic and the reset path; updated the gate boundary tests for the new 3m focus threshold. Test count: 50 → 53.

## 10.4.9 - 2026-05-16

Internal refactoring release plus a setup-menu reorganisation. The menu reorg is the one user-visible change; everything else is structural. Pending field testing.

### Setup menu reorganisation

- The setup menu hierarchy has been restructured around user mental categories. Persistence is untouched — your settings come back where you left them, just in their new home.
  - **Reset frame counter** is now in **Setup > Film** (it's a film action, not navigation).
  - **Frame 1 offset** and **Frame spacing** moved to **Setup > Film > Frame counter tuning** (one-time calibration knobs, demoted from the Film top level).
  - **LiDAR distance offset** and **LiDAR idle timeout** moved into a new **Setup > LiDAR** submenu (they were miscategorised under UI Settings).
  - **UI Settings** is renamed **Display** and trimmed: it now holds brightness, horizon line on/off, sleep timeout, horizon-trim sub-page, and reticle adjust.
  - The three horizon-trim rows moved to **Setup > Display > Horizon trim** so they group cleanly.

### Subtle UX

- **Portrait/landscape hysteresis is now self-healing after a long config detour.** When the user spends time in a config menu and rotates the device, the level renderer's cached `portraitMode` could stay stuck at the old orientation until the user rotated past the hysteresis bands again. The renderer now resets the cache whenever it has been idle for >1s.
- **`toggleLidar()` now flips `lidarEnabled` before re-applying the calibration profile**, matching the order already used by the boot and retry paths. Functionally inert today; removes an ordering inconsistency.

### Internals (no user-visible behaviour change)

- **New host-testable logic modules** extracted out of hardware-coupled files: `lens_spike_logic`, `frameline_layout_logic`, `ui_signature_logic`, `formatting_logic`, `lidar_runtime_state` bundling. Each new module ships with unit tests.
- **LiDAR pipeline cleanups** in `lidar_logic.cpp`: distance-tier lookups, DataQuality profile table, shared candidate-validation gate, shared fuse-or-pick-best selection.
- **`handleRightButtonShortPress` split** into per-mode handlers; the dispatcher is now a clean switch on `ui_mode`.
- **Shared U8G2 text-defaults helper** consolidates four near-identical OLED-prep sequences in interface.cpp.
- **Display-layout pixel coordinates** moved out of `mrfconstants.h` into a dedicated `interface_layout_constants.h` so layout tweaks don't force a full-tree rebuild.
- **`globals.h` regrouped by domain** (Lightmeter / Lens / LiDAR / UI / Calibration / Frame counter / Sleep / Health). Module-private caches (lens moving-average buffer, `prev_distance`, `prev_lens_sensor_reading`) demoted to file-scope statics in the only module that touches them.
- **`helpers.cpp` reorganized**: lens moving-average buffer now lives next to `calcMovingAvg`; `cmToReadable` moved into its own pure module.
- **Sleep-wake baseline ownership centralised** in `finaliseSleepServices`; removed unreachable lazy-init paths in the wake-poll functions.

### Test coverage added

- Regression guards for the v10.4.7 LiDAR-recovery incident class (state machine resilience under sustained failure), the v10.4.6 lightmeter scale-split (`K * LIGHTMETER_LUX_CAL_SCALE` product + known-scene shutter band), and the v10.4.6 6x9/9x3 sensor-table alignment.
- New tests for hash primitives, lens spike filter, frameline scaling, cm-to-readable formatter, secondary-quality INVALID remapping, and the misnamed split lidar test.
- `DTSMeasurement` and `findLensById` builders consolidate test setup boilerplate.

## 10.4.8 - 2026-05-16

### Bug fixes

- **3x6 frame spacing (every-other-frame exposure on 120 film, issue #21)**: rewrite the 3x6 `sensor[]` table to use 120-film geometry. The original 3x6 row in `d4f73cf` was a verbatim copy of PANO with one entry appended — same per-frame encoder deltas as a 65mm-wide panoramic frame on 35mm film, applied to a 30mm-wide frame on 120 — so users were advancing roughly twice as far per frame as the mask allowed, leaving every-other-frame slot blank on the developed roll. New deltas are derived from a per-frame counts/mm regression across the four calibrated 120 formats (6x4.5, 6x6, 6x7, 6x9), evaluated at 30mm frame width + 5mm gap. Leading offset matches 6x7. Verify with a calibration roll; fine-tune via Setup > Frame counter tuning if needed.
- Strengthen `test_format_3x6_supports_21_frames` to assert 120-film geometry (leading delta ≥120, end sentinel 550) so future edits can't regress to PANO-shaped values.

## 10.4.7 - 2026-05-15

### Bug fixes

- **LiDAR recovery loop on sensitive DTS6012M units**: revert the v10.4.6 change that re-sent `setFrameRate(50)` from the recovery path. On some sensors, issuing `setFrameRate` immediately after `enableSensor()` (with no settle delay) leaves the unit in a state where the next `update()` times out, which retriggers recovery — a self-perpetuating loop that pinned the Health screen at `err:6` (UART timeout) with `Recoveries:` climbing indefinitely. Frame rate is once again set inline at boot only; the sensor retains it across enable/disable cycles. The distance scale/offset re-application in `applyLidarCalibrationProfile()` is preserved.

## 10.4.6 - 2026-05-02

### New menu items

- Add **LiDAR offset** to Setup > UI Settings (`0`–`800mm` in `10mm` steps, default `400mm`). Tunes the LiDAR reading to compensate for the sensor-to-lens-plane physical offset. Persisted to NVS; takes effect immediately so the live distance readout reflects the change without a reboot.

### UI improvements

- **Focus reticle adjustment** screen now shows the current X/Y offsets numerically with a `>` marker on the active axis, plus a fixed reference crosshair at the optical centre so the reticle dot's offset is visually unambiguous.
- **High-sunlight indicator** on the main UI: a small sun glyph appears next to the Dist readout when ambient IR (sensor `sunlightBase`) crosses a hysteresis threshold. Distinguishes "LiDAR struggling because bright" from "firmware broken." Initial thresholds need field tuning from real readings.

### Bug fixes

- **6x9 and 9x3 frame spacing**: reduce interframe advance by 1–2 encoder ticks per gap (cumulative 9 ticks at frame 8, recovering ~21mm = approximately 1/4 frame). Both formats shared the same out-of-tolerance sensor values.
- **Light meter overexposure of approximately 1.5 stops**: split the meter calibration constant `K` (now ISO-standard 12.5) from a new BH1750 mounting compensation `LIGHTMETER_LUX_CAL_SCALE` (1.77) that scales raw sensor lux up to actual scene illuminance.

### LiDAR pipeline robustness

- **Lens-prior plausibility gate**: when the lens is focused at or below 2m, reject LiDAR readings that overshoot the lens prior by more than 200cm. Catches the parallax beam-miss failure mode (LiDAR beam goes past the framed subject and finds distant background). Holds the previous valid reading instead. Falls through after 8 consecutive rejections so the user can deliberately re-focus past the previous target without being permanently stuck.
- **Subject-stable confidence boost**: when 5+ consecutive LiDAR readings stay within 5cm of each other, add +10 to the candidate's confidence (clamped at 95). Helps the temporal blend trust the locked-on value over occasional noise. Streak resets on dropout, on a jump beyond delta, or on plausibility-gate rejection.
- **Near-range temporal blend**: gentle 12% previous / 88% current blend when high-confidence readings are at or below 2m, reducing single-frame noise without introducing lag.
- Relax near-range SNR target from 300 to 180 permille so close subjects shot horizontally in full sun (open sky floods the photodetector with ambient IR) are no longer dropped.
- Defensively re-apply LiDAR frame rate after sensor recovery (previously only set at boot).
- Remove unused residual-correction lookup table and the unreachable double-correction wrapper around it. The power-law correction below 1.5m remains.

### Tests

- Test count: 31 → 38. Added pure-helper coverage for `isLidarReadingImplausible`, `applyStableConfidenceBoost`, `updateSunlightWarnState`.
- Update a stale assertion left over from the v10.4.5 near-distance precision feature (`150cm` now correctly asserts as `"1.50m"`).

## 10.4.5 - 2026-04-16

- Distance display below 2m now shows two decimal places (e.g. `1.85m`) instead of one.
- Add display brightness control to Setup > UI Settings:
  - **Brightness mode**: Auto (scales with ambient light from BH1750) or Manual.
  - **Brightness top** (Auto): sets the maximum brightness ceiling from 50% to 100% in 10% steps.
  - **Brightness level** (Manual): sets a fixed brightness from 5% to 100% in 5% steps.
  - Both settings persisted to NVS and survive reboots.
- Add **Horizon line** toggle to Setup > UI Settings (On/Off), persisted to NVS.

## 10.4.0 - 2026-04-15

- Add visual focus reticle offset adjustment (Setup > UI Settings > Focus reticle).
  - Step 1: L/R moves reticle horizontally; long press either button advances to step 2.
  - Step 2: L/R moves reticle vertically; long press either button saves and exits.
  - Offsets persisted to NVS and survive reboots. Range: -20 to +20 px.
- Reticle offset X/Y converted from compile-time constants to user-configurable settings.
- Fix right-button long press firing repeatedly on every loop iteration; it now fires exactly once per hold across all modes.

## 10.3.5 - 2026-04-02

- Reduce focus ring granularity from 1cm to 5cm steps so the ring locks when lidar and lens distances visually match, without snapping too early.
- Fix LiDAR idle timeout setting not persisting across reboots (NVS key exceeded ESP32 15-char limit).
- Change default sleep timeout to 1m30s and default LiDAR idle timeout to 1m.

## 10.3.4 - 2026-03-30

- Retune LiDAR accuracy tiers to match subject distance importance:
  - ≤2m (was ≤3m): super accurate — intensity gate 40, SNR target 300‰, full prior influence.
  - 2–5m (was 3–7m): less accurate — intensity gate 10, SNR target 150‰, 60% prior influence.
  - 5–7m (new tier): even less accurate — intensity gate 3, SNR target 40‰, 35% prior influence.
  - 8m+ (was 7–12m): just get a value — intensity gate 1, SNR target 10‰, 20% prior influence.

## 10.3.3 - 2026-03-30

- Fix buffer overflow in lightmeter when exposure time reaches very large second values (uncapped `dtostrf` into a 10-byte buffer).
- Lightmeter exposure display now shows seconds in 0.5s increments (1, 1.5, 2, 2.5 …) and switches to minutes+seconds format (e.g. 1m30s) at one minute.
- Cap lightmeter exposure display at 25 minutes.

## 10.3.2 - 2026-03-20

- Updated DTS6012M_UART library to v2.5.3 (from v2.2.1). v2.5.2–2.5.3 fix stale circular buffer and `_lastValidFrameTime` not updating on `sendOneShot` timeout — both caused `getFirmwareVersion`/`setFrameRate` to starve the measurement stream. All `setFrameRate`/`getFirmwareVersion` calls now use the library API directly.
- Display sensor firmware version in system health screen.
- Use library `newDataAvailable()` flag and `getFilteredDistance()` median filter for jitter reduction.
- Set LiDAR frame rate to 50 fps for improved far-range integration time.
- Skip secondary candidate when no dual-peak target detected.
- Reset `prev_distance` on display clear to prevent stale temporal penalty.
- Show "Inf." instead of "..." when signal lost above 3 m.

## 10.3.1 - 2026-03-18

- LiDAR range and library update:
  - Updated DTS6012M_UART library to v2.2.1. Library now exposes IIC register access (`writeIICRegister`/`readIICRegister`), diagnostic histogram and SPAD heatmap streams, CRC AUTO mode with configurable auto-switch threshold, and `getTemperatureCode()`. `assessDataQuality()` scales the intensity threshold by inverse-square-law distance for fairer far-range quality assessment. Test stub updated to match v2.2.1 struct layout and enum values.
  - Retuned LiDAR fusion pipeline into three accuracy tiers: strict ≤3m (high accuracy), relaxed 4–7m, and very lax 8m+ (accept almost any return signal). Range boundaries widened from 2.2/5/10m to 3/7/12m.
  - Far-range intensity gates significantly lowered: mid 10→5, far 3→1, max-range unchanged at 1.
  - SNR targets relaxed at range: mid 200→100‰, far 120→25‰, max-range 80→10‰. Hard-reject floor 15→8‰.
  - Gentler SNR penalty: divisor 25→30, max 10→8 (fallback 5→3).
  - Fallback path: min intensity 2→1, base confidence 20→25, ceiling 40→50.
  - Temporal penalty reduced: divisor 20→25, max 14→10 — less suppression of noisy far-range frame-to-frame jumps.
  - Reset `prev_distance` to 0 when the display clears so the next valid reading is not penalised by a stale temporal jump.
  - Low-confidence per-frame step limit raised from 60→300cm for faster recovery after dropout.
  - Low-confidence blend weights widened 0.12–0.28→0.20–0.35.
- LiDAR UX improvements:
  - Signal loss at far range (last reading >3m) now shows "Inf." instead of "..." — tells the photographer the subject is beyond range, not that the sensor has failed.
  - Hold timeout increased from 750ms to 1000ms to bridge intermittent dropouts at the range boundary.
- Removed diagnostic serial logging from LiDAR pipeline.

## 10.3.0 - 2026-03-15

- Usability improvements:
  - Boot progress: main display now shows an "Initialising..." progress bar with a label naming the peripheral group being started (e.g. "Sensors", "Displays"), instead of staying blank for ~2 seconds.
  - Calibration UX: the calibration screen now shows a progress bar, a point counter (e.g. "3/7"), revised help text explaining the focus-ring workflow, and clearer error messages ("Hold lens still and retry" / "Increase focus distance") held on screen for a minimum of 2 seconds. A green LED pulse confirms each successful capture. On completion, a full-screen "Calibration complete!" message is shown with a triple green LED pulse, held for 1.5 seconds.
  - Calibration inlier check: sample stability validation now uses median-based spread instead of min/max range, making it more tolerant of occasional outlier readings.
  - Menu breadcrumbs: submenu headers now show the navigation path (e.g. "Setup > Film", "Setup > Lens", "Lens > Calibrate").
  - Expanded horizon trim labels: "Horizon L" / "Horizon P+" / "Horizon P-" are now "Horizon Landscape" / "Horizon Portrait+" / "Horizon Portrait-".
  - Calibration text wrap: moved "(R) to Cancel" to its own line on the calibration capture screen to prevent text overflowing the 128 px display width.
  - Calibration progress bar: inset to align with text edges instead of spanning full screen width.
  - Focus ring: increased max radius (30→40 px) and max thickness (3→5 px) for more prominent out-of-focus indication. Added EMA smoothing on the radius to reduce twitchiness near focus.
  - Calibration LED: green capture pulse now restores the previous LED colour instead of turning it off.
  - Sleep fade: the main OLED fades to black over ~200 ms using a non-blocking state machine before powering off, instead of blanking abruptly. Brightness is restored on wake.
  - Setup value previews: Film, Lens, and Meter entries on the root Setup menu show their active value inline (e.g. "Film: 6x7 >", "Lens: 65/6.3 >", "Meter: ISO400 >").
  - Health screen: added **Retry LiDAR** option (R button) when LiDAR failed to initialise, allowing re-initialisation without a power cycle.
  - Health screen: added **Factory Reset** option (long-press R) with confirmation screen. Clears all NVS preferences and reboots to defaults.
- LiDAR outdoor reliability:
  - Lowered near-range minimum intensity gate from 60 to 40 and SNR hard-reject floor from 40‰ to 25‰, reducing false `...` dropouts in bright sunlight.
  - Lowered SNR confidence penalty targets for near (420→300‰) and mid (280→200‰) ranges so readings lose less confidence under high ambient light.
  - Extended fallback candidate path to all ranges (previously blocked ≤220 cm), allowing low-confidence tracking at close distances when primary filtering rejects.
  - Increased no-data display timeout from 500 ms to 750 ms so brief dropouts hold the last valid reading instead of flashing `...`.
- Bug fixes (from 10.2.1):
  - Fixed calibration median index off-by-one: used lower median `(sample_count - 1) / 2` instead of upper median `sample_count / 2` for even sample counts.
  - Replaced `ev_readout == ev_readout` NaN self-comparison with explicit `isnan()` for clarity and robustness against `-ffast-math`.
  - Aperture index is now clamped after every lens switch, preventing out-of-bounds access when switching from a lens with more aperture stops to one with fewer.
- NVS flash wear reduction (from 10.2.1):
  - All `savePrefs()` calls in `cyclefuncs.cpp` now pass `PREFS_DIRTY_SETTINGS` instead of defaulting to `PREFS_DIRTY_ALL`.
- Code quality and maintainability:
  - Consolidated three cyclic value helpers into a single `cycleValueWrapping()` template.
  - Unified LiDAR display clearing into a single parameterised function.
  - Extracted `LENS_APERTURE_COUNT` constant and removed `sizeof` duplicates.
  - Extracted `markPrefsClean()` helper and simplified `getFocusRadius()`.
  - Removed redundant aperture bounds check and duplicate colour reset function.
  - Removed dead `prev_bat_per` and `prev_lux` globals.
  - Added compile-time `static_assert` validation for menu step constants.
  - Fixed external UI SVG progress bar clipping and frame counter alignment.
- Release metadata/docs:
  - Bumped `FWVERSION` to `10.3.0`.
  - Rewrote lens calibration section in user manual to explain focus-ring/sensor relationship.
  - Updated firmware README, user manual, CHANGELOG, and UI SVGs for all changes.

## 10.2.0 - 2026-02-28

- Power and runtime efficiency:
  - Replaced busy-polling in sleep mode with `esp_light_sleep_start()`, cutting CPU current between poll cycles from ~20–30 mA to ~0.8 mA.
  - Button GPIOs (`BUTTON_LEFT_PIN`, `BUTTON_RIGHT_PIN`) now configured as GPIO hardware wakeup sources during device sleep for immediate response.
  - Encoder and lens ADC polls unified on a 100 ms timer wakeup during device sleep (encoder previously polled at 50 ms).
  - MPU6050 now placed into hardware sleep on device sleep entry and woken on exit.
  - CPU frequency scaled down to 80 MHz during device sleep and restored to 240 MHz on wake.
  - Film counter idle polling interval increased 25 ms → 75 ms to reduce unnecessary ADC reads.
  - Battery gauge polling interval increased 1.5 s → 5 s (battery state changes slowly).
  - UI redraw tick slowed from ~30 Hz (33 ms) to 20 Hz (50 ms).
- Sleep indicator:
  - External OLED sleep indicator replaced: `ZzzZzzZZz...` text replaced with a minimal circle-face graphic plus `Zzz` label.
- Bug fixes (found during hardware testing):
  - Button wakeup from light sleep now fires correctly on both press and release. Button-release Bounce2 `rose()` events were previously missed because `checkButtons()` was only called on GPIO wakeup causes; the button release arrives on the subsequent timer wakeup, so `checkButtons()` now runs unconditionally on every wakeup cycle.
  - Battery percentage now appears immediately at boot instead of after the first 5-second battery poll cycle.
  - I2C bus speed is now restored to 400 kHz after each display write; the SH1107 display constructor previously left Wire at 1 MHz, which is above the MAX17048 rated maximum.
  - Battery gauge (`MAX17048`) now reliably reports as ready when sharing I2C address `0x36` with the Seesaw peripheral. The library's soft-reset sequence deliberately expects a NACK from the MAX17048 (which resets before acknowledging), but the Seesaw at the same address ACKed the write, causing `begin()` to report failure despite the gauge being operational. A fallback SOC plausibility check now sets `batteryGaugeReady` correctly.
- Testing:
  - Extended runtime state machine test suite: boundary tests for all five sleep timeout modes, `MODE_OFF` coverage, and constant-value guards for `LOOP_SLEEP_LIGHT_SLEEP_US`, `SLEEP_WAKE_ENCODER_DELTA`, and `SLEEP_WAKE_LENS_DELTA`.
- Code quality and maintainability:
  - Lifted hidden function-local statics in `setfuncs.cpp` into named namespace-scope structs (`LensSpikeFilterState`, `LensSnapState`, `LightMeterSmoothingState`, `LidarRecoveryState`) for explicit ownership and easier testing.
  - Split the `checkButtons()` monolith into three focused handlers: `handleLeftButtonShortPress()`, `handleRightButtonLongPress()`, `handleRightButtonShortPress()`.
  - Decomposed `drawLevelIndicator()` into `readAccelerometer()`, `updatePortraitMode()`, `computeLevelAngles()`, and `renderLevelLine()`.
  - Named magic OLED command bytes as `OLED_CMD_DISPLAY_OFF`/`OLED_CMD_DISPLAY_ON` constants.
  - Extracted `advanceMenuStep()` helper to eliminate five identical menu step-cycling blocks.
- Release metadata/docs:
  - Bumped `FWVERSION` to `10.2.0`.
  - Updated firmware README, user manual, and camera UI SVG snapshots.

## 10.1.2 - 2026-02-26
- Lens calibration and distance-scale updates:
  - Added per-lens calibration point-count support (up to `10` markers per lens profile).
  - Updated `150/5.6` marker set to `2, 2.5, 3, 5, 10`.
  - Updated `250/5.0` marker set to `2.5, 4, 5, 7, 8, 10, 15, 20, 30, 50`.
  - Added `250/8.0` profile with marker set `3.5, 4, 5, 7, 10, 15, 20, 30, 50`.
  - Calibration UI now reads target distances from the selected lens profile.
  - Lens snap/interpolation now uses active profile markers and ignores trailing unused slots.
  - Preferences loading now tolerates older saved calibration array sizes during schema evolution.
- Power and runtime efficiency:
  - Added awake-idle LiDAR standby that disables LiDAR after inactivity in Main mode and wakes immediately on activity.
  - LiDAR idle timeout is now user-configurable in `UI Settings` with the same options as sleep timeout (`Off`, `15s`, `30sec`, `1m`, `1m30s`, `2m`) and defaults to `1m`.
  - Main UI now shows `Dist: Zzz` while LiDAR is in idle standby.
  - Added state-aware UI redraw caching so displays redraw only when state changes (with bounded periodic refresh for Main/Health screens).
  - Added adaptive polling intervals for film counter, lens sensor, and light meter (fast when active, slower when stable).
- Code quality and maintainability:
  - Refactored loop orchestration from `main.cpp` into `loop_runtime.cpp` to isolate scheduling and sleep/awake task routing.
  - Decomposed `interface.cpp` into reusable rendering helpers for main/config/external displays.
- Release metadata/docs:
  - Consolidated release metadata under `10.1.2`.
  - Updated firmware README, user manual, and camera UI SVG snapshots.

## 10.1.1 - 2026-02-25
- Viewfinder/UI tuning:
  - Removed the boxed portrait-mode `P` indicator from the main display.
  - Increased `UI Settings` horizon trim granularity from `5deg` to `2.5deg` steps (`-30deg..+30deg`).
  - Added backward-compatible migration for older stored trim keys to the new `0.1deg` internal format.
- Release metadata/docs:
  - Bumped `FWVERSION` to `10.1.1`.
  - Updated firmware README, user manual, and camera UI SVG snapshots.

## 10.1.0 - 2026-02-24
- Film format and frame-counter updates:
  - Added `3x6` format (`30 x 56`) with `0..21` frame range.
  - Kept format ordering consistent in firmware/docs (`PANO`, `3x6`, `6x4.5`, ...).
  - Increased format-point capacity to support larger frame maps.
- Viewfinder level updates:
  - Added adaptive horizon behavior that auto-switches between landscape and portrait handling.
  - Added portrait-mode indicator (`P`) on the main display with high-contrast boxed rendering.
  - Added configurable horizon trim offsets in `UI Settings` for `Horizon L`, `Horizon P+`, and `Horizon P-` (`-30..+30`, `5` degree steps, defaults `0`).
  - Moved sleep timeout setting into `UI Settings`.
  - Tuned portrait roll/pitch behavior for more accurate in-hand leveling.
- Robustness and cleanup:
  - Removed redundant logic paths in activity/LiDAR/encoder handling.
  - Tightened bounds handling for frame/smoothing index usage.
  - Reduced variable shadowing and stale fallback checks.
- Release metadata/docs:
  - Bumped `FWVERSION` and updated README/manual/UI version snapshots.

## 10.0.3 - 2026-02-22
- LiDAR ambient-light handling:
  - Added sunlight-aware SNR scoring (`intensity` relative to `sunlightBase`) for primary/secondary/fallback candidates.
  - Low-SNR frames now reduce confidence first, with hard rejects reserved for very weak signals under strong ambient light.
- Setup menu ordering:
  - Moved `Reset frame counter` to sit directly above `Sleep timeout` in the root Setup menu.
- Docs/UI snapshots:
  - Updated firmware README, user manual, and camera setup/health UI SVG snapshots for 10.0.3.

## 10.0.2 - 2026-02-22
- LiDAR outdoor range tuning:
  - Lowered library minimum intensity threshold (`200` -> `80`) to preserve marginal long-range returns in bright light.
  - Relaxed mid/far fusion intensity gates (`14/8/4` -> `10/6/3`) to reduce long-range dropouts.
  - Reduced temporal penalty cap (`18` -> `14`) so far-distance updates recover faster after noisy frames.

## 10.0.1 - 2026-02-22
- Film submenu updates:
  - Added configurable `Current frame` setting in Film menu.
  - `Current frame` range is now constrained by selected format maximum (for example, `6x6: 0..12`, `6x7: 0..10`).
  - Manual frame changes now re-sync encoder position and frame-progress state.

## 10.0.0 - 2026-02-22
- Settings UI updates:
  - Split setup into focused submenus for Lens and Light Meter settings.
  - Added top-level configurable sleep timeout setting: `Off`, `15s`, `30sec`, `1m`, `1m30s`, `2m` (default `1m`).
  - Unified vertical padding under setup/menu headers for consistent layout.
- Runtime behavior:
  - Sleep timeout now uses the persisted menu setting instead of a fixed constant.
  - LiDAR recovery flow no longer escalates recovery attempts on filtered/noisy (non-error) frames.
  - LiDAR distance readout now shows values below `1m` in `cm`.
- Preferences:
  - Added persisted key for sleep timeout mode (`sleep_to_mode`), with load-time clamping.
- Release metadata/docs:
  - Updated firmware README, user manual, and UI SVG snapshots for release consistency.

## 9.6.0 - 2026-02-17
- Web updater improvements:
  - Added browser-based GitHub Pages firmware updater.
  - Improved updater UX (erase handling + reboot guidance).
  - Auto-retry for transient web installer initialization failures.
- Firmware/UI maintenance:
  - Refined LiDAR quality indicator layout/docs.
  - Removed dead firmware code paths.
  - Fixed film-counter regression causing immediate roll-end on first advance.
  - Suppressed first transient updater error dialog while retrying.
- Release commit: `73722aa`
- Range: `8abf464..73722aa`

## 9.5.0 - 2026-02-17
- LiDAR and sensing pipeline updates:
  - Stabilized lens ADC sampling/calibration behavior.
  - Migrated DTS6012M integration to v2 API with CRC AUTO.
  - Bumped `DTS6012M_UART` to `v2.1.1`.
  - Tuned v2 filtering for stronger confidence behavior.
  - Added dual-target LiDAR fusion with staged calibration/confidence gating.
  - Added LiDAR quality indicator blocks in the main UI.
- Firmware refactor:
  - Modularized logic and removed duplication across firmware modules.
- Documentation updates:
  - Added/updated firmware manual assets and LiDAR v2 documentation.
  - Removed legacy firmware docs/PDF references.
- Release commit: `8abf464`
- Range: `4a8e8ab..8abf464`

## 9.0.0 - 2026-01-19
- Improved runtime behavior:
  - LiDAR reads made non-blocking.
  - Added parallax toggle and viewfinder-based framelines.
  - Moved hardcoded values into `mrfconstants`.
  - Added reset confirmation UI flow.
  - Refined lens distance update behavior and trimmed constants.
- Fixed/adjusted display behavior:
  - Frameline sizing and wide-format overflow handling.
  - Out-of-range LiDAR display clamping.
  - LiDAR UI refresh after sleep.
  - Light-meter clamping and refresh on ISO/aperture change.
- Release commit: `4a8e8ab`
- Range: `e23a8d5..4a8e8ab`

## 7.5 - 2025-12-19
- Refined parallax behavior and LiDAR calibration constants.
- Updated reticle alignment and LiDAR offset tuning.
- Added near-range correction and parallax guardrail constants.
- Release commit: `e23a8d5`
- Range: `4b1a976..e23a8d5`

## 7.0 - 2025-11-18
- Initial public firmware import for MRF2.
- Baseline ESP32-S3 firmware structure, display/UI flow, sensor integration, and build config.
- Release commit: `4b1a976`

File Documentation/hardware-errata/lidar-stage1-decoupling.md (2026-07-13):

# Errata: LiDAR power decoupling (breakout board)

> **Stage 1 · root cause + hand-solder fix.** Still valid as the background and the solder-in stopgap, but the board respin now follows **Stage 2** → [lidar-stage2-ldo-design.md](lidar-stage2-ldo-design.md). Start at the [errata index](README.md).

**Applies to:** MRF-Pro v7.5 breakout board (and earlier), DTS6012M LiDAR on connector J7.

**Status:** Closed avenue for the board respin. The decoupling-only design was built and the boards were ordered, but the bulk cap on the Feather 3.3 V rail caused a cold-start boot regression (see [Board respin](#board-respin-closed)), so the respin moved to the dedicated LDO in **Stage 2** ([lidar-stage2-ldo-design.md](lidar-stage2-ldo-design.md)), which ships on MRF-Pro-v8 (`PCBs/v2.0/`). This document stays valid as the **root-cause background and the hand-solder stopgap** for v1 (MRF-Pro-v7.5) boards.

## Symptom

- The LiDAR reads close objects fine but cannot range distant ones.
- Range is much worse outdoors, in open shade, or in direct sun.
- Hard to get a stable lock; readings jump or drop out at distance.
- A bench unit on a clean power supply behaves better than the same sensor in the camera.

## Root cause

The DTS6012M is a pulsed-laser time-of-flight sensor. Each laser pulse draws a short, sharp burst of current. On the current breakout the LiDAR's 3.3 V comes from the Feather's onboard regulator through a long, high-impedance path — across the main board, an FPC ribbon, a second FPC connector, thin (0.25 mm) copper, and the J7 JST connector — **with no decoupling capacitor anywhere near the sensor.** There is also no local capacitor on the Feather's regulator output for this load.

With no local charge reservoir, every laser pulse pulls its peak current through that whole impedance and the 3.3 V rail at the sensor sags during the exact moment it is trying to measure the return. Close, bright targets still work (little laser energy needed); distant or low-reflectivity targets and bright-ambient scenes — which need full laser power and maximum signal-to-noise — fail. The DTS6012M user manual itself notes the module has a dedicated `3V3_LASER` pin and advises ensuring sufficient supply current "or use an external 3.3 V regulator."

> Note: there is no DTS6012M current specification in this repository, so the capacitor values below are derived from a generic pulsed-laser ToF load model. Verify with the scope test before declaring the problem solved. This follows the project's "derived fix + field verification" convention.

## Fix (hand-solder, no board change)

Solder to the back of the breakout at/under J7, bridging the LiDAR 3.3 V and GND pads. **Keep all leads as short as possible — lead length adds inductance that defeats the purpose.**

Priority order:

1. **P1 — wideband decoupling at J7 (do this first, always).**
   A bulk capacitor in parallel with two smaller high-frequency ceramics, from LiDAR 3.3 V to GND:
   - **47–100 µF** bulk — a 47 µF/10 V tantalum, or a 100 µF 1206 X5R/X7R 6.3 V MLCC (size up because MLCCs lose 30–60 % of their value under DC bias).
   - **‖ 1 µF** 0603 ceramic.
   - **‖ 100 nF** 0402 ceramic.
   A single 10 µF cap is **not** enough: it derates to a few µF under bias and covers neither the bulk droop nor the high-frequency pulse edges.

2. **P2 — second HF cap on the laser pin.** If J7 breaks out `3V3_LASER` and `3V3` on separate pins, add another 1 µF + 100 nF on the laser pin specifically. If both module supply pins are tied together at the connector, P1 already covers it.

3. **P3 — stiffen the source.** Add 10 µF + 100 nF across the Feather 3V3↔GND on the main board, near where the FPC ribbon picks up 3.3 V.

4. **P4 — bypass the thin path (advanced).** Run short AWG 26–28 flying jumpers straight from the Feather 3V3 and GND pins to the J7 3.3 V/GND pads, paralleling the ribbon and JST. This is the single biggest improvement for the series-impedance half of the problem. Pair it with P1.

## Verifying the fix

Use an oscilloscope, not a multimeter — a DMM averages out the nanosecond transient and will look fine even when the rail is collapsing.

1. Probe the LiDAR VCC pin at J7, AC-coupled, ~20 mV/div.
2. Aim at a distant / low-reflectivity target in bright light and trigger a reading.
3. **Bad:** pulse-synchronous sag or ringing greater than ~100–150 mV, or the rail dipping toward 3.0 V.
4. **Good (after fix):** ripple shrinks to a few tens of mV and readings hold at distance.
5. Functional A/B: range a subject at 8–15 m before and after the fix; watch the **Setup > LiDAR > Diagnostics** screen — Intensity/Quality at distance should rise and the `err`/`Recov` counts should drop.

To collect comparable before/after data, use the [LiDAR field test protocol](lidar-field-test.md).

## Board respin (closed)

The fix was designed into the board so new units don't need hand-soldered caps. It was staged, and the staging is now settled — **Stage 2 is what shipped on MRF-Pro-v8** (`PCBs/v2.0/`):

**Stage 1 — decoupling only (closed, superseded).** C1 47 µF + C2 1 µF + C3 100 nF across the LiDAR 3.3 V rail. The decoupling-only board was built and ordered, but the 47 µF bulk on the Feather 3.3 V rail slowed the cold-start voltage ramp and broke the ESP32-S3 power-on reset: after a long time switched off, a single switch-on failed to boot. That regression closed this avenue as a standalone fix. The decoupling itself is correct and is retained behind the regulator in Stage 2.

**Stage 2 — dedicated regulator (shipped).** A dedicated low-noise 3.3 V regulator (TLV75533) for the LiDAR fed from VBAT, with the bulk relocated to the regulator output (`3V3_LIDAR`) so it no longer loads the MCU's reset rail. This delivers the original LiDAR power-integrity goal and fixes the cold-start regression in one change. Full design in [lidar-stage2-ldo-design.md](lidar-stage2-ldo-design.md); the decision was tracked on beads issue `IDENTIDEM_design-MRF2-3z5`.

Two facts found while tracing the current board shape the respin:

- **J7 already separates the DTS6012M's two supply pins** — pin 1 (`3V3_LASER`) and pin 2 (`3V3`) — so per-pin decoupling is possible without a connector change.
- **The 8-pin FPC has no spare conductors** (3.3 V and GND are already doubled up). A dedicated regulator therefore cannot simply add a VBAT line; it must repurpose one of the doubled 3.3 V conductors and have the main board drive it — a two-board change.

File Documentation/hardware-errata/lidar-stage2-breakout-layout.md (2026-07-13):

# Breakout layout spec — LiDAR LDO (Stage 2)

> **CURRENT — Stage 2 · breakout PCB layout.** The board half of the dedicated-LDO fix in [lidar-stage2-ldo-design.md](lidar-stage2-ldo-design.md); capture steps in [lidar-stage2-ldo-kicad-guide.md](lidar-stage2-ldo-kicad-guide.md). Supersedes the Stage-1 decoupling-only layout. Start at the [errata index](README.md).

This is the PCB-layout half of the LiDAR power fix on the breakout
(`PCBs/v2.0/Breakout/KiCAD/MRF-Pro-v8-breakout.kicad_pcb`). The schematic is
captured and ERC-clean; this document is the placement/routing intent for the
KiCad PCB editor (layout is GUI work — `kicad-cli` only runs DRC and exports).

Background and the "why" are in [lidar-stage1-decoupling.md](lidar-stage1-decoupling.md)
(root cause) and [lidar-stage2-ldo-design.md](lidar-stage2-ldo-design.md) (the design).

## What the schematic contains (as-built)

The breakout now carries a dedicated TLV75533 LDO fed from `VBAT`, with two
output rails split by a 0 Ω bead, and an EN pulldown:

| Ref | Value | Footprint | Net(s) | Role |
|-----|---|---|---|---|
| U1 | TLV75533 (3.3 V, 500 mA) | `Package_TO_SOT_SMD:SOT-23-5` | IN=`VBAT`, EN=`3.3V`, OUT=`3V3_LIDAR`, GND | The regulator |
| Cin1 | 1 µF | `Capacitor_SMD:C_0402_1005Metric` | `VBAT`/GND | Input decoupling at U1 IN |
| Cin2 | 10 µF | `Capacitor_SMD:C_0805_2012Metric` | `VBAT`/GND | Input bulk at U1 IN |
| C2 | 1 µF | `Capacitor_SMD:C_0603_1608Metric` | `3V3_LIDAR`/GND | LDO stability cap at U1 OUT |
| C3 | 100 nF | `Capacitor_SMD:C_0402_1005Metric` | `3V3_LIDAR`/GND | HF bypass at U1 OUT |
| C1 | 47 µF | bulk | `3V3_LASER`/GND | Laser-pulse reservoir at J7 pin 1 |
| FB1 | 0 Ω (ferrite option) | `0805` | `3V3_LIDAR`↔`3V3_LASER` | Splits the two output rails |
| R1 | 100 kΩ | `Resistor_SMD:R_0402_1005Metric` | `3.3V`/GND | EN pulldown — deterministic shutdown |

Rails: `VBAT` (battery in, always present) → U1 → `3V3_LIDAR` (logic, J7 pin 2)
→ FB1 → `3V3_LASER` (laser, J7 pin 1). The switched `3.3V` on FPC pin 6 drives
U1 EN, the Stemma QT (J6), and R1.

## Connector facts that drive placement

From the as-built netlist:

- **J7 (DTS6012M, 6-pin):** pin 1 = `3V3_LASER`, pin 2 = `3V3_LIDAR` (logic) —
  two separate post-LDO rails split by FB1. Pins 3/4 = UART (to FPC pins 2/3).
  **Pin 5 = INT mode-select tied to GND** (low = UART; do not disturb). Pin 6 = GND.
- **J5 (FPC, 8-pin):** pin 1 = `VBAT` (U1 IN), pin 6 = switched `3.3V`
  (U1 EN + J6 + R1), pins 4/5 = GND, pins 2/3 = UART → J7, pins 7/8 = I²C → J6.
  VBAT sits next to the UART pins, the switched 3.3 V next to the I²C pins.
- **J6 (Stemma QT):** on the switched `3.3V` / I²C; carries the I²C bus to the
  rotary encoder and the rest of the peripherals.

## Layout steps

1. **Update PCB from Schematic** (F8) to pull in U1, Cin1/Cin2, FB1, **R1**, and
   the renamed nets (`VBAT`, `3V3_LIDAR`, `3V3_LASER`).
2. **Make the clean rail at the sensor** — proximity is everything (lead/track
   inductance defeats decoupling):
   - **U1 right next to J7**, so `3V3_LIDAR` is generated at the load.
   - **C2 (1 µF) + C3 (100 nF) hard against U1 OUT** (the LDO's required Cout, on
     the near side of FB1) and close to J7 pin 2.
   - **C1 (47 µF bulk) hard against J7 pin 1 (`3V3_LASER`)** — the pulsed laser
     load, on the far side of FB1.
   - **Cin1 + Cin2 tight to U1 IN** on `VBAT`.
   - **FB1 between** the U1-OUT node and the C1/laser node.
   - **R1 near U1 EN** (anywhere on the `3.3V` net is electrically fine).
   - Mount on the back of the board directly under J7 if the front is congested.
3. **Widen the supply copper.** Keep the `VBAT` run into U1 and the
   `3V3_LIDAR`/`3V3_LASER` runs out of it short and wide (≥0.5–0.8 mm or filled
   zones). The `VBAT` ribbon path is a regulator *input*, so series drop there is
   harmless as long as it stays above dropout — but keep the on-breakout legs tidy.
4. **Stitch the grounds.** Several **GND vias** near U1, the caps, and J7 to tie
   front/back copper and give the laser pulse a low-inductance return.
5. **Test points.** Add probe points (or 0 Ω-pad pads) on **`3V3_LIDAR`** and
   **`VBAT`** so the scope verification can be done without tacking onto J7.
6. **Refill zones**, then **DRC** until clean.
7. **Regenerate fab outputs** (Gerbers, drill, BOM, position files). The new
   parts (U1, Cin1, Cin2, FB1, R1) carry LCSC fields for the JLCPCB BOM/CPL.

## Sign-off

Scope the LiDAR VCC at J7, AC-coupled, during a far / bright-light reading:
pulse-synchronous ripple should drop to a few tens of mV and far readings should
hold. Then confirm the [design's verification list](lidar-stage2-ldo-design.md#verification):
`3V3_LIDAR` collapses to 0 V at power-off (deterministic via R1), off-state
battery draw ~µA, cold-start boots first try, and a before/after range
improvement using the [field test protocol](lidar-field-test.md).

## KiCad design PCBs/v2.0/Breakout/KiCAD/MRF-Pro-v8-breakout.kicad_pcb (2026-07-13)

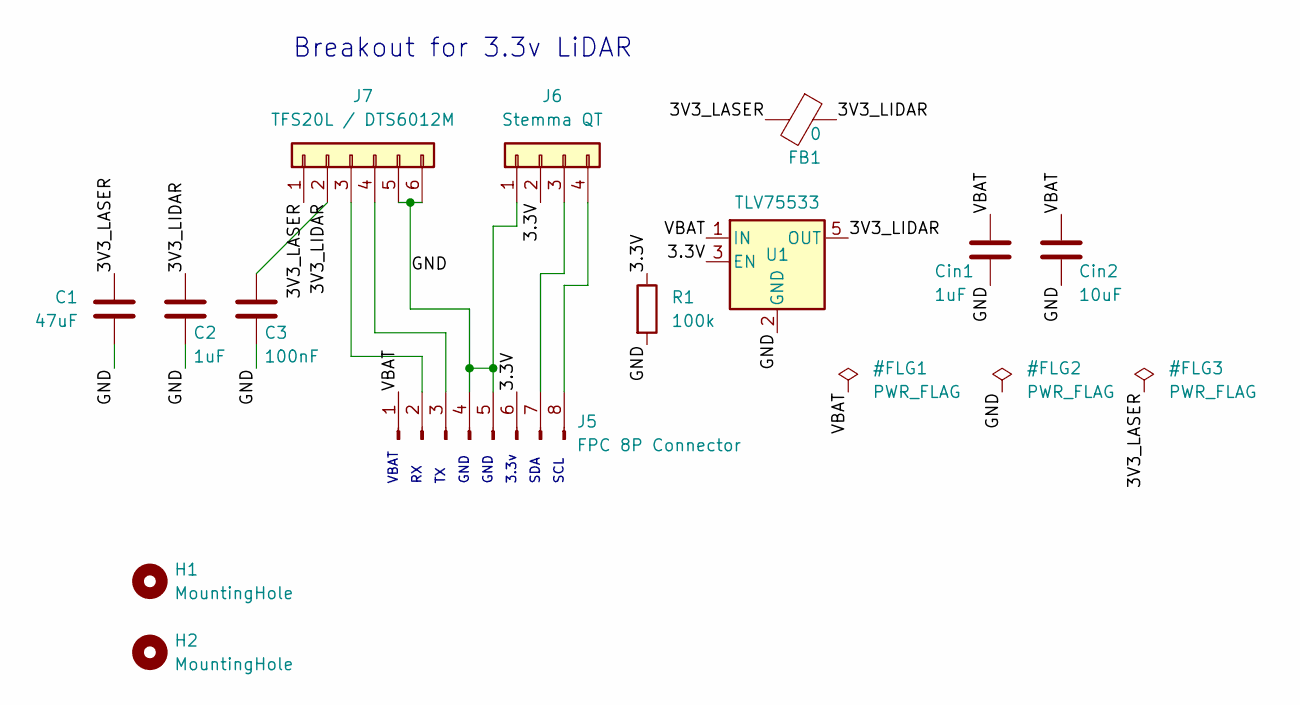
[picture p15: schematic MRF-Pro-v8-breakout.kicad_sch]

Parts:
C1: 47uF; C_1206_3216Metric; LCSC C96123
C2: 1uF; C_0603_1608Metric; LCSC C15849
C3: 100nF; C_0402_1005Metric; LCSC C1525
Cin1: 1uF; C_0402_1005Metric; LCSC C52923
Cin2: 10uF; C_0805_2012Metric; LCSC C15850
FB1: 0; L_0805_2012Metric; LCSC C17477
H1, H2: MountingHole; MountingHole_2.2mm_M2
J5: FPC 8P Connector; TE_0-1734839-8_1x08-1MP_P0.5mm_Horizontal; LCSC C2856797
J6: Stemma QT; JST_SH_SM04B-SRSS-TB_1x04-1MP_P1.00mm_Horizontal; LCSC C7430446
J7: TFS20L / DTS6012M; JST_SH_SM06B-SRSS-TB_1x06-1MP_P1.00mm_Horizontal; LCSC C7430448
R1: 100k; R_0402_1005Metric; LCSC C25741
U1: TLV75533; SOT-23-5; LCSC C404027

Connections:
/3.3V: J5.6, J6.2, R1.1, U1.3 (EN)
/3V3_LASER: C1.1, FB1.2, J7.1
/3V3_LIDAR: C2.1, C3.1, FB1.1, J7.2, U1.5 (OUT)
/GND: C1.2, C2.2, C3.2, Cin1.2, Cin2.2, J5.4, J5.5, J6.1, J7.5, J7.6, R1.2, U1.2 (GND)
/VBAT: Cin1.1, Cin2.1, J5.1, U1.1 (IN)
unnamed: J5.2, J7.3
unnamed: J5.3, J7.4
unnamed: J5.7, J6.3
unnamed: J5.8, J6.4

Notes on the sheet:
VBAT
SCL
GND
SDA
Breakout for 3.3v LiDAR
3.3v

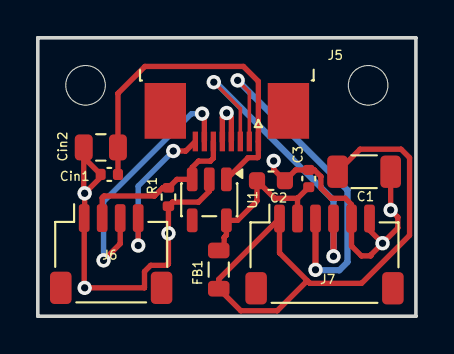
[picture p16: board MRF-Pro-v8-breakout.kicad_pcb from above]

Board: 2 copper layers, 21.0 x 15.5 mm, 13 parts (0 on the bottom side), 9 nets.

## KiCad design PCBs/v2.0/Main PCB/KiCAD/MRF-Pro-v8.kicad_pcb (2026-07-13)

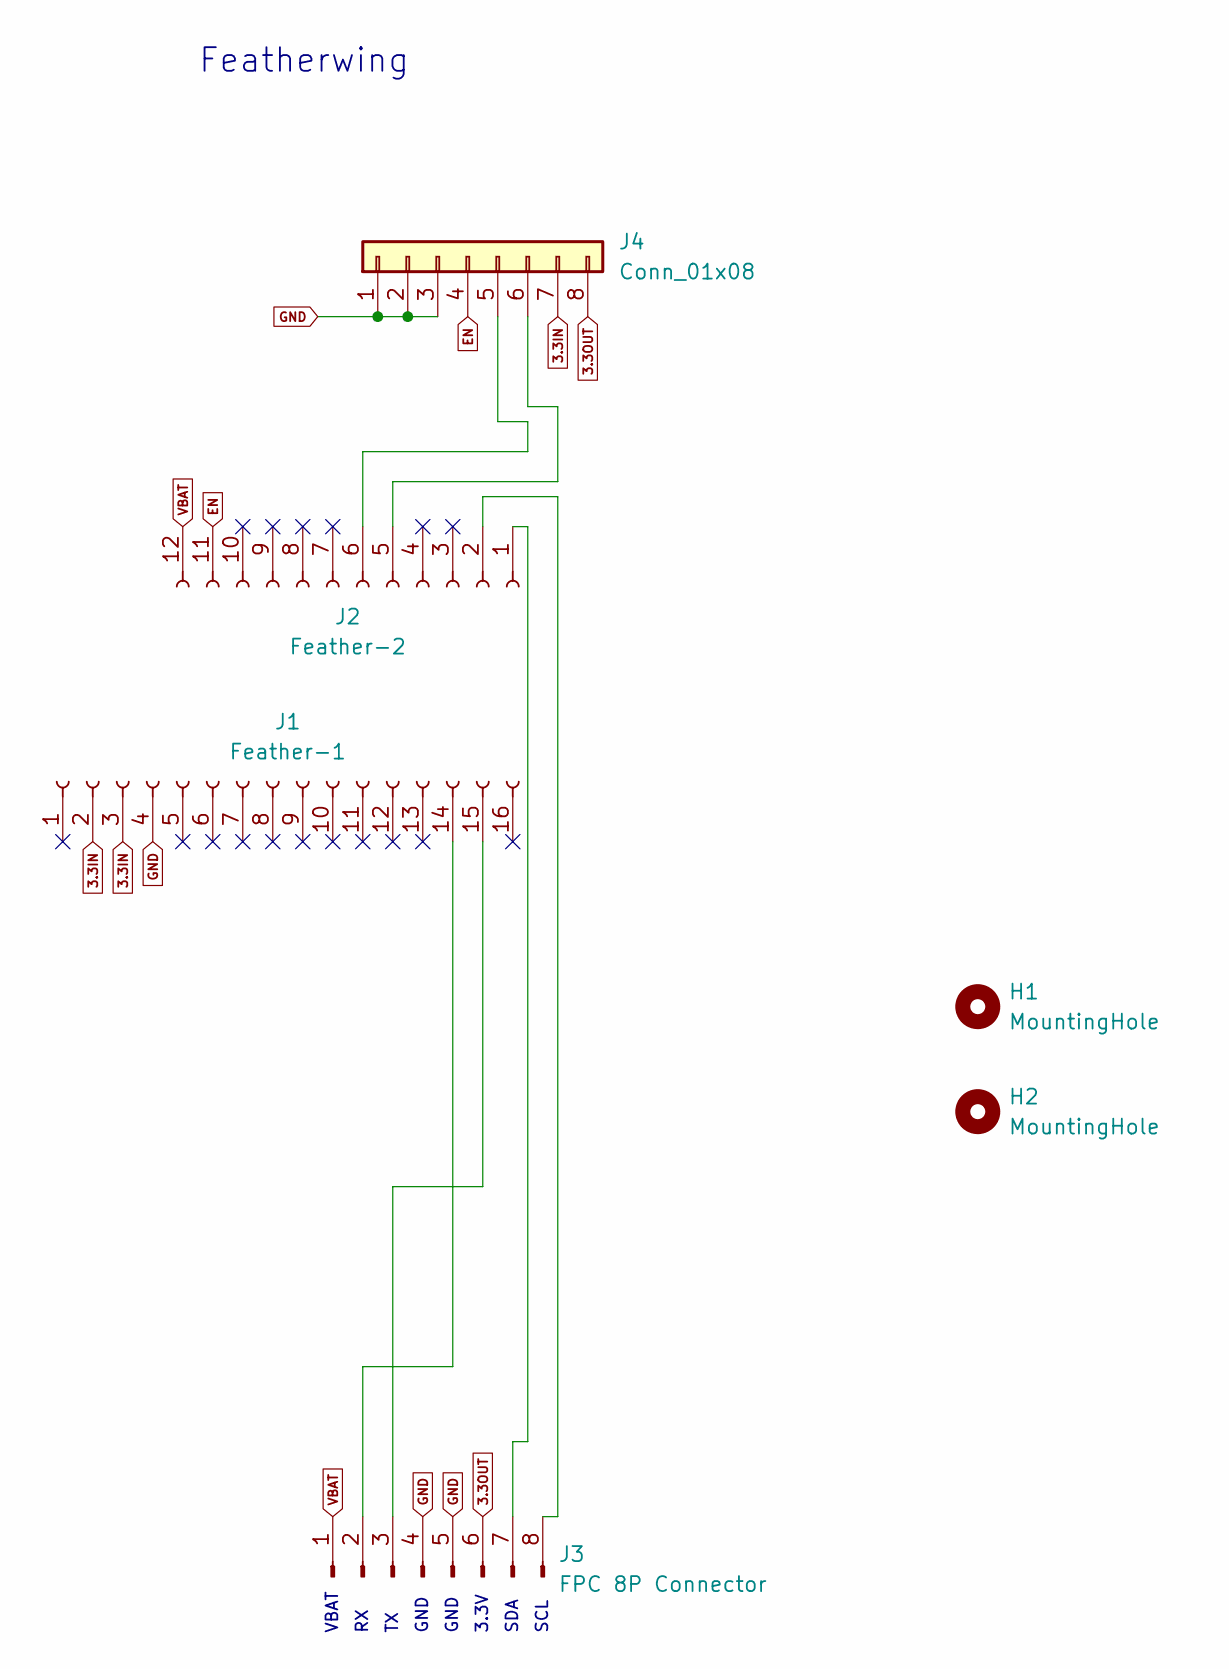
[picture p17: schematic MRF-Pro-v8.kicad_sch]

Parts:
H1, H2: MountingHole; MountingHole_2.2mm_M2
J1: Feather-1; PinHeader_1x16_P2.54mm_Vertical
J2: Feather-2; PinHeader_1x12_P2.54mm_Vertical
J3: FPC 8P Connector; TE_0-1734839-8_1x08-1MP_P0.5mm_Horizontal; LCSC C2856797
J4: Conn_01x08; JST_SH_BM08B-SRSS-TB_1x08-1MP_P1.00mm_Vertical; LCSC C7430450

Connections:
3.3IN: J1.2, J1.3, J4.7
3.3OUT: J3.6, J4.8
EN: J2.11, J4.4
GND: J1.4, J3.4, J3.5, J4.1, J4.2, J4.3
unnamed: J1.14, J3.2
unnamed: J1.15, J3.3
unnamed: J2.1, J3.7
unnamed: J2.2, J3.8
unnamed: J2.5, J4.6
unnamed: J2.6, J4.5
VBAT: J2.12, J3.1

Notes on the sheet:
SDA
GND
Featherwing
VBAT
3.3V
SCL

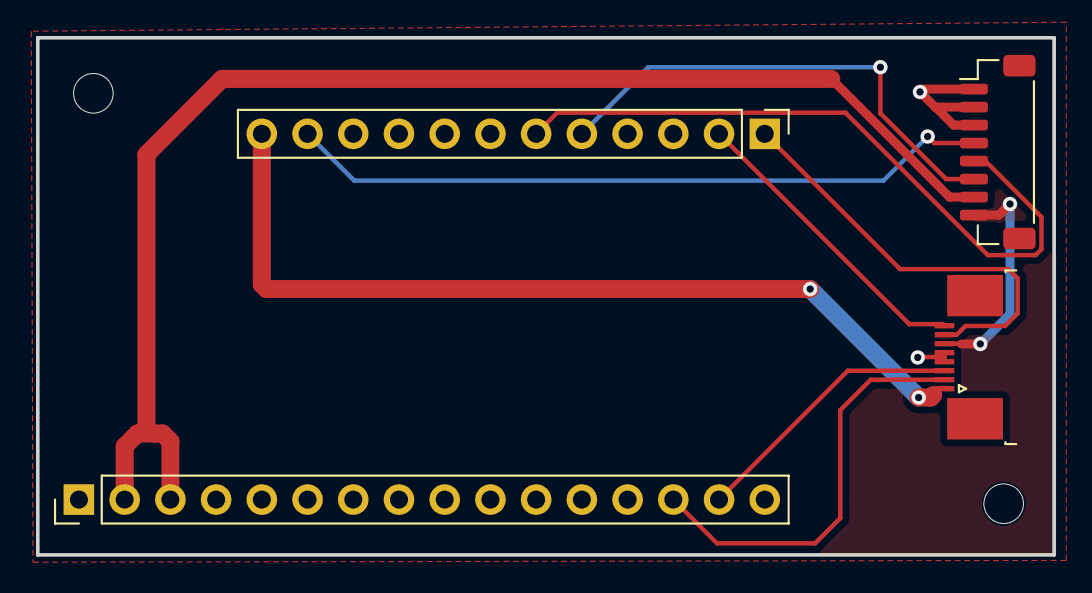
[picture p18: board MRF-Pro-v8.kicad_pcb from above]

Board: 2 copper layers, 56.5 x 28.7 mm, 6 parts (0 on the bottom side), 11 nets.

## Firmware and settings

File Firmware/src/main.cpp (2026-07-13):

// IDENTIDEM.design Medium Format Rangefinder firmware v10.3.0
// Hardware: DTS6012M LiDAR, STEMMA I2C QT Rotary Encoder (4991), SH1107 main + SSD1306 external OLEDs

#include <Arduino.h>
#include <stdio.h>
#include <string.h>

#include "esp_wifi.h"
#include "esp_bt.h"

#include "globals.h"
#include "hardware.h"
#include "helpers.h"
#include "loop_runtime.h"
#include "mrfconstants.h"
#include "boot_animation_logic.h"
#include "setfuncs.h"

namespace
{
int bootProgressStep = 0;
const int BOOT_PROGRESS_TOTAL = 5;
const char *bootProgressLabel = "";

void drawBootProgress()
{
  if (!hardware.mainDisplay)
  {
    return;
  }

  display.clearDisplay();
  u8g2.setFontMode(1);
  u8g2.setFontDirection(0);
  u8g2.setForegroundColor(SH110X_WHITE);
  u8g2.setBackgroundColor(SH110X_BLACK);

  u8g2.setFont(u8g2_font_6x10_mf);
  const char *title = "Initialising...";
  int titleWidth = static_cast<int>(strlen(title)) * 6;
  u8g2.setCursor((SCREEN_WIDTH - titleWidth) / 2, 55);
  u8g2.print(title);

  // Draw progress bar.
  const int barWidth = 80;
  const int barHeight = 6;
  const int barX = (SCREEN_WIDTH - barWidth) / 2;
  const int barY = 65;
  display.drawRect(barX, barY, barWidth, barHeight, SH110X_WHITE);

  int fillWidth = (barWidth - 2) * bootProgressStep / BOOT_PROGRESS_TOTAL;
  if (fillWidth > 0)
  {
    display.fillRect(barX + 1, barY + 1, fillWidth, barHeight - 2, SH110X_WHITE);
  }

  // Show which peripheral is being initialised.
  if (bootProgressLabel[0] != '\0')
  {
    u8g2.setFont(u8g2_font_4x6_mf);
    int labelWidth = static_cast<int>(strlen(bootProgressLabel)) * 4;
    u8g2.setCursor((SCREEN_WIDTH - labelWidth) / 2, 80);
    u8g2.print(bootProgressLabel);
  }

  display.display();
}

void advanceBootProgress(const char *label)
{
  bootProgressStep++;
  bootProgressLabel = label;
  drawBootProgress();
}

void logPeripheralInitStatus(const __FlashStringHelper *name, bool ok)
{
  Serial.print(name);
  Serial.print(F(": "));
  Serial.println(ok ? F("OK") : F("FAILED"));
}

void disableWirelessRadios()
{
  esp_wifi_stop();            // Stop WiFi to save power.
  esp_bt_controller_disable(); // Stop Bluetooth to save power.
}

void configureButton(Bounce2::Button &button, int pin)
{
  button.attach(pin, INPUT_PULLUP);
  button.interval(BUTTON_DEBOUNCE_MS);
  button.setPressedState(LOW);
}

void initializeInputHardware()
{
  hardware.ads = theads.begin();
  logPeripheralInitStatus(F("ADS1015"), hardware.ads);
  hardware.mpu = mpu.begin();
  logPeripheralInitStatus(F("MPU6050"), hardware.mpu);

  if (hardware.ads)
  {
    // readADC_SingleEnded() busy-waits one conversion period, so the data rate
    // sets how long each lens read blocks the cooperative loop. 128 SPS meant
    // ~8 ms per conversion (~24 ms for the 3-sample average) stalling buttons and
    // the encoder; 920 SPS drops that to ~1.1 ms each. The lens pot signal is
    // large and slow, and the 3-sample average plus moving-average/spike filters
    // absorb the slightly wider per-sample noise at the higher rate.
    theads.setDataRate(RATE_ADS1015_920SPS);
    theads.setGain(GAIN_TWOTHIRDS);
  }

  configureButton(lbutton, BUTTON_LEFT_PIN);
  configureButton(rbutton, BUTTON_RIGHT_PIN);
}

void initializeMainDisplay()
{
  delay(DISPLAY_INIT_DELAY_MS); // Slight delay or the displays won't work.

  hardware.mainDisplay = display.begin(SCREEN_ADDRESS, true);
  logPeripheralInitStatus(F("Main OLED"), hardware.mainDisplay);
  if (hardware.mainDisplay)
  {
    display.oled_command(DISPLAY_COMMAND_FLIP);
    display.setRotation(DISPLAY_ROTATION);
    u8g2.begin(display);
    display.clearDisplay();
    display.display();
  }

  delay(DISPLAY_EXT_INIT_DELAY_MS); // Slight delay or the displays won't work.
  hardware.externalDisplay = display_ext.begin(SSD1306_SWITCHCAPVCC, SCREEN_ADDRESS_EXT);
  logPeripheralInitStatus(F("Ext OLED"), hardware.externalDisplay);
}

void showBootScreenOnExternalDisplay()
{
  if (!hardware.externalDisplay)
  {
    return;
  }

  display_ext.clearDisplay();
  display_ext.setTextColor(SSD1306_WHITE);
  // Text wrap must be off: the animation deliberately positions the version
  // off the right edge at the start of the roll. With Adafruit_GFX's default
  // wrap enabled, an off-screen cursor resets to x=0 one text line lower,
  // painting stray glyphs along the bottom of the panel. Wrap off clips them.
  display_ext.setTextWrap(false);

  char bootText[24];
  snprintf(bootText, sizeof(bootText), "MRF %s", FWVERSION);

  // Pick the largest text size (up to the preferred one) that fits the display
  // width, so a longer version string (e.g. 10.6.10) can't wrap on the narrow
  // external screen.
  int16_t bootTextX1 = 0;
  int16_t bootTextY1 = 0;
  uint16_t bootTextWidth = 0;
  uint16_t bootTextHeight = 0;
  for (int bootTextSize = DISPLAY_BOOT_TEXT_SIZE; bootTextSize >= 1; bootTextSize--)
  {
    display_ext.setTextSize(static_cast<uint8_t>(bootTextSize));
    display_ext.getTextBounds(bootText, 0, 0, &bootTextX1, &bootTextY1, &bootTextWidth, &bootTextHeight);
    if (static_cast<int16_t>(bootTextWidth) <= display_ext.width())
    {
      break;
    }
  }

  const int16_t bootCursorY =
      ((display_ext.height() - static_cast<int16_t>(bootTextHeight)) / 2) - bootTextY1;

  // Film-advance animation: perforations tick left along the top and bottom
  // edges while the version rides in from the right and eases to centre.
  for (int frame = 0; frame < DISPLAY_BOOT_ANIM_FRAMES; frame++)
  {
    display_ext.clearDisplay();

    const int sprocketOffset =
        bootSprocketOffsetForFrame(frame, DISPLAY_BOOT_SPROCKET_STEP, DISPLAY_BOOT_SPROCKET_SPACING);
    for (int x = sprocketOffset - DISPLAY_BOOT_SPROCKET_SPACING; x < display_ext.width();
         x += DISPLAY_BOOT_SPROCKET_SPACING)
    {
      display_ext.fillRect(x, 0, DISPLAY_BOOT_SPROCKET_W, DISPLAY_BOOT_SPROCKET_H, SSD1306_WHITE);
      display_ext.fillRect(x, display_ext.height() - DISPLAY_BOOT_SPROCKET_H,
                           DISPLAY_BOOT_SPROCKET_W, DISPLAY_BOOT_SPROCKET_H, SSD1306_WHITE);
    }

    const int textX = bootTextXForFrame(frame, DISPLAY_BOOT_ANIM_FRAMES,
                                        display_ext.width(), static_cast<int>(bootTextWidth));
    display_ext.setCursor(static_cast<int16_t>(textX) - bootTextX1, bootCursorY);
    display_ext.print(bootText);

    display_ext.display();
    delay(DISPLAY_BOOT_ANIM_FRAME_MS);
  }

  // Hold the settled frame, then clear and hand the panel to u8g2_ext as before.
  delay(DISPLAY_BOOT_SCREEN_MS);

  u8g2_ext.begin(display_ext);
  display_ext.clearDisplay();
  display_ext.display();
}

void initializeLidarSensor()
{
  // Start the LiDAR sensor using the v2 initialization interface.
  DTSResult lidarInit = lidar.begin(LIDAR_BAUD_RATE, RXD2, TXD2);
  if (lidarInit != DTSError::NONE)
  {
    hardware.lidarSensor = false;
    lidarEnabled = false;
    Serial.print(F("LiDAR init error: "));
    Serial.println(static_cast<int>(static_cast<DTSError>(lidarInit)));
  }
  else
  {
    hardware.lidarSensor = true;
    lidarEnabled = true;

    // Query sensor firmware version for diagnostics display.
    byte versionBuf[8] = {};
    uint8_t versionLen = 0;
    if (lidar.getFirmwareVersion(versionBuf, sizeof(versionBuf), versionLen) == DTSError::NONE && versionLen > 0)
    {
      int written = 0;
      for (uint8_t i = 0; i < versionLen && written < static_cast<int>(sizeof(lidar_sensor_fw_version)) - 1; i++)
      {
        written += snprintf(lidar_sensor_fw_version + written,
                            sizeof(lidar_sensor_fw_version) - written, "%02X", versionBuf[i]);
      }
    }

    lidar.setFrameRate(LIDAR_FRAME_RATE_FPS);
    // Read back what the sensor actually latched — surfaced on the LiDAR
    // diagnostics screen so a tester can confirm whether a requested sub-50fps
    // rate was accepted. Boot only; never re-issued on the recovery path.
    uint16_t actual_fps = 0;
    if (lidar.getFrameRate(actual_fps) == DTSError::NONE)
    {
      lidar_frame_rate_actual = actual_fps;
    }
    applyLidarCalibrationProfile();
  }

  delay(LIDAR_SERIAL_STARTUP_DELAY_MS);
}

void initializePowerAndInputPeripherals()
{
  hardware.batteryGauge = maxlipo.begin();
  if (!hardware.batteryGauge)
  {
    // maxlipo.begin() fails when the Seesaw (also at I2C address 0x36) ACKs
    // the soft-reset write that MAX17048 deliberately NACKs as part of its
    // initialisation sequence. i2c_dev is still valid at this point.
    // The Seesaw protocol uses two-byte register addresses so it does not
    // respond to the single-byte register reads that MAX17048 uses; SOC reads
    // therefore return accurate data despite the shared address. Confirm the
    // gauge is present by checking that a direct SOC read is plausible.
    float testPct = maxlipo.cellPercent();
    hardware.batteryGauge = (testPct >= 0.0f && testPct <= 100.0f);
  }
  logPeripheralInitStatus(F("MAX17048"), hardware.batteryGauge);

  hardware.lightMeter = lightMeter.begin();
  logPeripheralInitStatus(F("BH1750"), hardware.lightMeter);

  hardware.statusPixel = sspixel.begin(SEESAW_ADDR);
  logPeripheralInitStatus(F("Seesaw Pixel"), hardware.statusPixel);
  if (hardware.statusPixel)
  {
    delay(SEESAW_INIT_DELAY_MS);
    sspixel.setBrightness(SEESAW_NEOPIXEL_BRIGHTNESS);
    sspixel.show();
  }

  hardware.encoder = encoder.begin(SEESAW_ADDR);
  logPeripheralInitStatus(F("Seesaw Encoder"), hardware.encoder);
  if (hardware.encoder)
  {
    delay(SEESAW_INIT_DELAY_MS);
    encoder.setEncoderPosition(encoder_value);
    encoder.enableEncoderInterrupt();
  }
}
} // namespace

void setup()
{
  Serial.begin(SERIAL_BAUD_RATE);

  disableWirelessRadios();
  loadPrefs();
  initializeInputHardware();

  // Initialize here because globals are set before millis() is reliable.
  lastActivityTime = millis();

  initializeMainDisplay();
  drawBootProgress(); // Show initial progress on main display.
  showBootScreenOnExternalDisplay();
  advanceBootProgress("Displays");
  initializeLidarSensor();
  advanceBootProgress("LiDAR");
  resetLensMovingAverageState();
  advanceBootProgress("Lens filter");
  initializePowerAndInputPeripherals();
  advanceBootProgress("Peripherals");
  setVoltage(); // Populate bat_per before the first loop tick.
  advanceBootProgress("Ready");

  // Treat end-of-setup as the idle timer baseline.
  lastActivityTime = millis();
  sleepMode = false;
}

void loop()
{
  runLoopRuntimeIteration(millis());
}

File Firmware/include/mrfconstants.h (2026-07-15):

#ifndef MRFCONSTANTS_H
#define MRFCONSTANTS_H

#include <stdint.h>

// ---------------------------------------------------------------------------
// Firmware identity and boot behavior
// ---------------------------------------------------------------------------
#define FWVERSION "10.7.0"                   // Version shown in UI and release metadata.
const unsigned long SLEEP_BOOT_GRACE_MS = 15000; // Ignore sleep timer immediately after boot.

// ---------------------------------------------------------------------------
// Serial ports and sensor transport
// ---------------------------------------------------------------------------
const unsigned long SERIAL_BAUD_RATE = 115200; // USB serial console baud.
const unsigned long LIDAR_BAUD_RATE = 921600;  // DTS6012M UART baud.
const int LIDAR_SERIAL_PORT = 2;               // ESP32 hardware serial index used for LiDAR.

#define RXD2 RX // LiDAR RX mapped to board RX pin.
#define TXD2 TX // LiDAR TX mapped to board TX pin.

// ---------------------------------------------------------------------------
// User input buttons
// ---------------------------------------------------------------------------
const int BUTTON_LEFT_PIN = 9;                 // Left button GPIO.
const int BUTTON_RIGHT_PIN = 10;               // Right button GPIO.
const int BUTTON_DEBOUNCE_MS = 5;              // Software debounce interval.
const unsigned long BUTTON_SHORT_PRESS_MAX_MS = 1000; // Max press duration treated as "short".
const unsigned long BUTTON_LONG_PRESS_MIN_MS = 3000;  // Min press duration treated as "long".

// ---------------------------------------------------------------------------
// Seesaw and NeoPixel status LED
// ---------------------------------------------------------------------------
#define SS_NEOPIX 6      // Seesaw pin used by onboard NeoPixel.
#define SEESAW_ADDR 0x36 // I2C address for encoder/NeoPixel seesaw.

const unsigned long SEESAW_INIT_DELAY_MS = 10; // Delay after seesaw init before first access.
const int SEESAW_NEOPIXEL_BRIGHTNESS = 80;     // NeoPixel brightness cap (0..255).
const int NEOPIXEL_COUNT = 1;                  // Number of status pixels.
const int NEOPIXEL_INDEX = 0;                  // Active status pixel index.
const int NEOPIXEL_COLOR_MAX = 255;            // Max RGB channel value.
const int NEOPIXEL_BLUE_R = 0;                 // Blue status color R channel.
const int NEOPIXEL_BLUE_G = 0;                 // Blue status color G channel.
const int NEOPIXEL_BLUE_B = 255;               // Blue status color B channel.
const int NEOPIXEL_VIOLET_R = 238;             // Violet status color R channel.
const int NEOPIXEL_VIOLET_G = 130;             // Violet status color G channel.
const int NEOPIXEL_VIOLET_B = 238;             // Violet status color B channel.
const int NEOPIXEL_OFF_R = 0;                  // LED-off R channel.
const int NEOPIXEL_OFF_G = 0;                  // LED-off G channel.
const int NEOPIXEL_OFF_B = 0;                  // LED-off B channel.

// ---------------------------------------------------------------------------
// Analog lens position input
// ---------------------------------------------------------------------------
#define LENS_ADC_PIN 1 // ADS1015 channel for lens position sensor.

// ---------------------------------------------------------------------------
// Display and I2C bus setup
// ---------------------------------------------------------------------------
#define SCREEN_WIDTH 128        // Main OLED width in pixels.
#define SCREEN_HEIGHT 128       // Main OLED height in pixels.
#define SCREEN_HEIGHT_EXT 32    // External OLED height in pixels.
#define OLED_RESET -1           // Shared reset pin (unused, set to -1).
#define SCREEN_ADDRESS 0x3D     // Main OLED I2C address.
#define SCREEN_ADDRESS_EXT 0x3C // External OLED I2C address.
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

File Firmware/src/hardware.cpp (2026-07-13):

#include "hardware.h"
#include "mrfconstants.h" // For pin/address constants and screen dimensions

#include <Arduino.h> // For HardwareSerial
#include <Wire.h>    // For I2C devices & display

#include <Adafruit_seesaw.h>
#include <seesaw_neopixel.h> // Correct header for seesaw_NeoPixel
#include <Adafruit_ADS1X15.h>
#include <Adafruit_MPU6050.h>
#include <Adafruit_MAX1704X.h>
#include <BH1750.h>
#include <DTS6012M_UART.h>
#include <Adafruit_SH110X.h> // For SH1107
#include <Adafruit_SSD1306.h>
#include <U8g2_for_Adafruit_GFX.h>
#include <Bounce2.h>

// Hardware init
// ---------------------
// Inputs
Adafruit_seesaw encoder;
Adafruit_ADS1015 theads;
Adafruit_MPU6050 mpu;
seesaw_NeoPixel sspixel = seesaw_NeoPixel(NEOPIXEL_COUNT, SS_NEOPIX, NEO_GRB + NEO_KHZ800);
Bounce2::Button lbutton = Bounce2::Button();
Bounce2::Button rbutton = Bounce2::Button();

// Battery gauge
Adafruit_MAX17048 maxlipo;
// Lightmeter
BH1750 lightMeter;
// LiDAR setup
namespace
{
HardwareSerial lidarSerial(LIDAR_SERIAL_PORT); // Using serial port 2

DTSConfig makeLidarConfig()
{
  DTSConfig config;
  config.baudRate = LIDAR_BAUD_RATE;
  config.timeout_ms = LIDAR_NO_DATA_TIMEOUT_MS;
  config.minValidDistance_mm = DISTANCE_MIN * LIDAR_DISTANCE_DIVISOR;
  // Sensor's rated range, not the frameline parallax cap (DISTANCE_MAX = 18m).
  // From library 3.0.0 maxValidDistance_mm gates quality grading and the median
  // filter: a genuine far return beyond it grades POOR and is dropped from the
  // smoothed distance. The camera's own 18m display-to-"Inf." policy lives in
  // LIDAR_DISPLAY_INF_THRESHOLD_CM, so let the library trust the full 20m.
  config.maxValidDistance_mm = LIDAR_LIBRARY_MAX_VALID_DISTANCE_MM;
  config.minIntensityThreshold = LIDAR_LIBRARY_MIN_INTENSITY_THRESHOLD;
  config.crcByteOrder = DTSCRCByteOrder::AUTO;
  config.crcAutoSwitchErrorThreshold = 10;
  // Ambient-light gate (library 3.0.0) left OFF deliberately. The outdoor-range
  // investigation found sunlightBase reads a flat ~13 outdoors — it measures
  // ambient at the sensor aperture behind the bandpass filter, not the solar
  // 905nm reflecting off the sunlit target that actually causes the range
  // cliff. Gating on it would reject valid frames without fixing the cliff.
  config.maxSunlightBase = 0;
  return config;
}
} // namespace

DTS6012M_UART lidar(lidarSerial, makeLidarConfig());
// Display setup
Adafruit_SH1107 display(SCREEN_WIDTH, SCREEN_HEIGHT, &Wire, OLED_RESET, DISPLAY_I2C_FREQUENCY_HZ, SHARED_I2C_FREQUENCY_HZ);
Adafruit_SSD1306 display_ext(SCREEN_WIDTH, SCREEN_HEIGHT_EXT, &Wire, OLED_RESET);
U8G2_FOR_ADAFRUIT_GFX u8g2;
U8G2_FOR_ADAFRUIT_GFX u8g2_ext;
// ---------------------

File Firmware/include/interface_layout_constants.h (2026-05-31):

#ifndef INTERFACE_LAYOUT_CONSTANTS_H
#define INTERFACE_LAYOUT_CONSTANTS_H

// Pixel coordinates for the on-OLED user interface. These are display-only
// concerns; nothing outside interface.cpp needs them. Kept out of
// mrfconstants.h so a layout tweak doesn't force a full-tree rebuild and so
// the central constants file stays focused on cross-module behaviour tuning.

// ---------------------------------------------------------------------------
// Main display layout coordinates
// ---------------------------------------------------------------------------
const int MAIN_HEADER_HEIGHT = 15;         // Header bar height.
const int MAIN_RETICLE_CENTER_Y_OFFSET = 5; // Reticle center vertical offset.
const int MAIN_RETICLE_CENTER_RADIUS = 3;  // Reticle center dot radius.
const int MAIN_ISO_X = 2;                  // ISO label X position.
const int MAIN_ISO_Y = 7;                  // ISO label Y position.
const int MAIN_APERTURE_X = 46;            // Aperture label X position.
const int MAIN_APERTURE_Y = 7;             // Aperture label Y position.
const int MAIN_SHUTTER_X = 2;              // Shutter label X position.
const int MAIN_SHUTTER_Y = 14;             // Shutter label Y position.
const int MAIN_DISTANCE_X = 68;            // LiDAR distance label X position.
const int MAIN_DISTANCE_Y = 7;             // LiDAR distance label Y position.
const int MAIN_LENS_X = 68;                // Lens distance label X position.
const int MAIN_LENS_Y = 14;                // Lens distance label Y position.
const int MAIN_LIDAR_QUALITY_X = 123;      // LiDAR quality indicator origin X.
const int MAIN_LIDAR_QUALITY_Y = 2;        // LiDAR quality indicator origin Y.
const int MAIN_LIDAR_QUALITY_SIZE = 2;     // LiDAR quality block size.
const int MAIN_LIDAR_QUALITY_GAP = 1;      // Gap between LiDAR quality blocks.
const int MAIN_SUNLIGHT_ICON_CX = 116;     // Centre X of the high-sunlight indicator (sits in the gap before the quality blocks).
const int MAIN_SUNLIGHT_ICON_CY = 4;       // Centre Y of the high-sunlight indicator.

// ---------------------------------------------------------------------------
// Setup/calibration/health UI layout coordinates
// ---------------------------------------------------------------------------
const int CONFIG_TITLE_X = 3;              // Setup title X position.
const int CONFIG_TITLE_Y = 15;             // Setup title Y position.
const int CONFIG_HEADER_PADDING_Y = 4;     // Vertical padding below setup title.
const int CONFIG_ITEM_X = 3;               // Setup item X position.
const int CONFIG_ITEM_Y_START = 22;        // Setup item Y start.
const int CONFIG_ITEM_Y_STEP = 9;          // Setup item Y spacing.
const int CONFIG_FOOTER_Y = 121;           // Setup footer Y position.
const int CALIB_TITLE_X = 3;               // Calibration title X position.
const int CALIB_TITLE_Y = 15;              // Calibration title Y position.
const int CALIB_ITEM_X = 3;                // Calibration item X position.
const int CALIB_LENS_Y = 35;               // Calibration lens line Y position.
const int CALIB_DISTANCE_Y = 47;           // Calibration distance line Y position.
const int CALIB_PROGRESS_BAR_Y = 53;       // Calibration progress bar Y (below distance line).
const int CALIB_HELP_Y1 = 70;              // Calibration help line 1 Y.
const int CALIB_HELP_Y2 = 78;              // Calibration help line 2 Y.
const int CALIB_HELP_Y3 = 86;              // Calibration help line 3 Y.
const int HEALTH_TITLE_X = 3;              // Health title X position.
const int HEALTH_TITLE_Y = 15;             // Health title Y position.
const int HEALTH_ITEM_X = 3;               // Health item X position.
const int HEALTH_ITEM_Y_START = 30;        // Health item start Y.
const int HEALTH_ITEM_Y_STEP = 10;         // Health item line spacing.
const int HEALTH_FOOTER_Y = 112;           // Health footer Y position.
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

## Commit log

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2025-12-28 Fix LCSC Part # for J4 in bom.csv
    Updated the LCSC Part # for J4 in the BOM.
    [bom.csv]
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2026-02-28 Reduce sleep-mode power: MPU6050 sleep, CPU scaling, and minimal sleep face
    - Put MPU6050 into low-power sleep on device sleep entry (mpu.enableSleep)
    and wake it on exit; saves ~3.8 mA during sleep. Guard unchanged (mpuReady).
    - Scale CPU from 240 MHz → 80 MHz on sleep entry (after all I2C settled),
    restore on wake (before any I2C); saves ~30% of CPU power during sleep.
    - Replace the full-width "ZzzZzzZZz..." text on the external OLED with a
    centred 24 px circle face (outline, closed-eye dashes, mouth) and a compact
    "Zzz" tag using u8g2_font_6x10_mf; reduces lit pixels from ~1920 to ~150.
    - Add CPU_FREQ_ACTIVE/SLEEP_MHZ constants; replace EXT_SLEEP_TEXT_X/Y with
    EXT_SLEEP_FACE_C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
    [loop_runtime.cpp, mrfconstants.h]
2026-02-28 Reduce idle polling cadences: film counter, battery gauge, and UI tick
    - LOOP_FILM_COUNTER_IDLE_INTERVAL_MS: 25 ms → 75 ms. Mechanical film
    advance does not require 40 Hz polling when the lever is stationary.
    - LOOP_BATTERY_INTERVAL_MS: 1500 ms → 5000 ms. MAX17048 SoC changes on
    the order of minutes; sub-second polling provides no useful resolution.
    - LOOP_UI_INTERVAL_MS: 33 ms → 50 ms (~30 FPS → ~20 FPS). Hash-based
    dirty checking already prevents redundant I2C draws; reducing the tick
    gate cuts hash computation overhead and the forced-refresh ceiling.
    LOOP_UI_MAIN_REFRESH_MS (100 ms) remains unchanged and is unaffected.
    [mrfconstants.h]
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2026-02-28 Replace spin-poll with light sleep in runSleepTasks()
    The device-sleep loop previously busily polled buttons (25 ms), encoder
    (50 ms), and lens ADC (100 ms) via shouldRunTask() timestamp checks,
    keeping the CPU spinning at 80 MHz between polls (~20-30 mA).
    New behaviour: each iteration of runSleepTasks() calls
    esp_light_sleep_start() with a 100 ms timer wakeup. The CPU drops to
    ~0.8 mA between polls. On wakeup, the cause is dispatched:
    ESP_SLEEP_WAKEUP_GPIO -> button pressed; checkButtons() lets Bounce2
    confirm the press and registerActivity().
    ESP_SLEEP_WAKEUP_TIMER -> timer elapsed; pollSleepWakeEncoder() and
    (or undefined) pollSleepWakeLens()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
    [loop_runtime.cpp, mrfconstants.h]
2026-02-28 Extend runtime sleep state machine test coverage
    Three new test cases in test_runtime_state_machine:
    - test_sleep_mode_off_never_enters_sleep: complements the existing
    MODE_OFF test (which only verified an already-sleeping device wakes).
    Confirms a non-sleeping device never transitions into sleep when the
    timeout is disabled, regardless of idle duration.
    - test_all_timeout_modes_have_correct_boundaries: exercises the exact
    ±1 ms boundary for every configured timeout (15 s, 30 s, 1 m, 1 m 30 s,
    2 m). Uses a fixed "now" with a controlled lastActivityTime per
    iteration to avoid cross-iteration idle accumulation.
    - test_sleep_constants_match_intended_durations: pins the values of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
    [test_main.cpp]
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2026-02-28 refactor: small DRY and clarity improvements
    - Extract advanceMenuStep(maxStep) in inputs.cpp to replace five
    identical config_step increment-and-wrap blocks.
    - Simplify getFirstNonZeroAperture() clamp to max(0, ...).
    - Name the OLED display-off/on raw bytes as OLED_CMD_DISPLAY_OFF/ON
    constants in mrfconstants.h; use them in loop_runtime.cpp.
    - Remove nine redundant zero-assignments from
    initializeSchedulerIfNeeded(): the LoopScheduler struct already
    initialises all timestamp fields to 0.
    [inputs.cpp, loop_runtime.cpp, mrfconstants.h]
2026-02-28 refactor(setfuncs): lift lens state machine statics to named structs
    Define LensSpikeFilterState and LensSnapState in the anonymous
    namespace and replace the four function-local statics in
    getLensSensorReading() and the two in setLensDistance() with
    named instances. Behaviour is unchanged; state is now explicit,
    visible at a glance, and resettable without per-function hacks.
    [setfuncs.cpp]
2026-02-28 refactor(setfuncs): lift LiDAR recovery and light meter statics to named structs
    Define LightMeterSmoothingState in the anonymous namespace and lift
    the LidarRecoveryState function-local static in setDistance() to a
    named namespace-scope instance. Replace all smoothingInitialized /
    smoothedLux locals in setLightMeter() with lightMeterSmoothing members.
    Behaviour is unchanged throughout.
    [setfuncs.cpp]
2026-03-01 fix(sleep): always call checkButtons() regardless of wakeup cause
    GPIO_INTR_LOW_LEVEL fires when a button is pressed (pin goes LOW), but
    the release event (pin goes HIGH) arrives on the next timer wakeup, not
    a GPIO wakeup. The previous switch-case only called checkButtons() on
    GPIO wakeups, so Bounce2's rose() event — which registers activity and
    exits sleep — was never processed. Buttons were silent on wake.
    Fix: call checkButtons() unconditionally before the wakeup-cause
    dispatch, and only run the sensor polls (encoder/lens) when the cause is
    not a GPIO wakeup.
    [loop_runtime.cpp]
2026-03-01 fix(battery): populate bat_per immediately at boot
    Increasing LOOP_BATTERY_INTERVAL_MS from 1.5 s to 5 s left a window
    at startup where bat_per sat at its default 0, showing "0%" until the
    scheduler fired the first update. Call setVoltage() once during setup()
    immediately after the MAX17048 is initialised so the display shows the
    real charge level from the first frame.
    [main.cpp]
2026-03-01 fix(i2c): restore Wire to 400 kHz after display writes
    The SH1107 display was constructed with clkAfter = 1 MHz, which left the
    Wire bus at 1 MHz after every display write. The MAX17048 fuel gauge
    specifies a maximum I2C clock of 400 kHz; at 1 MHz its chip-ID check
    inside begin() fails and batteryGaugeReady is left false.
    Fix: introduce SHARED_I2C_FREQUENCY_HZ = 400 kHz as the clkAfter value
    for the SH1107 constructor. The display still runs at 1 MHz (clkDuring)
    for performance, but Wire is restored to 400 kHz afterwards so the fuel
    gauge, MPU6050, BH1750, and seesaw all see a compatible bus speed.
    [hardware.cpp, mrfconstants.h]
2026-03-01 fix(battery): recover batteryGaugeReady when begin() fails due to 0x36 conflict
    maxlipo.begin() returns false because the Seesaw (also at I2C address
    0x36) ACKs the soft-reset write that MAX17048 deliberately NACKs.
    i2c_dev is still valid after this failure, and the Seesaw's two-byte
    register protocol means it does not participate in MAX17048's
    single-byte register reads — so cellPercent() returns accurate data.
    After a failed begin(), attempt a SOC read and accept the gauge as
    ready if the result is in [0, 100]. This restores the behaviour from
    before the batteryGaugeReady guard was introduced.
    [main.cpp]
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2026-03-14 fix(prefs): use targeted dirty masks in savePrefs() calls
    All cycle functions were calling savePrefs() without a dirty mask,
    defaulting to PREFS_DIRTY_ALL and causing unnecessary full NVS writes.
    Use PREFS_DIRTY_SETTINGS for settings changes to reduce flash wear.
    [cyclefuncs.cpp]
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2026-03-14 Improve calibration UX with progress bar, LED pulse, and clearer guidance
    The calibration screen now shows a progress bar beneath the title,
    a point counter (e.g. "3/7"), and revised help text that explains
    the focus-ring workflow. Error messages are more actionable:
    "Hold lens still and retry" for instability, "Turn ring further
    from camera" for sequence errors. A brief green LED pulse confirms
    each successful capture.
    [inputs.cpp]
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2026-03-15 Replace blocking display fade with non-blocking state machine
    The sleep-entry fade used a blocking for-loop with delay(25) that froze
    the main loop for ~200 ms, preventing button polling and encoder reads.
    Replace with a DisplayFadeState struct that steps brightness down one
    notch per scheduler iteration. Sleep entry is now two-phase: the fade
    runs across successive loop ticks while buttons are still polled, then
    finaliseSleepServices() powers down peripherals once the fade completes.
    [loop_runtime.cpp, mrfconstants.h]
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2026-03-15 Hold calibration error messages on screen for minimum 2 seconds
    Calibration errors (unstable reading, out of sequence) could disappear
    before the user had time to read them. Track a timestamp when the
    error status is set and enforce a 2-second minimum display time:
    - inputs.cpp ignores new capture presses during the hold period
    - interface.cpp auto-clears the error once the hold expires
    - loop_runtime.cpp hashes the timestamp so the UI redraws on expiry
    [globals.h, inputs.cpp, loop_runtime.cpp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]
2026-03-15 Show peripheral name during boot progress bar
    The boot screen now displays which peripheral is being initialised
    beneath the progress bar (e.g. 'LiDAR', 'Peripherals', 'Ready').
    This helps diagnose which step is slow or stuck if boot hangs.
    [main.cpp]
2026-03-15 Add Retry LiDAR option to Health screen
    If the LiDAR sensor failed to initialise at boot, the Health screen
    footer now shows '(R) Retry LiDAR' instead of the usual back action.
    Pressing (R) attempts a fresh lidar.begin() sequence. On success the
    sensor becomes available without a full reboot.
    [inputs.cpp, setfuncs.cpp]
2026-03-15 Add compile-time validation for menu step constants
    Replace bare const int menu step indexes with plain enums that include
    a COUNT sentinel. static_assert checks that _MAX matches COUNT - 1,
    so adding a new menu item without updating the list is caught at
    compile time rather than silently wrapping to the wrong entry.
    [mrfconstants.h]
2026-03-15 Use median-based spread check for calibration inliers
    The previous min-to-max spread check rejected gentle monotonic lens
    drift where every sample was close to the median but the endpoints
    were far apart. Switch to checking max deviation from median instead,
    which is more tolerant of slow directional drift while still rejecting
    genuinely unstable readings.
    Add two regression tests covering the new acceptance and rejection
    behaviour.
    [test_main.cpp]
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2026-03-15 Consolidate three cyclic value helpers into cycleValueWrapping
    cycleSleepTimeoutModeValue, cycleFrameTuningValue, and
    cycleLevelTrimValue all performed the same wrapping increment with
    different bounds. Replace with a single cycleValueWrapping(current,
    step, min, max) function.
    [cyclefuncs.cpp]
2026-03-15 Unify LiDAR display clearing into a single parameterised function
    clearLidarDisplay() in setfuncs.cpp and clearLidarUiForStandby() in
    loop_runtime.cpp did the same thing with different placeholder strings.
    Replace both with clearLidarDisplay(const char *placeholder) and
    remove the duplicate.
    [loop_runtime.cpp, setfuncs.cpp]
2026-03-15 Remove redundant aperture check and duplicate colour reset function
    clampLoadedState() checked apertures[aperture_index] == 0 twice in
    succession — remove the second check.
    resetConfigTextColors() duplicated setMenuItemColors(false) — remove
    it and call setMenuItemColors(false) directly.
    [helpers.cpp]
2026-03-15 Extract markPrefsClean helper and simplify getFocusRadius
    savePrefs (force path) and flushPrefsIfDirty both reset the same five
    prefs-state fields after a write. Extract markPrefsClean() to avoid
    the duplication.
    Simplify getFocusRadius to a single constrain() call, removing
    unnecessary local variables and an outdated comment.
    [helpers.cpp]
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2026-03-15 Replace blocking LED pulse with non-blocking timed turn-off
    The calibration capture confirmation used delay(80) to flash the LED
    green, blocking the main loop. Instead, set the LED on immediately
    and record a timestamp; the main scheduler loop turns it off once
    CALIB_LED_PULSE_MS has elapsed. Placed in runAwakeTasks() so it
    fires regardless of UI mode, preventing the LED from sticking on
    when the state transitions away from calibration.
    [globals.h, inputs.cpp, loop_runtime.cpp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]
2026-03-15 Revert "Replace blocking LED pulse with non-blocking timed turn-off"
    This reverts commit 39527042a9b4bc5eda495d516026ac550fb2054a.
    [globals.h, inputs.cpp, loop_runtime.cpp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]
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2026-03-15 Add Factory Reset option to System Health screen
    Long-press R on the Health screen enters a confirmation screen.
    Pressing R confirms: clears the NVS preferences namespace and
    reboots the device, which causes loadPrefs() to detect missing
    schema and load all defaults. Pressing L cancels back to Health.
    The Health footer now shows "(R long) Factory Reset" alongside
    the existing Back / Retry LiDAR controls.
    [globals.h, helpers.cpp, inputs.cpp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]
2026-03-15 Enlarge out-of-focus ring and smooth radius animation
    Increase FOCUS_RADIUS_MAX from 30 to 40px and FOCUS_RING_THICKNESS_MAX
    from 3 to 5px so the ring is more visually prominent when out of focus.
    Add EMA smoothing on the focus radius itself (alpha 0.15) to damp the
    twitchy oscillation near focus caused by small LiDAR/lens fluctuations.
    Previously only the ring thickness was smoothed; now both radius and
    thickness transition gradually.
    [mrfconstants.h]
2026-03-15 Restore LED colour after calibration capture pulse
    The green flash on successful capture was turning the LED off
    afterwards, losing the progress colour set by the external UI.
    Instead, invalidate prev_frame_progress so the next external UI
    draw re-applies the correct colour (blue idle or red-green gradient).
    [inputs.cpp]
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2026-03-15 Show full-screen success message on calibration complete
    Replace the small status-line "Calibration complete!" with a
    dedicated full-screen drawCalibCompleteUI() showing "Calibration
    complete!" centred on a cleared display. After the triple green
    LED pulse, hold the success screen for 1.5 seconds before
    returning to the Lens settings menu.
    [inputs.cpp, mrfconstants.h]
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2026-03-19 Use library median-filtered distance for jitter reduction
    Substitute the raw primary distance with the library's 10-frame
    median when both are valid. Reduces display jitter at near/mid
    range without affecting far-range or invalid-reading paths.
    [setfuncs.cpp]
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2026-03-19 Reset prev_distance on display clear to prevent stale temporal penalty
    Without this reset, the first valid reading after a dropout is penalised
    by the temporal jump from the stale previous distance, suppressing
    recovery confidence at the range boundary.
    [setfuncs.cpp]
2026-03-20 Update DTS6012M_UART library to v2.5.3 and bump firmware to 10.3.2
    Upgrade from v2.2.1 to v2.5.3. Key library improvements used:
    - newDataAvailable() edge-triggered flag and getFilteredDistance()
    median filter for jitter reduction
    - setFrameRate() to set 50 fps for longer integration time
    - getFirmwareVersion() displayed on health screen
    setFrameRate is called only at init (sensor retains the setting);
    calling it during recovery via sendOneShot destabilises the stream.
    [main.cpp, setfuncs.cpp]
2026-03-30 Fix lightmeter buffer overflow and update exposure display format
    Uncapped dtostrf into a 10-byte buffer caused overflow when exposure
    time reached very large second values. Cap added at 25 minutes.
    Display now shows seconds in 0.5s increments (1, 1.5, 2, 2.5 …) and
    switches to minutes+seconds (e.g. 1m30s) at one minute.
    Bump firmware version to 10.3.3.
    [mrfconstants.h, test_main.cpp]
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2026-03-30 Retune LiDAR accuracy tiers to 2m/5m/7m/8m+ gradient
    Super accurate ≤2m, less accurate 2–5m, even less 5–7m, just get
    a value at 8m+. Shifts range boundaries and tightens the gradient
    across intensity gates, SNR targets, and prior penalty scaling.
    [mrfconstants.h]
2026-03-31 Reduce focus ring granularity to 5cm steps
    Compare lidar and lens distances in 5cm increments so the focus ring
    locks when the displayed values visually match, without snapping too
    early. Bump firmware to 10.3.5.
    [helpers.cpp, mrfconstants.h]
2026-04-02 Fix LiDAR idle timeout not persisting and update sleep defaults
    NVS key "lidar_idle_to_mode" (18 chars) exceeded ESP32's 15-char
    limit, causing silent read/write failures. Shortened to
    "lidar_idle_to". Changed default sleep timeout to 1m30s and
    lidar idle to 1m so the standby window is observable.
    [helpers.cpp, mrfconstants.h]
2026-04-15 Add visual focus reticle offset adjustment
    New UI screen (Setup > UI Settings > Focus reticle) lets users
    visually align the reticle to the camera's optical centre.
    Step 1 adjusts horizontal position, step 2 adjusts vertical.
    Long press either button advances/saves. Offsets persist to NVS.
    - Convert RETICLE_OFFSET_X/Y from compile-time defines to
    user-configurable globals with NVS persistence.
    - Add ReticleAdjust UiMode with two-step input handling.
    - Add left-button long press detection (guarded, one-shot).
    - Guard right-button long press to prevent repeat firing.
    - Bump firmware to 10.4.0.
    [globals.h, helpers.cpp, inputs.cpp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]
2026-04-20 Refactor button long-press handling and fix reticle draw colour
    - Extract handleLeftButtonLongPress() to mirror the right-button pattern,
    removing the inline mode guard from checkButtons().
    - Fix right-button long press firing repeatedly on every loop iteration;
    both buttons now fire exactly once per hold via handled flags.
    - Use WHITE instead of INVERSE for the reticle dot in drawReticleAdjustUI(),
    since the display is cleared before drawing.
    - Document the long-press fix in CHANGELOG under 10.4.0.
    [inputs.cpp]
2026-04-21 Add near-distance precision, display brightness, and horizon toggle (v10.4.5)
    - Show two decimal places for distances below 2m (e.g. 1.85m).
    - Add Auto/Manual display brightness to Setup > UI Settings:
    Auto scales contrast with ambient lux (BH1750), with user-settable
    top brightness 50-100%; Manual sets a fixed level 5-100%.
    Brightness re-evaluated every second while awake.
    - Add Horizon line On/Off toggle to Setup > UI Settings.
    - All three settings persisted to NVS with graceful defaults.
    [cyclefuncs.cpp, globals.h, helpers.cpp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]
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2026-05-02 Fix 6x9 frame spacing, light meter overexposure, and improve LiDAR near-range accuracy
    6x9 frame spacing: reduce interframe encoder ticks by 1-2 per advance (cumulative
    9 ticks at frame 8, recovering ~21mm -- approximately 1/4 frame).
    Light meter: lower calibration constant K from 20 to 7 to correct ~1.5-stop
    overexposure on the BH1750 as installed.
    LiDAR near-range accuracy: reduce frame rate from 50fps to 20fps for 2.5x more
    integration time per measurement; add 12% temporal blend at high confidence below
    2m to reduce single-frame noise.
    Also fixes a stale test assertion left over from the v10.4.5 near-distance
    precision feature (150cm now correctly asserted as "1.50m").
    [mrfconstants.h, test_main.cpp]
2026-05-03 Address review: ISO-standard K, LiDAR FPS in recovery, 9x3 spacing fix
    - Restore K to the ISO-standard 12.5; introduce LIGHTMETER_LUX_CAL_SCALE=1.77
    to absorb the BH1750 mounting bias separately. Mathematically equivalent to
    the prior K=7 fix but documents the two effects independently.
    - Centralise LiDAR sensor settings in applyLidarCalibrationProfile() so the
    frame rate is re-applied after recovery, not only at boot.
    - Apply the same interframe-spacing correction to 9x3 (it shared the
    out-of-tolerance sensor array with 6x9).
    [mrfconstants.h, setfuncs.cpp, test_main.cpp]
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2026-05-03 Tune LiDAR config and remove dead residual-correction code
    - Revert LIDAR_FRAME_RATE_FPS to 50 (library standard floor). The new
    near-range temporal blend now provides the noise reduction that the
    earlier 20fps over-rotation was trying to achieve, with 2.5x better
    display responsiveness and the same noise floor.
    - Raise LIDAR_LIBRARY_MIN_INTENSITY_THRESHOLD from 20 to 40 to match
    LIDAR_FUSION_MIN_INTENSITY. The library's quality enum now reflects
    the same intensity bar the rest of the pipeline uses.
    - Remove LIDAR_RESIDUAL_* table and applyLidarResidualCorrectionCm. The
    delta table was all zeros and the calibration approach it supports is
    not on the roadmap. The remaining power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
    [mrfconstants.h]
2026-05-03 Add user-adjustable LiDAR distance offset to Setup > UI Settings
    Converts LIDAR_LIBRARY_DISTANCE_OFFSET_MM from a compile-time constant
    to a runtime preference (lidar_distance_offset_mm) persisted to NVS.
    - New menu item between LiDAR idle and Focus reticle, range 0-800mm in
    10mm steps (default 400mm).
    - Cycle handler pushes the new value to the sensor immediately via
    lidar.setDistanceOffset() so the live distance readout reflects the
    change without waiting for reboot.
    - applyLidarCalibrationProfile() now pulls from the runtime variable
    instead of the constant, keeping boot-time and recovery paths in
    sync with whatever the user has configured.
    [cyclefuncs.cpp, globals.h, helpers.cpp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]
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2026-05-03 Relax LiDAR near-range gating after field report of bright-sun drop-outs
    User report: at eye level in full sun, no LiDAR read at 2m even though
    the same 2m on the ground (camera body shading the sensor) reads fine.
    Two contributing factors, both relaxed:
    - Revert LIDAR_LIBRARY_MIN_INTENSITY_THRESHOLD from 40 back to 20. My
    earlier 'single source of truth' alignment was wrong. The library's
    threshold gates *quality classification* (with inverse-square distance
    scaling); our pipeline's LIDAR_FUSION_MIN_INTENSITY=40 gates
    *acceptance*. They serve different purposes; tightening both at once
    caused weak-but-valid returns to be double-rejected when ambient light
    was high.
    - Drop LID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
    [mrfconstants.h]
2026-05-03 Add lens-prior plausibility gate for LiDAR (mrf2-nwn)
    When the lens is focused at close range (<=2m), the LiDAR's single beam
    can miss the framed subject due to parallax and find distant background
    instead. Without help, the system reports either nothing or a wildly
    wrong distance.
    Use the lens focus distance as ground truth when it disagrees by more
    than 200cm overshoot — almost certainly a beam-miss. Hold the previous
    valid value instead of displaying the bad reading. Asymmetric: only
    reject when LiDAR is much *farther* than the lens (the failure mode);
    LiDAR-closer-than-lens is allowed (transient occluders, fast subjects).
    After 8 consecutive rejections, fall through and accept the Li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
    [mrfconstants.h, setfuncs.cpp, test_main.cpp]
2026-05-03 Add subject-stable confidence boost for LiDAR (mrf2-yrj)
    When the LiDAR has been reading the same value (within 5cm) for 5+
    consecutive frames, treat it as 'locked on a stable subject' and add
    a +10 confidence boost (clamped at 95). The temporal blend then prefers
    the locked value more strongly, smoothing over occasional noise without
    sacrificing responsiveness when the subject genuinely moves.
    Streak resets on:
    - LiDAR dropout (chosen candidate invalid)
    - Plausibility-gate rejection (mrf2-nwn — already accepted, this commit
    hooks into the existing reject path)
    - Reading deviates by more than LIDAR_STABLE_DELTA_CM
    Pure helper applyStableConfidenceBoost() with three unit-test cases
    cove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
    [mrfconstants.h, setfuncs.cpp, test_main.cpp]
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
